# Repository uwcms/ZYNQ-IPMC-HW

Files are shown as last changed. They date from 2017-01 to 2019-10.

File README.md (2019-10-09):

! The ZYNQ-IPMC Software Framework resides [here](https://github.com/uwcms/IPMC).

# ZYNQ-IPMC Official Hardware Repository
Department of Physics, University of Wisconsin-Madison, USA

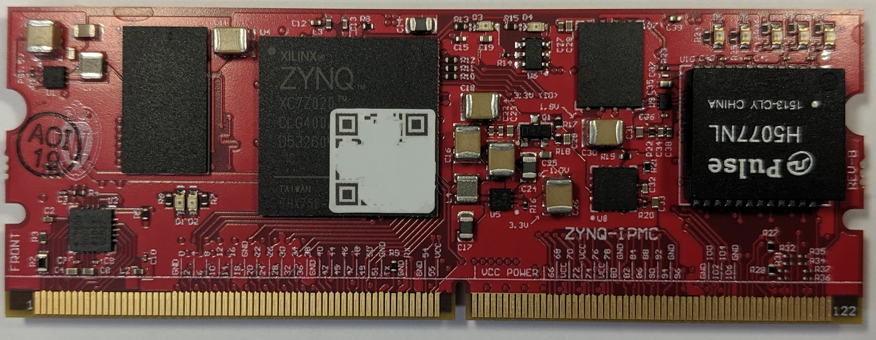
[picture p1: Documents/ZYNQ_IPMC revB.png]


<!-- TOC depthFrom:1 depthTo:6 withLinks:1 updateOnSave:1 orderedList:0 -->

- [ZYNQ-IPMC Official Hardware Repository](#zynq-ipmc-official-hardware-repository)
	- [1. Overview](#1-overview)
	- [2. Altium Symbol and Footprint Library](#2-altium-symbol-and-footprint-library)
	- [3. Picking between Zynq-7014S and Zynq-7020](#3-picking-between-zynq-7014s-and-zynq-7020)
	- [4. Bring-up and Testing](#4-bring-up-and-testing)
	- [5. Fabrication and Assembly](#5-fabrication-and-assembly)
		- [5.1. Fabrication Package](#51-fabrication-package)
		- [5.2. Assembly Package](#52-assembly-package)
	- [6. Disclaimer and Licensing](#6-disclaimer-and-licensing)

<!-- /TOC -->

## 1. Overview

ZYNQ-IPMC is a high versatile open-source self-contained Intelligent Platform
Management Controller (IPMC) in a miniDIMM-244 mezzanine form factor with
extended monitoring features targeted for Advance Telecommunications Computing
Architecture (ATCA) applications in accordance with the PICMG 3.x standard.

A Xilinx Zynq-7000 System-on-Chip (SoC) powers the ZYNQ-IPMC. Coupled with 256Mbytes of DDR3, fast
ADCs and a large number of GPIOs that can take any standard protocol natively,
forms an ideal solution to monitor and log voltages, currents, temperatures and others
metrics in ATCA applications.

**For detailed information of the hardware check the PDF datasheet
[here](Documents/ZYNQ-IPMC%20hw%20datasheet.pdf).**

## 2. Altium Symbol and Footprint Library

The Altium project with the ZYNQ-IPMC symbol and footprint can be found
[here](AltiumLib/).

## 3. Picking between Zynq-7014S and Zynq-7020

Both Zynq-7014S and Zynq-7020 are pin-compatible and can be assembled in the ZYNQ-IPMC.
The primary different is that the Zynq-7014S is a single core and has roughly
20% less resources than the Zynq-7020. The Zynq-7014S is also cheaper.

ZYNQ-IPMC framework only uses a single-core and won't benefit from an additional
core nor FPGA resources. Therefore, the Zynq-7014S is recommended for most applications.

From tests and experimentation a medium to high populated ZYNQ-IPMC solution requires
around 25% of resources from a Zynq-7020.

## 4. Bring-up and Testing

Standard electrical checks for hardware bring-up should be followed (e.g. visual
inspection, ohm-meter tests, voltage levels, etc.) before inserting the IPMC on a
carrier.

The [ZYNQ-IPMC Test Board](TestBoard) can be used for these tests and additional
connectivity tests.

## 5. Fabrication and Assembly

All files required to fabrication and assembly are included in this repository.
They can be found at [here](Project%20Outputs%20for%20ZYNQ_IPMC/revB1).

Recommendations on how to prepare packages for each fabrication step is below.

### 5.1. Fabrication Package

The following folders and files are recommended to be sent the PCB fabrication house:
 - Gerbers (either Gerber or GerberX2)
 - NC Drill
 - Test Points
 - PCB drawings (ZYNQ_IPMC-PCB.PDF)
 - Drill drawings (ZYNQ-IPMC-DrillDrawing.PDF)

### 5.2. Assembly Package

The following folders and files are recommended to be sent the assembly house:
 - Gerbers (either Gerber or GerberX2)
 - Bill of Materials (BOM)
 - Pick and Place
 - Assembly drawings (ZYNQ_IPMC-Assembly.PDF)

## 6. Disclaimer and Licensing

The project is distributed as-in under the MIT license agreement as seen [here](LICENSE.md).

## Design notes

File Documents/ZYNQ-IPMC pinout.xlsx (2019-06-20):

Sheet: Pin Assignment
Name | Pin | Pin | Name | Name | Pin | Pin | Name
GND | 1 | 123 | GND | VCC3.3 | 66 | 188 | GPIO_58 | Pin assignment as seen from the IPMC
+12V_SENSE | 2 | 124 | ADC-B_IN0 | VCC3.3 | 67 | 189 | GPIO_59
ADC-A_IN1 | 3 | 125 | ADC-B_IN1 | VCC3.3 | 68 | 190 | GND | Revision: | 1.1
GND | 4 | 126 | GND | VCC3.3 | 69 | 191 | GPIO_60
ADC-A_IN2 | 5 | 127 | ADC-B_IN2 | VCC3.3 | 70 | 192 | GPIO_61 | Bank 13
ADC-A_IN3 | 6 | 128 | ADC-B_IN3 | VCC3.3 | 71 | 193 | GND | Bank 34
ADC-A_IN4 | 7 | 129 | ADC-B_IN4 | VCC3.3 | 72 | 194 | GPIO_62 | Bank 35
ADC-A_IN5 | 8 | 130 | ADC-B_IN5 | VCC3.3 | 73 | 195 | GPIO_63
GND | 9 | 131 | GND | VCC3.3 | 74 | 196 | GND
ADC-A_IN6 | 10 | 132 | ADC-B_IN6 | VCC3.3 | 75 | 197 | GPIO_64
ADC-A_IN7 | 11 | 133 | ADC-B_IN7 | VCC3.3 | 76 | 198 | GPIO_65
GND | 12 | 134 | GND | VCC3.3 | 77 | 199 | GND
NC | 13 | 135 | NC | GPIO_66 | 78 | 200 | GPIO_67
NC | 14 | 136 | NC | GPIO_68 | 79 | 201 | GPIO_69
NC | 15 | 137 | NC | VCC3.3 | 80 | 202 | GND
NC | 16 | 138 | NC | GPIO_70 | 81 | 203 | GPIO_71
NC | 17 | 139 | NC | GPIO_72 | 82 | 204 | GPIO_73
NC | 18 | 140 | NC | VCC3.3 | 83 | 205 | GND
NC | 19 | 141 | NC | GPIO_74 | 84 | 206 | GPIO_75
NC | 20 | 142 | NC | GPIO_76 | 85 | 207 | GPIO_77
NC | 21 | 143 | NC | VCC3.3 | 86 | 208 | GND
NC | 22 | 144 | NC | GPIO_78 | 87 | 209 | GPIO_79
GND | 23 | 145 | GND | GPIO_80 | 88 | 210 | GPIO_81
GPIO_0 | 24 | 146 | GPIO_1 | GND | 89 | 211 | GND
GPIO_2 | 25 | 147 | GPIO_3 | GPIO_82 | 90 | 212 | GPIO_83
GPIO_4 | 26 | 148 | GPIO_5 | GPIO_84 | 91 | 213 | GPIO_85
GPIO_6 | 27 | 149 | GPIO_7 | GPIO_86 | 92 | 214 | GPIO_87
GPIO_8 | 28 | 150 | GPIO_9 | GPIO_88 | 93 | 215 | GPIO_89
GPIO_10 | 29 | 151 | GPIO_11 | GPIO_90 | 94 | 216 | GPIO_91
GPIO_12 | 30 | 152 | GPIO_13 | GPIO_92 | 95 | 217 | GPIO_93
GPIO_14 | 31 | 153 | GPIO_15 | GPIO_94 | 96 | 218 | GPIO_95
GPIO_16 | 32 | 154 | GPIO_17 | GND | 97 | 219 | GND
GPIO_18 | 33 | 155 | GPIO_19 | GPIO_96 | 98 | 220 | GPIO_97
GND | 34 | 156 | GND | NC | 99 | 221 | GPIO_98
GPIO_20 | 35 | 157 | GPIO_21 | NC | 100 | 222 | GND
GPIO_22 | 36 | 158 | GPIO_23 | NC | 101 | 223 | EXT_RST_N
GPIO_24 | 37 | 159 | GPIO_25 | GND | 102 | 224 | GPIO_99
GPIO_26 | 38 | 160 | GPIO_27 | GPIO_100 | 103 | 225 | GPIO_101
GPIO_28 | 39 | 161 | GPIO_29 | GPIO_102 | 104 | 226 | GPIO_103
GPIO_30 | 40 | 162 | GPIO_31 | GPIO_104 | 105 | 227 | GPIO_105
GPIO_32 | 41 | 163 | GPIO_33 | GPIO_106 | 106 | 228 | GPIO_107
GPIO_34 | 42 | 164 | GPIO_35 | GND | 107 | 229 | GPIO_108
GPIO_36 | 43 | 165 | GPIO_37 | M-JTAG_TRST | 108 | 230 | GND
GPIO_38 | 44 | 166 | GPIO_39 | M-JTAG_TDO | 109 | 231 | M-JTAG_TCK
GND | 45 | 167 | GND | M-JTAG_TMS | 110 | 232 | M-JTAG_TDI
GPIO_40 | 46 | 168 | GPIO_41 | GND | 111 | 233 | GND
GPIO_42 | 47 | 169 | GPIO_43 | Z-JTAG_TDO | 112 | 234 | Z-JTAG_TCK
GPIO_44 | 48 | 170 | GND | Z-JTAG_TMS | 113 | 235 | Z-JTAG_TDI
GPIO_45 | 49 | 171 | GB_A_P | GND | 114 | 236 | GND
GPIO_46 | 50 | 172 | GB_A_N | HA0 | 115 | 237 | HA1
GPIO_47 | 51 | 173 | GND | HA2 | 116 | 238 | HA3
GPIO_48 | 52 | 174 | GB_B_P | HA4 | 117 | 239 | HA5
GPIO_49 | 53 | 175 | GB_B_N | HA6 | 118 | 240 | HA7
GPIO_50 | 54 | 176 | GND | GND | 119 | 241 | GND
GPIO_51 | 55 | 177 | GB_C_P | IPMB-A_SCL | 120 | 242 | IPMB-B_SCL
GND | 56 | 178 | GB_C_N | IPMB-A_SDA | 121 | 243 | IPMB-B_SDA
UART_TX | 57 | 179 | GND | GND | 122 | 244 | GND
NC | 58 | 180 | GB_D_P
GND | 59 | 181 | GB_D_N
UART_RX | 60 | 182 | GND
NC | 61 | 183 | GPIO_52
GND | 62 | 184 | GPIO_53
GPIO_54 | 63 | 185 | GND
GPIO_55 | 64 | 186 | GPIO_56
VCC3.3 | 65 | 187 | GPIO_57

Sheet: GPIOs
GPIO Number | GPIO Pin | Bank | Zynq Pin | Clock input | GPIO | Pin
0 | 24 | 13 | U5 | - | 0 | 0
1 | 146 | 34 | P14 | - | 0 | 1
2 | 25 | 13 | T5 | - | 0 | 2
3 | 147 | 34 | T10 | - | 0 | 3
4 | 26 | 13 | U8 | - | 0 | 4
5 | 148 | 34 | T11 | - | 0 | 5
6 | 27 | 13 | U9 | - | 0 | 6
7 | 149 | 34 | T12 | - | 0 | 7
8 | 28 | 13 | W8 | - | 0 | 8
9 | 150 | 34 | T14 | - | 0 | 9
10 | 29 | 13 | W9 | - | 0 | 10
11 | 151 | 34 | U12 | - | 0 | 11
12 | 30 | 13 | W10 | - | 0 | 12
13 | 152 | 34 | T15 | - | 0 | 13
14 | 31 | 13 | W11 | - | 0 | 14
15 | 153 | 34 | V12 | - | 0 | 15
16 | 32 | 13 | Y11 | - | 0 | 16
17 | 154 | 34 | W13 | - | 0 | 17
18 | 33 | 13 | Y12 | - | 0 | 18
19 | 155 | 34 | V13 | - | 0 | 19
20 | 35 | 34 | R14 | - | 0 | 20
21 | 157 | 34 | W18 | - | 0 | 21
22 | 36 | 34 | W15 | - | 0 | 22
23 | 158 | 34 | V16 | - | 0 | 23
24 | 37 | 34 | T16 | - | 0 | 24
25 | 159 | 34 | T17 | - | 0 | 25
26 | 38 | 34 | U17 | - | 0 | 26
27 | 160 | 34 | Y18 | - | 0 | 27
28 | 39 | 34 | Y14 | - | 0 | 28
29 | 161 | 34 | W16 | - | 0 | 29
30 | 40 | 34 | W14 | - | 0 | 30
31 | 162 | 34 | V17 | - | 0 | 31
32 | 41 | 34 | U14 | Limited | 1 | 0
33 | 163 | 34 | W19 | - | 1 | 1
34 | 42 | 34 | Y16 | - | 1 | 2
35 | 164 | 34 | Y19 | - | 1 | 3
36 | 43 | 34 | V15 | - | 1 | 4
37 | 165 | 34 | V18 | - | 1 | 5
38 | 44 | 34 | Y17 | - | 1 | 6
39 | 166 | 34 | W20 | - | 1 | 7
40 | 46 | 34 | U15 | Limited | 1 | 8
41 | 168 | 13 | W6 | - | 1 | 9
42 | 47 | 34 | U18 | Yes | 1 | 10
43 | 169 | 13 | V6 | - | 1 | 11
44 | 48 | 34 | P19 | Yes | 1 | 12
45 | 49 | 34 | N18 | Yes | 1 | 13
46 | 50 | 34 | N20 | Limited | 1 | 14
47 | 51 | 34 | U19 | Yes | 1 | 15
48 | 52 | 34 | P20 | Limited | 1 | 16
49 | 53 | 34 | V20 | - | 1 | 17
50 | 54 | 34 | U20 | - | 1 | 18
51 | 55 | 34 | T20 | - | 1 | 19
52 | 183 | 13 | V10 | - | 1 | 20
53 | 184 | 13 | V11 | - | 1 | 21
54 | 63 | 13 | Y13 | - | 1 | 22
55 | 64 | 34 | R16 | - | 1 | 23
56 | 186 | 34 | R17 | - | 1 | 24
57 | 187 | 34 | R18 | - | 1 | 25
58 | 188 | 34 | N17 | - | 1 | 26
59 | 189 | 34 | P18 | - | 1 | 27
60 | 191 | 34 | P15 | - | 1 | 28
61 | 192 | 34 | P16 | - | 1 | 29
62 | 194 | 34 | T19 | - | 1 | 30
63 | 195 | 34 | R19 | - | 1 | 31
64 | 197 | 35 | N15 | - | 2 | 0
65 | 198 | 35 | N16 | - | 2 | 1
66 | 78 | 35 | M14 | - | 2 | 2
67 | 200 | 35 | M15 | - | 2 | 3
68 | 79 | 35 | M17 | - | 2 | 4
69 | 201 | 35 | M18 | - | 2 | 5
70 | 81 | 35 | M19 | - | 2 | 6
71 | 203 | 35 | M20 | - | 2 | 7
72 | 82 | 35 | L14 | - | 2 | 8
73 | 204 | 35 | L15 | - | 2 | 9
74 | 84 | 35 | L16 | Limited | 2 | 10
75 | 206 | 35 | L17 | Limited | 2 | 11
76 | 85 | 35 | L20 | - | 2 | 12
77 | 207 | 35 | L19 | - | 2 | 13
78 | 87 | 35 | K14 | - | 2 | 14
79 | 209 | 35 | J14 | - | 2 | 15
80 | 88 | 35 | K17 | Yes | 2 | 16
81 | 210 | 35 | K16 | - | 2 | 17
82 | 90 | 35 | K18 | Yes | 2 | 18
83 | 212 | 35 | G14 | - | 2 | 19
84 | 91 | 35 | J19 | - | 2 | 20
85 | 213 | 35 | K19 | - | 2 | 21
86 | 92 | 35 | J16 | - | 2 | 22
87 | 214 | 35 | J15 | - | 2 | 23
88 | 93 | 35 | J20 | - | 2 | 24
89 | 215 | 35 | H20 | - | 2 | 25
90 | 94 | 35 | J18 | - | 2 | 26
91 | 216 | 35 | H18 | - | 2 | 27
92 | 95 | 35 | H17 | Yes | 2 | 28
93 | 217 | 35 | H16 | Yes | 2 | 29
94 | 96 | 35 | H15 | - | 2 | 30
95 | 218 | 35 | G15 | - | 2 | 31
96 | 98 | 35 | G17 | - | 3 | 0
97 | 220 | 35 | G18 | - | 3 | 1
98 | 221 | 35 | G19 | - | 3 | 2
99 | 224 | 35 | G20 | - | 3 | 3
100 | 103 | 35 | F16 | - | 3 | 4
101 | 225 | 35 | F20 | - | 3 | 5
102 | 104 | 35 | F17 | - | 3 | 6
103 | 226 | 35 | E18 | - | 3 | 7
104 | 105 | 35 | D18 | - | 3 | 8
105 | 227 | 35 | E19 | - | 3 | 9
106 | 106 | 35 | D19 | - | 3 | 10
107 | 228 | 35 | F19 | - | 3 | 11
108 | 229 | 35 | D20 | - | 3 | 12

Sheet: Mapping
GPIO Number | GPIO Pin | Bank | Zynq Pin | Clock input | GPIO Number | GPIO Pin | Bank | Zynq Pin | Clock input
0 | 24 | 13 | U5 | - | 55 | 64 | 34 | R16 | -
1 | 146 | 34 | P14 | - | 56 | 186 | 34 | R17 | -
2 | 25 | 13 | T5 | - | 57 | 187 | 34 | R18 | -
3 | 147 | 34 | T10 | - | 58 | 188 | 34 | N17 | -
4 | 26 | 13 | U8 | - | 59 | 189 | 34 | P18 | -
5 | 148 | 34 | T11 | - | 60 | 191 | 34 | P15 | -
6 | 27 | 13 | U9 | - | 61 | 192 | 34 | P16 | -
7 | 149 | 34 | T12 | - | 62 | 194 | 34 | T19 | -
8 | 28 | 13 | W8 | - | 63 | 195 | 34 | R19 | -
9 | 150 | 34 | T14 | - | 64 | 197 | 35 | N15 | -
10 | 29 | 13 | W9 | - | 65 | 198 | 35 | N16 | -
11 | 151 | 34 | U12 | - | 66 | 78 | 35 | M14 | -
12 | 30 | 13 | W10 | - | 67 | 200 | 35 | M15 | -
13 | 152 | 34 | T15 | - | 68 | 79 | 35 | M17 | -
14 | 31 | 13 | W11 | - | 69 | 201 | 35 | M18 | -
15 | 153 | 34 | V12 | - | 70 | 81 | 35 | M19 | -
16 | 32 | 13 | Y11 | - | 71 | 203 | 35 | M20 | -
17 | 154 | 34 | W13 | - | 72 | 82 | 35 | L14 | -
18 | 33 | 13 | Y12 | - | 73 | 204 | 35 | L15 | -
19 | 155 | 34 | V13 | - | 74 | 84 | 35 | L16 | Limited
20 | 35 | 34 | R14 | - | 75 | 206 | 35 | L17 | Limited
21 | 157 | 34 | W18 | - | 76 | 85 | 35 | L20 | -
22 | 36 | 34 | W15 | - | 77 | 207 | 35 | L19 | -
23 | 158 | 34 | V16 | - | 78 | 87 | 35 | K14 | -
24 | 37 | 34 | T16 | - | 79 | 209 | 35 | J14 | -
25 | 159 | 34 | T17 | - | 80 | 88 | 35 | K17 | Yes
26 | 38 | 34 | U17 | - | 81 | 210 | 35 | K16 | -
27 | 160 | 34 | Y18 | - | 82 | 90 | 35 | K18 | Yes
28 | 39 | 34 | Y14 | - | 83 | 212 | 35 | G14 | -
29 | 161 | 34 | W16 | - | 84 | 91 | 35 | J19 | -
30 | 40 | 34 | W14 | - | 85 | 213 | 35 | K19 | -
31 | 162 | 34 | V17 | - | 86 | 92 | 35 | J16 | -
32 | 41 | 34 | U14 | Limited | 87 | 214 | 35 | J15 | -
33 | 163 | 34 | W19 | - | 88 | 93 | 35 | J20 | -
34 | 42 | 34 | Y16 | - | 89 | 215 | 35 | H20 | -
35 | 164 | 34 | Y19 | - | 90 | 94 | 35 | J18 | -
36 | 43 | 34 | V15 | - | 91 | 216 | 35 | H18 | -
37 | 165 | 34 | V18 | - | 92 | 95 | 35 | H17 | Yes
38 | 44 | 34 | Y17 | - | 93 | 217 | 35 | H16 | Yes
39 | 166 | 34 | W20 | - | 94 | 96 | 35 | H15 | -
40 | 46 | 34 | U15 | Limited | 95 | 218 | 35 | G15 | -
41 | 168 | 13 | W6 | - | 96 | 98 | 35 | G17 | -
42 | 47 | 34 | U18 | Yes | 97 | 220 | 35 | G18 | -
43 | 169 | 13 | V6 | - | 98 | 221 | 35 | G19 | -
44 | 48 | 34 | P19 | Yes | 99 | 224 | 35 | G20 | -
45 | 49 | 34 | N18 | Yes | 100 | 103 | 35 | F16 | -
46 | 50 | 34 | N20 | Limited | 101 | 225 | 35 | F20 | -
47 | 51 | 34 | U19 | Yes | 102 | 104 | 35 | F17 | -
48 | 52 | 34 | P20 | Limited | 103 | 226 | 35 | E18 | -
49 | 53 | 34 | V20 | - | 104 | 105 | 35 | D18 | -
50 | 54 | 34 | U20 | - | 105 | 227 | 35 | E19 | -
51 | 55 | 34 | T20 | - | 106 | 106 | 35 | D19 | -
52 | 183 | 13 | V10 | - | 107 | 228 | 35 | F19 | -
53 | 184 | 13 | V11 | - | 108 | 229 | 35 | D20 | -
54 | 63 | 13 | Y13 | -
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

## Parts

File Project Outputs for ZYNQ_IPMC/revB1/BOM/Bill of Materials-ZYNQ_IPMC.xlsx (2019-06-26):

Comment | Quantity | Designator | Manufacturer | Part | Footprint | Value | Rating | Tolerance | Rated Current | INVKEY | Note | Description
? | 12 | C1, C11, C16, C18, C20, C26, C30, C61, C64, C65, C67, C68 | Murata | GRM32ER60J107ME20L | C1210_IPC_H | 100uF | 6.3V |  |  | CP1210-100UF-6.3V-20% |  | Capacitor
? | 2 | C2, C32 | Murata | GRM155R71C473KA01D | C0402_IPC_H | 47nF | 16V |  |  | CP0402-47nf-16V-10% |  | Capacitor
? | 34 | C3, C7, C9, C10, C36, C37, C40, C41, C43, C45, C118, C119, C120, C121, C122, C123, C124, C125, C126, C129, C130, C131, C132, C133, C134, C135, C136, C137, C138, C140, C142, C143, C144, C149 | Murata | GRM033R60J104KE19D | C0201_IPC_H | 0.1uF | 6.3V |  |  | CP0201-0.1UF-6.3V-10% |  | Capacitor
? | 22 | C4, C5, C8, C19, C23, C25, C28, C29, C31, C33, C58, C59, C63, C109, C127, C128, C139, C141, C145, C146, C147, C148 | Murata | GRM155R60J106ME44D | C0402_IPC_H | 10uF | 6.3V |  |  | CP0402-10UF-6V3-20% |  | Capacitor
? | 5 | C6, C14, C17, C24, C74 | TDK | C2012X5R0J476M125AC | C0805_M | 47uF | 6.3V |  |  | CP0805-47UF-6.3V |  | Capacitor
? | 20 | C12, C15, C27, C34, C38, C39, C48, C49, C51, C52, C53, C57, C60, C62, C66, C91, C95, C110, C111, C117 | Murata | GRM155R71C104KA88D | C0402_IPC_H | 0.1uF | 16V |  |  | CP0402-0.1UF-16V-10% |  | Capacitor
? | 30 | C13, C21, C22, C69, C72, C73, C76, C78, C79, C81, C83, C85, C86, C88, C89, C92, C93, C96, C97, C98, C99, C100, C102, C103, C106, C108, C112, C113, C114, C116 | Murata | GRM155R60J474KE19D | C0402_IPC_H | 0.47uF | 6.3V |  |  | CP0402-0.47UF-6V3-10% |  | Capacitor
? | 3 | C35, C50, C54 | AVX | 0402YD475MAT2A | C0402_IPC_H | 4.7uF | 16V |  |  | CP0402-4.7uf-16V-20% |  | Capacitor
? | 3 | C42, C44, C46 | TDK | C0603X7R1E471K030BA | C0201_IPC_H | 470pF | 25V |  |  | CP0201-470PF-25V-10% |  | Capacitor
? | 1 | C47 | Murata | GRM155R72A102KA01D | C0402_IPC_H | 1000pF | 100V |  |  | CP0402-1000PF-100V-10% |  | Capacitor
? | 2 | C55, C56 | Murata | GJM0335C0J270JB01D | C0201_IPC_H | 27pF | 6.3V |  |  | CP0201-27PF-6V3-5% |  | Capacitor
? | 15 | C70, C71, C75, C77, C80, C82, C84, C87, C90, C94, C101, C104, C105, C107, C115 | TDK | C1005X5R0J475M050BC | C0402_IPC_H | 4.7uF | 6.3V |  |  | CP0402-4.7UF-6.3V |  | Capacitor
? | 3 | D1, D3, D9 | Lite-On | LTST-C190KRKT | LED0603_M | RED |  |  |  | LED-RD-TOP-0603 |  | Light Emitting Diode
? | 3 | D2, D4, D7 | Lite-On | LTST-C190KSKT | LED0603_M | YELLOW |  |  |  | LED-YLW-TOP-0603 |  | Light Emitting Diode
? | 3 | D5, D6, D8 | Lite-On | LTST-C190KGKT | LED0603_M | GREEN |  |  |  | LED-GN-TOP-0603 |  | Light Emitting Diode
MINIDIMM244 | 1 | J1 |  |  | miniDIMM244 |  |  |  |  |  | NOT A PART | 244-pin miniDIMM pads
DFE252012F-R47M=P2 | 2 | L1, L4 | Murata | DFE252012F-R47M=P2 | L2520_H | 0.47uH |  | 20% |  | IND-DFE2520102F |  | Inductor
BK1005HM241-T | 6 | L2, L3, L5, L6, L8, L9 | Taiyo Yuden | BK1005HM241-T | L0402_H | 240 |  |  | 300mA | FB-BK1005HM241-T |  | Bead Inductor
Wurth 74438323047 | 1 | L7 | Wurth | 74438323047 | L2520_H | 4.7uH |  | 20% |  | IND-74438323047 |  | Inductor
NTR2101P | 1 | Q1 | On Semiconductor | NTR2101P | SOT23-H |  |  |  |  | MOS-NTR2101P-SOT23 |  | Small Signal MOSFET, −8.0V, −3.7 A, Single P−Channel, SOT−23
NDS331N | 2 | Q2, Q3 | Fairchild | NDS331N | SOT23-H |  |  |  |  | FET-NDS331N-SSOT23 |  | N-Channel Logic Level Enhancement Mode Field Effect Transistor
? | 24 | R1, R14, R16, R20, R23, R29, R30, R31, R32, R34, R35, R36, R37, R40, R41, R42, R43, R44, R45, R46, R47, R50, R51, R73 | Panasonic | ERJ-1GNF1002C | R0201_IPC_H | 10K |  | 1% |  | RS0201-10K-1/20W-1% |  | Resistor
? | 1 | R2 | Susumu Co Ltd | RG1608P-4641-B-T1 | R0603 | 4.64K |  | 0.1% |  | RS0603-4K64-1/10W-PREC |  | Resistor
? | 1 | R3 | Vishay | TNPW04021K00BEED | R0402_IPC_H | 1K |  | 0.1% |  | RS0402-1K-1/16W-PREC |  | Resistor
? | 13 | R4, R5, R62, R65, R71, R76, R79, R80, R82, R84, R108, R115, R117 | Panasonic | ERJ-2RKF4701X | R0402_IPC_H | 4.7K |  | 1% |  | RS0402-4K7-1/10W-1% |  | Resistor
? | 7 | R6, R7, R24, R25, R26, R33, R38 | Panasonic-ECG | ERJ-2RKF5100X | R0402_IPC_H | 510 |  | 1% |  | RS0402-510R-1/10W-1% |  | Resistor
? | 3 | R8, R17, R78 | Panasonic-ECG | ERJ-2RKF1001X | R0402_IPC_H | 1K |  | 1% |  | RS0402-1K-1/10W-1% |  | Resistor
? | 7 | R9, R10, R11, R12, R27, R75, R85 | Panasonic | ERJ-2RKF49R9X | R0402_IPC_H | 49.9 |  | 1% |  | RS0402-49R9-1/10W-1% |  | Resistor
? | 2 | R13, R15 | Panasonic-ECG | ERJ-2RKF2000X | R0402_IPC_H | 200 |  | 1% |  | RS0402-200R-1/10W-1% |  | Resistor
? | 1 | R18 | Panasonic | ERJ-2RKF2402X | R0402_IPC_H | 24K |  | 1% |  | RS0402-24K-1/10W-1% |  | Resistor
? | 1 | R19 | Panasonic | ERA-2AEB5762X | R0402_IPC_H | 57.6K |  | 0.1% |  | R0402-57K6-1/16W-PREC |  | Resistor
? | 2 | R21, R72 | Panasonic | ERA-2AEB2212X | R0402_IPC_H | 22.1K |  | 0.1% |  | RS0402-22K1-1/16W-PREC |  | Resistor
? | 11 | R22, R28, R49, R52, R53, R56, R57, R59, R60, R61, R64 | Panasonic-ECG | ERJ-2GEJ103X | R0402_IPC_H | 10K |  | 5% |  | RS0402-10K-1/10W-5% |  | Resistor
? | 4 | R39, R48, R54, R58 | Panasonic | ERJ-2RKF75R0X | R0402_IPC_H | 75 |  | 1% |  | RS0402-75R-1/10W-1% |  | Resistor
? | 3 | R55, R116, R119 | Panasonic | ERJ-2RKF2371X | R0402_IPC_H | 2.37K |  | 1% |  | RS0402-2K37-1/10W-1% |  | Resistor
? | 2 | R63, R77 | Panasonic | ERJ-1GNF22R0C | R0201_IPC_H | 22 |  | 1% |  | RS0201-22R-1/20W-1% |  | Resistor
? | 7 | R66, R67, R68, R69, R70, R81, R83 | Panasonic-ECG | ERJ-2RKF2002X | R0402_IPC_H | 20K |  | 1% |  | RS0402-20K-1/10W-1% |  | Resistor
? | 1 | R74 | Panasonic-ECG | ERA-2AEB8662X | R0402_IPC_H | 86.6K |  | 0.1% |  | RS0402-86K6-1/16W-PREC |  | Resistor
? | 3 | R86, R87, R94 | Panasonic-ECG | ERJ-2RKF80R6X | R0402_IPC_H | 80.6 |  | 1% |  | RS0402-80R6-1/10W-1% |  | Resistor
? | 1 | R88 | Panasonic-ECG | ERJ-2RKF2400X | R0402_IPC_H | 240 |  | 1% |  | RS0402-240R-1/10W-1% |  | Resistor
? | 23 | R89, R90, R91, R92, R93, R95, R96, R97, R98, R100, R101, R102, R103, R104, R105, R106, R107, R109, R110, R111, R112, R113, R114 | Panasonic-ECG | ERJ-1GEF40R2C | R0201_IPC_H | 40.2 |  | 1% |  | RS0201-40R2-1/20W-1% |  | Resistor
? | 1 | R99 | Panasonic-ECG | ERJ-2GE0R00X | R0402_IPC_H | 0 |  | 5% |  | RS0402-0R-1/10W-5% |  | Resistor
? | 1 | R118 | Panasonic | ERA-2AEB4122X | R0402_IPC_H | 41.2K |  | 0.1% |  | RS0402-41K2-1/16W-PREC |  | Resistor
? | 1 | R120 | Panasonic | ERA-2AEB473X | R0402_IPC_H | 47K |  | 0.1% |  | RS0402-47K-1/16W-PREC |  | Resistor
TPS62085 | 2 | U1, U5 | Texas Instruments | TPS62085 | VSON-8_L |  |  |  |  | IC-TPS62085 |  | 3-A Step-Down Converter With Hiccup Short-Circuit Protection
AD7689BCPZ | 2 | U2, U14 | Analog | AD7689BCPZ | CP-20-4_N |  |  |  |  | IC-ADC-AD7689BCPZ |  | Octal 16-Bit PulSAR Analog-to-Digital Converter with Serial, SPI Interface, 250KSPS, -40 to +85 degC, CP-20-4, Pb-Free, Tube
MT41J128M16JT-96 | 1 | U3 | Micron | MT41J128M16JT-125 | MICT-JT-96 |  |  |  |  | IC-DRAM-MT41J-2GB-JT | Any speed grade will work
XNLX-XC7Z014S-CLG400 | 1 | U4 | Xilinx | XC7Z014S-1CLG400C | CLG400 |  |  |  |  | ?
25AA02E48T-I/OT | 1 | U6 | Microchip | 25AA02E48T-I/OT | SOT-23-OT6_L |  |  |  |  | IC-EEPROM-2K-SSPI-SOT23 |  | 2K SPI Bus Serial EEPROM with EUI-48 Node Identity, 6-Pin SOT-23, Industrial Temperature, Tape and Reel
MX66L51235F | 1 | U7 | Macronix | MX66L51235FZ2I-10G | SON127P800X80_HS-9_N |  |  |  |  | ? |  | 3V, 512M-bit [x1/x2/x4], CMOS MXSMIO (serial multi I/O) Flash Memory
ADP1755ACPZ-R7 | 1 | U8 | Analog | ADP1755ACPZ-R7 | CP-16-4_L |  |  |  |  | IC-REG-ADP1755ACPZ |  | 1.2 A, Low VIN, Low Dropout Linear Regulator, 1.6 to 3.6 V Vin, 0.75 to 3 V Vout, Industrial, 16-pin QFN (CP-16-4), Reel
TXS0102 | 1 | U9 | Texas Instruments | TXS0102DQER | X2SON-8_H |  |  |  |  | IC-TXS0102DQER |  | 2-Bit Bidirectional Voltage-Level Translator for Open-Drain and Push-Pull Applications
H5077NL | 1 | U10 | Pulse Electronics | H5077NL | H5077NL |  |  |  |  | IC-XFRM-MINIMAG-1000BASE-T |  | 1000Base-T, Single Port Mini-Magnetics Modules
AR8035 | 1 | U11 | Atheros | AR8035 | QFN40_H |  |  |  |  | IC-TXRX-AR8035 |  | Integrated 10/100/1000 Gigabit Ethernet Transceiver
25AA256-I/ST | 1 | U12 | Microchip | 25AA256-I/ST | TSSOP-ST8_L |  |  |  |  | IC-EEPROM-256K |  | 256K SPI Bus Serial EEPROM, 8-Pin TSSOP, Industrial Temperature
DS1818 | 1 | U13 | Maxim | DS1818R-10 | SOT23-H |  |  |  |  | IC-RST-1818R-10 |  | 3.3V EconoReset with Pushbutton
TPS51200DRCR | 1 | U15 | Texas Instruments | TPS51200DRCR | DRC0010J_V |  | Catalog |  |  | IC-DDRTERM-REG-PPSON10 |  | Single Output LDO, 3 A, 2.375 to 3.5 V Input, with DDR Termination, 10-pin SON (DRC), -40 to 85 degC, Green (RoHS & no Sb/Br)
XRCGB25M000F3M00R0 | 1 | X1 | Murata | XRCGB25M000F3M00R0 | XRCGB_F | 25MHz |  |  |  | CRY-XRCGB-25.0000MHZ |  | Standard Crystal Oscillator
ASDMB-33.333MHZ-LY-T | 1 | Y1 | Abracon | ASDMB-33.333MHZ-LY | ABRA-ASDMB-4_V |  |  |  |  | CRY-ASDMB-33.333MHZ |  | Plastic Package Clock Oscillator, 3.6864 MHz Frequency, 15 pF Output Load, 4-Pin 2.5 x 2 x 0.9 mm SMD, -40 to 85 degC, RoHS, Reel

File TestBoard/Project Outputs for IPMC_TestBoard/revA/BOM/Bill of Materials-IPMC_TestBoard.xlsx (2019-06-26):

Comment | Quantity | Designator | Mfgr | Mfg. Part No. | Footprint | Value | Rating | Tolerance | INVKEY | Note
? | 6 | C1, C3, C4, C11, C12, C13 | Yageo | CC0402JRNPO9BN470 | C0402 | 47pF | 50V |  | CP0402-47PF-50V-5%
? | 3 | C2, C7, C10 | Murata | GRM32ER60J107ME20L | C1210_IPC_H | 100uF | 6.3V |  | CP1210-100UF-6.3V-20%
? | 3 | C5, C8, C9 | Kemet | A700X157M006ATE015 | VISH-293D-7343-31_V | 150uF | 6.3V |  | CP7343-150uF-6.3V-ESR15-20%
? | 1 | C6 | Panasonic-ECJ | ECJ-0EB1A473K | C0402_IPC_H | 47nF | 10V |  | CP0402-47NF-10V-10%
BLUE | 6 | D1, D4, D7, D8, D9, D10 | Lite-On | LTST-S270TBKT | LED0603_M | BLUE |  |  | LED-BL-RA-0603
GREEN | 3 | D2, D5, D11 | Lite-On | LTST-S270KGKT | LED0603_M | GREEN |  |  | LED-GRN-RA-UB-0603
OPEN | 2 | D3, D6 | NA | NA | LED0603_M | OPEN |  |  | ? | Do not assemble
Ethernet Jack, CTRL ETH | 2 | J1, J9 | Molex | 43202-8916 | 43202-8916 |  |  |  | CO-43202-8916
MOLEX105017-0001 | 2 | J2, J10 | Molex | 105017-0001 | MOLEX105017-0001 |  |  |  | CO-USB-MICRO-SOLDERTAIL
MMC | 2 | J3, J4 | TE Connectivity | 5120527-1 | 5120527-1 |  |  |  | CO-PMC64-120527-1
IPMC, CTRL | 2 | J5, J7 | Molex | 87782-3007 | 87782-3007 |  |  |  | ? | Compatible with Molex 87782-3003, 87782-3005, 87782-3007 and 87782-3009
IPMI JTAG, CTRL JTAG | 2 | J6, J8 | Molex | 87832-1420 | 87832-1420 |  |  |  | CO-PIN-HDR-2X7SS-2MM
Header 20X2, CTRL GPIO | 2 | P1, P9 | ? | ? | HEADER2X20 |  |  |  | ? | Do not assemble
MMC1 CTRL, MMC0 CTRL | 2 | P2, P3 | ? | ? | HEADER1X7 |  |  |  | ? | Do not assemble
JTAG Connect, IPMC XVC to CTRL JTAG | 2 | P4, P5 | ? | ? | HEADER2X4 |  |  |  | ?
CTRL ADC-A, CTRL ADC-B | 2 | P6, P8 | ? | ? | HEADER1X9 |  |  |  | ? | Do not assemble
PWREN | 1 | P7 | ? | ? | HEADER1X3 |  |  |  | ?
UWLVPWRMODV2-PAR | 1 | PM1 | University of Wisconsin | UWLVPWRMODV2 | UWLVPWRMODV2 |  |  |  | ? | Refurbish from oRSCs
? | 9 | R1, R2, R4, R5, R12, R18, R20, R22, R24 | Yageo | RC0603FR-07681RL | R0603 | 681 |  | 1% | RS0603-681R-1/10W-1%
? | 6 | R3, R6, R13, R14, R15, R16 | NA | NA | R0402_IPC_H | OPEN |  | 1% | RS0402-OPEN-1/10W | Do not assemble
? | 4 | R7, R8, R31, R32 | ? | ? | R0603 | 27 |  |  | ?
? | 2 | R9, R30 | Panasonic-ECG | ERJ-2GEJ472X | R0402_IPC_H | 4.7K |  | 5% | RS0402-4K7-1/10W-5%
? | 6 | R10, R17, R19, R25, R26, R28 | Panasonic-ECG | ERJ-2GEJ103X | R0402_IPC_H | 10k |  | 5% | RS0402-10K-1/10W-5%
? | 4 | R11, R21, R27, R29 | Yageo | RC0603FR-07100RL | R0603 | 100 |  |  | RS0603-100R-1/10W-1%
? | 1 | R23 | ? | ? | R0402_IPC_H | 332 |  | 1% | ?
? | 1 | R33 | Panasonic-ECG | ERA-2AEB4531X | R0402 | 4.53k |  | 0.1% | RS0402-4K53-1/16W-PREC
? | 1 | R34 | Panasonic-ECG | ERJ-2RKF26R1X | R0402 | 26.1 |  | 1% | RS0402-26R1-1/10W-1%
SW-DIP-8 | 3 | SW1, SW2, SW4 | C&K | TDA08HOSB1 | TDA08H0 |  |  |  | SW-DIP-8X-SMD
DTSM-61NT/R | 2 | SW3, SW5 | ? | ? | DIPT-DTSM-6_V |  |  |  | ?
TP | 1 | TP1 | NA | NA | TP |  |  |  | NA | Not a part
FT234XD-T | 2 | U1, U3 | ? | ? | DFN-12_V |  |  |  | ?
ADR5040 | 1 | U2 | Analog Devices | ADR5040ARTZ | SOT23-H |  |  |  | VREF-ADR5040A-SOT23

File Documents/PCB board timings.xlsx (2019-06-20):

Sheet: Pin delays - All
#Top: | design_1_wrapper |  |  | Floorplan: | synth_1 |  |  |  | Part: | xc7z020clg400-1
#Generated | by: | mpvl |  |  | on: |  | Tue | Jan | 24 | 14:12:45 | 2017
#Build: | Vivado | v2016.1 |  |  | by: |  | xbuild |  |  | on: | Fri | Apr |  | 8 | 15:45:23 | MDT | 2016
IO | Bank | Pin | Number | Site | Site | Average | Type | Min | Trace | Delay | (ps) | Max | Trace | Delay | (ps) | Prohibit | Interface | Signal | Name | Direction | DiffPair | Type | DiffPair | Signal | IO | Standard | Drive | (mA) | Slew | Rate | OUTPUT_IMPEDANCE | PRE_EMPHASIS | LVDS_PRE_EMPHASIS | Pull | Type | DQS_BIAS | IN_TERM | DIFF_TERM | OFFCHIP_TERM | Board | Signal | Board | Voltage
0 | L10 | IPAD_X0Y1 | VN_0 | 106.858 | 107.932 | 107.395
0 | K9 | IPAD_X0Y0 | VP_0 | 116.667 | 117.839 | 117.253
0 | R11 |  | DONE_0 | 30.799 | 31.109 | 30.954
0 | M9 |  | DXP_0 | 106.4 | 107.47 | 106.935
0 | J10 |  | GNDADC_0 |  |  | #DIV/0!
0 | J9 |  | VCCADC_0 |  |  | #DIV/0!
0 | L9 |  | VREFP_0 | 87.688 | 88.569 | 88.1285
0 | F11 |  | VCCBATT_0 |  |  | #DIV/0!
0 | F9 |  | TCK_0 | 57.874 | 58.456 | 58.165
0 | M10 |  | DXN_0 | 133.776 | 135.12 | 134.448
0 | K10 |  | VREFN_0 | 81.391 | 82.209 | 81.8
0 | R10 |  | INIT_B_0 | 70.093 | 70.797 | 70.445
0 | G6 |  | TDI_0 | 174.211 | 175.961 | 175.086
0 | F6 |  | TDO_0 | 169.945 | 171.653 | 170.799
0 | M6 |  | CFGBVS_0 | 83.683 | 84.524 | 84.1035 |  |  |  |  |  |  |  |  |  |  |  |  |  |  |  |  |  | CFGBVS_0
0 | L6 |  | PROGRAM_B_0 | 107.335 | 108.413 | 107.874
0 | J6 |  | TMS_0 | 126.57 | 127.842 | 127.206
0 | K6 |  | VCCO_0 |  |  | #DIV/0! |  |  |  |  |  |  |  |  |  |  |  |  |  |  |  |  |  | VCCO_0
13 | V5 | IOB_X0Y37 | IO_L6N_T0_VREF_13 | 79.988 | 80.792 | 80.39
13 | U7 | IOB_X0Y28 | IO_L11P_T1_SRCC_13 | 167.883 | 169.571 | 168.727
13 | V7 | IOB_X0Y27 | IO_L11N_T1_SRCC_13 | 160.605 | 162.219 | 161.412
13 | T9 | IOB_X0Y26 | IO_L12P_T1_MRCC_13 | 99.733 | 100.735 | 100.234
13 | U10 | IOB_X0Y25 | IO_L12N_T1_MRCC_13 | 102.088 | 103.114 | 102.601
13 | Y7 | IOB_X0Y24 | IO_L13P_T2_MRCC_13 | 107.93 | 109.014 | 108.472
13 | Y6 | IOB_X0Y23 | IO_L13N_T2_MRCC_13 | 93.725 | 94.667 | 94.196
13 | Y9 | IOB_X0Y22 | IO_L14P_T2_SRCC_13 | 140.186 | 141.594 | 140.89
13 | Y8 | IOB_X0Y21 | IO_L14N_T2_SRCC_13 | 123.534 | 124.776 | 124.155
13 | V8 | IOB_X0Y20 | IO_L15P_T2_DQS_13 | 161.519 | 163.143 | 162.331
13 | W8 | IOB_X0Y19 | IO_L15N_T2_DQS_13 | 161.684 | 163.308 | 162.496
13 | W10 | IOB_X0Y18 | IO_L16P_T2_13 | 128.515 | 129.807 | 129.161
13 | W9 | IOB_X0Y17 | IO_L16N_T2_13 | 111.029 | 112.145 | 111.587
13 | U9 | IOB_X0Y16 | IO_L17P_T2_13 | 134.582 | 135.934 | 135.258
13 | U8 | IOB_X0Y15 | IO_L17N_T2_13 | 113.811 | 114.955 | 114.383
13 | W11 | IOB_X0Y14 | IO_L18P_T2_13 | 124.66 | 125.912 | 125.286
13 | Y11 | IOB_X0Y13 | IO_L18N_T2_13 | 128.126 | 129.414 | 128.77
13 | T5 | IOB_X0Y12 | IO_L19P_T3_13 | 110.454 | 111.564 | 111.009
13 | U5 | IOB_X0Y11 | IO_L19N_T3_VREF_13 | 53.322 | 53.858 | 53.59
13 | Y12 | IOB_X0Y10 | IO_L20P_T3_13 | 141.8 | 143.226 | 142.513
13 | Y13 | IOB_X0Y9 | IO_L20N_T3_13 | 143.139 | 144.577 | 143.858
13 | V11 | IOB_X0Y8 | IO_L21P_T3_DQS_13 | 101.755 | 102.777 | 102.266
13 | V10 | IOB_X0Y7 | IO_L21N_T3_DQS_13 | 99.827 | 100.831 | 100.329
13 | V6 | IOB_X0Y6 | IO_L22P_T3_13 | 60.997 | 61.61 | 61.3035
13 | W6 | IOB_X0Y5 | IO_L22N_T3_13 | 66.197 | 66.862 | 66.5295
13 | T8 |  | VCCO_13 |  |  | #DIV/0! |  |  |  |  |  |  |  |  |  |  |  |  |  |  |  |  |  | VCCO_13
13 | U11 |  | VCCO_13 |  |  | #DIV/0! |  |  |  |  |  |  |  |  |  |  |  |  |  |  |  |  |  | VCCO_13
13 | W7 |  | VCCO_13 |  |  | #DIV/0! |  |  |  |  |  |  |  |  |  |  |  |  |  |  |  |  |  | VCCO_13
13 | Y10 |  | VCCO_13 |  |  | #DIV/0! |  |  |  |  |  |  |  |  |  |  |  |  |  |  |  |  |  | VCCO_13
34 | R19 | IOB_X1Y99 | IO_0_34 | 81.951 | 82.775 | 82.363
34 | T11 | IOB_X1Y98 | IO_L1P_T0_34 | 144.419 | 145.871 | 145.145
34 | T10 | IOB_X1Y97 | IO_L1N_T0_34 | 137.95 | 139.336 | 138.643
34 | T12 | IOB_X1Y96 | IO_L2P_T0_34 | 158.883 | 160.479 | 159.681
34 | U12 | IOB_X1Y95 | IO_L2N_T0_34 | 165.156 | 166.816 | 165.986
34 | U13 | IOB_X1Y94 | IO_L3P_T0_DQS_PUDC_B_34 | 163.359 | 165.001 | 164.18
34 | V13 | IOB_X1Y93 | IO_L3N_T0_DQS_34 | 164.582 | 166.236 | 165.409
34 | V12 | IOB_X1Y92 | IO_L4P_T0_34 | 141.076 | 142.494 | 141.785
34 | W13 | IOB_X1Y91 | IO_L4N_T0_34 | 126.257 | 127.525 | 126.891
34 | T14 | IOB_X1Y90 | IO_L5P_T0_34 | 123.455 | 124.695 | 124.075
34 | T15 | IOB_X1Y89 | IO_L5N_T0_34 | 118.4 | 119.59 | 118.995
34 | P14 | IOB_X1Y88 | IO_L6P_T0_34 | 97.668 | 98.65 | 98.159
34 | R14 | IOB_X1Y87 | IO_L6N_T0_VREF_34 | 70.397 | 71.104 | 70.7505
34 | Y16 | IOB_X1Y86 | IO_L7P_T1_34 | 163.611 | 165.255 | 164.433
34 | Y17 | IOB_X1Y85 | IO_L7N_T1_34 | 161.278 | 162.898 | 162.088
34 | W14 | IOB_X1Y84 | IO_L8P_T1_34 | 194.3 | 196.252 | 195.276
34 | Y14 | IOB_X1Y83 | IO_L8N_T1_34 | 183.021 | 184.861 | 183.941
34 | T16 | IOB_X1Y82 | IO_L9P_T1_DQS_34 | 124.993 | 126.249 | 125.621
34 | U17 | IOB_X1Y81 | IO_L9N_T1_DQS_34 | 142.732 | 144.166 | 143.449
34 | V15 | IOB_X1Y80 | IO_L10P_T1_34 | 172.427 | 174.159 | 173.293
34 | W15 | IOB_X1Y79 | IO_L10N_T1_34 | 173.248 | 174.99 | 174.119
34 | U14 | IOB_X1Y78 | IO_L11P_T1_SRCC_34 | 183.784 | 185.632 | 184.708
34 | U15 | IOB_X1Y77 | IO_L11N_T1_SRCC_34 | 179.015 | 180.815 | 179.915
34 | U18 | IOB_X1Y76 | IO_L12P_T1_MRCC_34 | 93.537 | 94.477 | 94.007
34 | U19 | IOB_X1Y75 | IO_L12N_T1_MRCC_34 | 98.341 | 99.329 | 98.835
34 | N18 | IOB_X1Y74 | IO_L13P_T2_MRCC_34 | 56.776 | 57.347 | 57.0615
34 | P19 | IOB_X1Y73 | IO_L13N_T2_MRCC_34 | 71.583 | 72.302 | 71.9425
34 | N20 | IOB_X1Y72 | IO_L14P_T2_SRCC_34 | 50.199 | 50.703 | 50.451
34 | P20 | IOB_X1Y71 | IO_L14N_T2_SRCC_34 | 58.221 | 58.806 | 58.5135
34 | T20 | IOB_X1Y70 | IO_L15P_T2_DQS_34 | 79.909 | 80.712 | 80.3105
34 | U20 | IOB_X1Y69 | IO_L15N_T2_DQS_34 | 80.566 | 81.376 | 80.971
34 | V20 | IOB_X1Y68 | IO_L16P_T2_34 | 117.44 | 118.62 | 118.03
34 | W20 | IOB_X1Y67 | IO_L16N_T2_34 | 123.37 | 124.61 | 123.99
34 | Y18 | IOB_X1Y66 | IO_L17P_T2_34 | 119.569 | 120.771 | 120.17
34 | Y19 | IOB_X1Y65 | IO_L17N_T2_34 | 113.484 | 114.624 | 114.054
34 | V16 | IOB_X1Y64 | IO_L18P_T2_34 | 93.468 | 94.407 | 93.9375
34 | W16 | IOB_X1Y63 | IO_L18N_T2_34 | 93.86 | 94.804 | 94.332
34 | R16 | IOB_X1Y62 | IO_L19P_T3_34 | 74.311 | 75.058 | 74.6845
34 | R17 | IOB_X1Y61 | IO_L19N_T3_VREF_34 | 68.812 | 69.504 | 69.158
34 | T17 | IOB_X1Y60 | IO_L20P_T3_34 | 77.246 | 78.022 | 77.634
34 | R18 | IOB_X1Y59 | IO_L20N_T3_34 | 67.89 | 68.573 | 68.2315
34 | V17 | IOB_X1Y58 | IO_L21P_T3_DQS_34 | 106.084 | 107.15 | 106.617
34 | V18 | IOB_X1Y57 | IO_L21N_T3_DQS_34 | 98.361 | 99.349 | 98.855
34 | W18 | IOB_X1Y56 | IO_L22P_T3_34 | 85.584 | 86.444 | 86.014
34 | W19 | IOB_X1Y55 | IO_L22N_T3_34 | 82.041 | 82.865 | 82.453
34 | N17 | IOB_X1Y54 | IO_L23P_T3_34 | 71.538 | 72.257 | 71.8975
34 | P18 | IOB_X1Y53 | IO_L23N_T3_34 | 56.555 | 57.123 | 56.839
34 | P15 | IOB_X1Y52 | IO_L24P_T3_34 | 75.055 | 75.81 | 75.4325
34 | P16 | IOB_X1Y51 | IO_L24N_T3_34 | 79.991 | 80.795 | 80.393
34 | T19 | IOB_X1Y50 | IO_25_34 | 81.751 | 82.573 | 82.162
34 | N19 |  | VCCO_34 |  |  | #DIV/0! |  |  |  |  |  |  |  |  |  |  |  |  |  |  |  |  |  | VCCO_34
34 | R15 |  | VCCO_34 |  |  | #DIV/0! |  |  |  |  |  |  |  |  |  |  |  |  |  |  |  |  |  | VCCO_34
34 | T18 |  | VCCO_34 |  |  | #DIV/0! |  |  |  |  |  |  |  |  |  |  |  |  |  |  |  |  |  | VCCO_34
34 | V14 |  | VCCO_34 |  |  | #DIV/0! |  |  |  |  |  |  |  |  |  |  |  |  |  |  |  |  |  | VCCO_34
34 | W17 |  | VCCO_34 |  |  | #DIV/0! |  |  |  |  |  |  |  |  |  |  |  |  |  |  |  |  |  | VCCO_34
34 | Y20 |  | VCCO_34 |  |  | #DIV/0! |  |  |  |  |  |  |  |  |  |  |  |  |  |  |  |  |  | VCCO_34
35 | G14 | IOB_X1Y149 | IO_0_35 | 41.176 | 41.59 | 41.383
35 | C20 | IOB_X1Y148 | IO_L1P_T0_AD0P_35 | 67.529 | 68.208 | 67.8685
35 | B20 | IOB_X1Y147 | IO_L1N_T0_AD0N_35 | 65.601 | 66.261 | 65.931
35 | B19 | IOB_X1Y146 | IO_L2P_T0_AD8P_35 | 64.68 | 65.33 | 65.005
35 | A20 | IOB_X1Y145 | IO_L2N_T0_AD8N_35 | 72.581 | 73.31 | 72.9455
35 | E17 | IOB_X1Y144 | IO_L3P_T0_DQS_AD1P_35 | 35.643 | 36.001 | 35.822
35 | D18 | IOB_X1Y143 | IO_L3N_T0_DQS_AD1N_35 | 31.065 | 31.378 | 31.2215
35 | D19 | IOB_X1Y142 | IO_L4P_T0_35 | 58.896 | 59.488 | 59.192
35 | D20 | IOB_X1Y141 | IO_L4N_T0_35 | 59.391 | 59.988 | 59.6895
35 | E18 | IOB_X1Y140 | IO_L5P_T0_AD9P_35 | 53.818 | 54.359 | 54.0885
35 | E19 | IOB_X1Y139 | IO_L5N_T0_AD9N_35 | 62.956 | 63.588 | 63.272
35 | F16 | IOB_X1Y138 | IO_L6P_T0_35 | 46.237 | 46.702 | 46.4695
35 | F17 | IOB_X1Y137 | IO_L6N_T0_VREF_35 | 31.721 | 32.04 | 31.8805
35 | M19 | IOB_X1Y136 | IO_L7P_T1_AD2P_35 | 127.422 | 128.702 | 128.062
35 | M20 | IOB_X1Y135 | IO_L7N_T1_AD2N_35 | 136.978 | 138.354 | 137.666
35 | M17 | IOB_X1Y134 | IO_L8P_T1_AD10P_35 | 151.587 | 153.111 | 152.349
35 | M18 | IOB_X1Y133 | IO_L8N_T1_AD10N_35 | 138.587 | 139.979 | 139.283
35 | L19 | IOB_X1Y132 | IO_L9P_T1_DQS_AD3P_35 | 102.662 | 103.694 | 103.178
35 | L20 | IOB_X1Y131 | IO_L9N_T1_DQS_AD3N_35 | 108.082 | 109.168 | 108.625
35 | K19 | IOB_X1Y130 | IO_L10P_T1_AD11P_35 | 105.17 | 106.226 | 105.698
35 | J19 | IOB_X1Y129 | IO_L10N_T1_AD11N_35 | 104.436 | 105.486 | 104.961
35 | L16 | IOB_X1Y128 | IO_L11P_T1_SRCC_35 | 158.145 | 159.735 | 158.94
35 | L17 | IOB_X1Y127 | IO_L11N_T1_SRCC_35 | 159.29 | 160.89 | 160.09
35 | K17 | IOB_X1Y126 | IO_L12P_T1_MRCC_35 | 70.197 | 70.902 | 70.5495
35 | K18 | IOB_X1Y125 | IO_L12N_T1_MRCC_35 | 84.132 | 84.978 | 84.555
35 | H16 | IOB_X1Y124 | IO_L13P_T2_MRCC_35 | 46.286 | 46.751 | 46.5185
35 | H17 | IOB_X1Y123 | IO_L13N_T2_MRCC_35 | 53.19 | 53.724 | 53.457
35 | J18 | IOB_X1Y122 | IO_L14P_T2_AD4P_SRCC_35 | 70.796 | 71.507 | 71.1515
35 | H18 | IOB_X1Y121 | IO_L14N_T2_AD4N_SRCC_35 | 55.115 | 55.669 | 55.392
35 | F19 | IOB_X1Y120 | IO_L15P_T2_DQS_AD12P_35 | 48.539 | 49.027 | 48.783
35 | F20 | IOB_X1Y119 | IO_L15N_T2_DQS_AD12N_35 | 53.588 | 54.126 | 53.857
35 | G17 | IOB_X1Y118 | IO_L16P_T2_35 | 53.618 | 54.157 | 53.8875
35 | G18 | IOB_X1Y117 | IO_L16N_T2_35 | 37.445 | 37.822 | 37.6335
35 | J20 | IOB_X1Y116 | IO_L17P_T2_AD5P_35 | 67.298 | 67.975 | 67.6365
35 | H20 | IOB_X1Y115 | IO_L17N_T2_AD5N_35 | 64.94 | 65.592 | 65.266
35 | G19 | IOB_X1Y114 | IO_L18P_T2_AD13P_35 | 47.431 | 47.908 | 47.6695
35 | G20 | IOB_X1Y113 | IO_L18N_T2_AD13N_35 | 47.626 | 48.104 | 47.865
35 | H15 | IOB_X1Y112 | IO_L19P_T3_35 | 95.519 | 96.479 | 95.999
35 | G15 | IOB_X1Y111 | IO_L19N_T3_VREF_35 | 63.02 | 63.653 | 63.3365
35 | K14 | IOB_X1Y110 | IO_L20P_T3_AD6P_35 | 163.964 | 165.612 | 164.788
35 | J14 | IOB_X1Y109 | IO_L20N_T3_AD6N_35 | 160.614 | 162.228 | 161.421
35 | N15 | IOB_X1Y108 | IO_L21P_T3_DQS_AD14P_35 | 115.1 | 116.256 | 115.678
35 | N16 | IOB_X1Y107 | IO_L21N_T3_DQS_AD14N_35 | 112.575 | 113.707 | 113.141
35 | L14 | IOB_X1Y106 | IO_L22P_T3_AD7P_35 | 135.254 | 136.614 | 135.934
35 | L15 | IOB_X1Y105 | IO_L22N_T3_AD7N_35 | 112.244 | 113.372 | 112.808
35 | M14 | IOB_X1Y104 | IO_L23P_T3_35 | 121.058 | 122.274 | 121.666
35 | M15 | IOB_X1Y103 | IO_L23N_T3_35 | 122.85 | 124.084 | 123.467
35 | K16 | IOB_X1Y102 | IO_L24P_T3_AD15P_35 | 68.168 | 68.853 | 68.5105
35 | J16 | IOB_X1Y101 | IO_L24N_T3_AD15N_35 | 60.673 | 61.282 | 60.9775
35 | J15 | IOB_X1Y100 | IO_25_35 | 96.746 | 97.719 | 97.2325
35 | C19 |  | VCCO_35 |  |  | #DIV/0! |  |  |  |  |  |  |  |  |  |  |  |  |  |  |  |  |  | VCCO_35
35 | F18 |  | VCCO_35 |  |  | #DIV/0! |  |  |  |  |  |  |  |  |  |  |  |  |  |  |  |  |  | VCCO_35
35 | H14 |  | VCCO_35 |  |  | #DIV/0! |  |  |  |  |  |  |  |  |  |  |  |  |  |  |  |  |  | VCCO_35
35 | J17 |  | VCCO_35 |  |  | #DIV/0! |  |  |  |  |  |  |  |  |  |  |  |  |  |  |  |  |  | VCCO_35
35 | K20 |  | VCCO_35 |  |  | #DIV/0! |  |  |  |  |  |  |  |  |  |  |  |  |  |  |  |  |  | VCCO_35
35 | M16 |  | VCCO_35 |  |  | #DIV/0! |  |  |  |  |  |  |  |  |  |  |  |  |  |  |  |  |  | VCCO_35
500 | E7 | IOPAD_X1Y26 | PS_CLK_500 | 89.637 | 90.538 | 90.0875
500 | C7 | IOPAD_X1Y132 | PS_POR_B_500 | 85.83 | 86.693 | 86.2615
500 | C8 | IOPAD_X1Y92 | PS_MIO15_500 | 99.386 | 100.385 | 99.8855
500 | C5 | IOPAD_X1Y91 | PS_MIO14_500 | 65.951 | 66.614 | 66.2825
500 | E8 | IOPAD_X1Y90 | PS_MIO13_500 | 100.43 | 101.44 | 100.935
500 | D9 | IOPAD_X1Y89 | PS_MIO12_500 | 112.803 | 113.937 | 113.37
500 | C6 | IOPAD_X1Y88 | PS_MIO11_500 | 114.048 | 115.194 | 114.621
500 | E9 | IOPAD_X1Y87 | PS_MIO10_500 | 98.591 | 99.581 | 99.086
500 | B5 | IOPAD_X1Y86 | PS_MIO9_500 | 86.962 | 87.836 | 87.399
500 | D5 | IOPAD_X1Y85 | PS_MIO8_500 | 55.328 | 55.884 | 55.606
500 | D8 | IOPAD_X1Y84 | PS_MIO7_500 | 116 | 117.166 | 116.583
500 | A5 | IOPAD_X1Y83 | PS_MIO6_500 | 99.813 | 100.817 | 100.315
500 | A6 | IOPAD_X1Y82 | PS_MIO5_500 | 112.569 | 113.701 | 113.135
500 | B7 | IOPAD_X1Y81 | PS_MIO4_500 | 95.694 | 96.656 | 96.175
500 | D6 | IOPAD_X1Y80 | PS_MIO3_500 | 75.879 | 76.641 | 76.26
500 | B8 | IOPAD_X1Y79 | PS_MIO2_500 | 141.105 | 142.523 | 141.814
500 | A7 | IOPAD_X1Y78 | PS_MIO1_500 | 128.546 | 129.838 | 129.192
500 | E6 | IOPAD_X1Y77 | PS_MIO0_500 | 60.906 | 61.518 | 61.212
500 | B6 |  | VCCO_MIO0_500 |  |  | #DIV/0!
500 | D7 |  | VCCO_MIO0_500 |  |  | #DIV/0!
501 | E14 | IOPAD_X1Y94 | PS_MIO17_501 | 188.491 | 190.385 | 189.438
501 | D10 | IOPAD_X1Y96 | PS_MIO19_501 | 106.553 | 107.623 | 107.088
501 | F14 | IOPAD_X1Y98 | PS_MIO21_501 | 193.715 | 195.661 | 194.688
501 | D11 | IOPAD_X1Y100 | PS_MIO23_501 | 106.475 | 107.545 | 107.01
501 | F15 | IOPAD_X1Y102 | PS_MIO25_501 | 156.222 | 157.792 | 157.007
501 | D13 | IOPAD_X1Y104 | PS_MIO27_501 | 136.311 | 137.681 | 136.996
501 | C13 | IOPAD_X1Y106 | PS_MIO29_501 | 133.884 | 135.23 | 134.557
501 | E16 | IOPAD_X1Y108 | PS_MIO31_501 | 168.7 | 170.396 | 169.548
501 | D15 | IOPAD_X1Y110 | PS_MIO33_501 | 156.659 | 158.233 | 157.446
501 | F12 | IOPAD_X1Y112 | PS_MIO35_501 | 143.931 | 145.377 | 144.654
501 | E13 | IOPAD_X1Y115 | PS_MIO38_501 | 91.003 | 91.918 | 91.4605
501 | D14 | IOPAD_X1Y117 | PS_MIO40_501 | 119.992 | 121.198 | 120.595
501 | E12 | IOPAD_X1Y119 | PS_MIO42_501 | 99.836 | 100.84 | 100.338
501 | F13 | IOPAD_X1Y121 | PS_MIO44_501 | 165.841 | 167.507 | 166.674
501 | D16 | IOPAD_X1Y123 | PS_MIO46_501 | 150.552 | 152.066 | 151.309
501 | B12 | IOPAD_X1Y125 | PS_MIO48_501 | 95.32 | 96.278 | 95.799
501 | B13 | IOPAD_X1Y127 | PS_MIO50_501 | 96.872 | 97.846 | 97.359
501 | C10 | IOPAD_X1Y129 | PS_MIO52_501 | 62.315 | 62.941 | 62.628
501 | B10 | IOPAD_X1Y134 | PS_SRST_B_501 | 71.499 | 72.218 | 71.8585
501 | A19 | IOPAD_X1Y93 | PS_MIO16_501 | 160.032 | 161.64 | 160.836
501 | B18 | IOPAD_X1Y95 | PS_MIO18_501 | 152.468 | 154 | 153.234
501 | A17 | IOPAD_X1Y97 | PS_MIO20_501 | 142.035 | 143.463 | 142.749
501 | B17 | IOPAD_X1Y99 | PS_MIO22_501 | 150.67 | 152.184 | 151.427
501 | A16 | IOPAD_X1Y101 | PS_MIO24_501 | 138.996 | 140.392 | 139.694
501 | A15 | IOPAD_X1Y103 | PS_MIO26_501 | 133.761 | 135.105 | 134.433
501 | C16 | IOPAD_X1Y105 | PS_MIO28_501 | 133.332 | 134.672 | 134.002
501 | C15 | IOPAD_X1Y107 | PS_MIO30_501 | 124.851 | 126.105 | 125.478
501 | A14 | IOPAD_X1Y109 | PS_MIO32_501 | 115.956 | 117.122 | 116.539
501 | A12 | IOPAD_X1Y111 | PS_MIO34_501 | 92.166 | 93.092 | 92.629
501 | A11 | IOPAD_X1Y113 | PS_MIO36_501 | 77.323 | 78.101 | 77.712
501 | A10 | IOPAD_X1Y114 | PS_MIO37_501 | 70.641 | 71.351 | 70.996
501 | C18 | IOPAD_X1Y116 | PS_MIO39_501 | 129.531 | 130.833 | 130.182
501 | C17 | IOPAD_X1Y118 | PS_MIO41_501 | 118.996 | 120.192 | 119.594
501 | A9 | IOPAD_X1Y120 | PS_MIO43_501 | 58.015 | 58.598 | 58.3065
501 | B15 | IOPAD_X1Y122 | PS_MIO45_501 | 121.863 | 123.087 | 122.475
501 | B14 | IOPAD_X1Y124 | PS_MIO47_501 | 98.31 | 99.298 | 98.804
501 | C12 | IOPAD_X1Y126 | PS_MIO49_501 | 76.558 | 77.328 | 76.943
501 | B9 | IOPAD_X1Y128 | PS_MIO51_501 | 52.36 | 52.886 | 52.623
501 | C11 | IOPAD_X1Y130 | PS_MIO53_501 | 53.811 | 54.352 | 54.0815
501 | E11 |  | PS_MIO_VREF_501 | 80.735 | 81.546 | 81.1405
501 | A13 |  | VCCO_MIO1_501 |  |  | #DIV/0!
501 | B16 |  | VCCO_MIO1_501 |  |  | #DIV/0!
501 | D12 |  | VCCO_MIO1_501 |  |  | #DIV/0!
501 | E15 |  | VCCO_MIO1_501 |  |  | #DIV/0!
502 | B4 | IOPAD_X1Y72 | PS_DDR_DRST_B_502 | 87.162 | 88.038 | 87.6
502 | C3 | IOPAD_X1Y32 | PS_DDR_DQ0_502 | 93.857 | 94.8 | 94.3285
502 | B3 | IOPAD_X1Y33 | PS_DDR_DQ1_502 | 101.63 | 102.652 | 102.141
502 | A2 | IOPAD_X1Y34 | PS_DDR_DQ2_502 | 92.447 | 93.376 | 92.9115
502 | A4 | IOPAD_X1Y35 | PS_DDR_DQ3_502 | 103.519 | 104.559 | 104.039
502 | A1 | IOPAD_X1Y28 | PS_DDR_DM0_502 | 101.191 | 102.207 | 101.699
502 | C2 | IOPAD_X1Y68 | PS_DDR_DQS_P0_502 | 102.905 | 103.939 | 103.422
502 | B2 | IOPAD_X1Y64 | PS_DDR_DQS_N0_502 | 106.141 | 107.207 | 106.674
502 | D3 | IOPAD_X1Y36 | PS_DDR_DQ4_502 | 95.275 | 96.233 | 95.754
502 | D1 | IOPAD_X1Y37 | PS_DDR_DQ5_502 | 96.829 | 97.802 | 97.3155
502 | C1 | IOPAD_X1Y38 | PS_DDR_DQ6_502 | 97.302 | 98.279 | 97.7905
502 | E1 | IOPAD_X1Y39 | PS_DDR_DQ7_502 | 95.431 | 96.39 | 95.9105
502 | E2 | IOPAD_X1Y40 | PS_DDR_DQ8_502 | 77.032 | 77.806 | 77.419
502 | E3 | IOPAD_X1Y41 | PS_DDR_DQ9_502 | 80.808 | 81.62 | 81.214
502 | G3 | IOPAD_X1Y42 | PS_DDR_DQ10_502 | 56.601 | 57.169 | 56.885
502 | H3 | IOPAD_X1Y43 | PS_DDR_DQ11_502 | 56.774 | 57.345 | 57.0595
502 | F1 | IOPAD_X1Y29 | PS_DDR_DM1_502 | 58.659 | 59.249 | 58.954
502 | G2 | IOPAD_X1Y69 | PS_DDR_DQS_P1_502 | 64.059 | 64.703 | 64.381
502 | F2 | IOPAD_X1Y65 | PS_DDR_DQS_N1_502 | 69.055 | 69.749 | 69.402
502 | J3 | IOPAD_X1Y44 | PS_DDR_DQ12_502 | 63.68 | 64.32 | 64
502 | H2 | IOPAD_X1Y45 | PS_DDR_DQ13_502 | 55.551 | 56.109 | 55.83
502 | H1 | IOPAD_X1Y46 | PS_DDR_DQ14_502 | 58.466 | 59.054 | 58.76
502 | J1 | IOPAD_X1Y47 | PS_DDR_DQ15_502 | 62.941 | 63.573 | 63.257
502 | F4 | IOPAD_X1Y17 | PS_DDR_A14_502 | 77.784 | 78.565 | 78.1745
502 | D4 | IOPAD_X1Y18 | PS_DDR_A13_502 | 96.091 | 97.056 | 96.5735
502 | E4 | IOPAD_X1Y16 | PS_DDR_A12_502 | 92.368 | 93.296 | 92.832
502 | G4 | IOPAD_X1Y15 | PS_DDR_A11_502 | 65.067 | 65.721 | 65.394
502 | F5 | IOPAD_X1Y14 | PS_DDR_A10_502 | 86.071 | 86.936 | 86.5035
502 | J4 | IOPAD_X1Y13 | PS_DDR_A9_502 | 73.426 | 74.164 | 73.795
502 | K1 | IOPAD_X1Y12 | PS_DDR_A8_502 | 63.676 | 64.316 | 63.996
502 | K4 | IOPAD_X1Y11 | PS_DDR_A7_502 | 66.244 | 66.91 | 66.577
502 | L4 | IOPAD_X1Y10 | PS_DDR_A6_502 | 71.26 | 71.976 | 71.618
502 | L1 | IOPAD_X1Y9 | PS_DDR_A5_502 | 63.37 | 64.007 | 63.6885
502 | M4 | IOPAD_X1Y8 | PS_DDR_A4_502 | 97.538 | 98.519 | 98.0285
502 | K3 | IOPAD_X1Y7 | PS_DDR_A3_502 | 62.947 | 63.579 | 63.263
502 | G5 | IOPAD_X1Y2 | PS_DDR_VRN_502 | 97.659 | 98.64 | 98.1495
502 | H5 | IOPAD_X1Y3 | PS_DDR_VRP_502 | 69.315 | 70.012 | 69.6635
502 | L2 | IOPAD_X1Y25 | PS_DDR_CKP_502 | 77.478 | 78.257 | 77.8675
502 | M2 | IOPAD_X1Y24 | PS_DDR_CKN_502 | 82.598 | 83.429 | 83.0135
502 | M3 | IOPAD_X1Y6 | PS_DDR_A2_502 | 63.841 | 64.483 | 64.162
502 | K2 | IOPAD_X1Y5 | PS_DDR_A1_502 | 63.927 | 64.569 | 64.248
502 | N2 | IOPAD_X1Y4 | PS_DDR_A0_502 | 76.692 | 77.463 | 77.0775
502 | J5 | IOPAD_X1Y21 | PS_DDR_BA2_502 | 74.205 | 74.951 | 74.578
502 | R4 | IOPAD_X1Y20 | PS_DDR_BA1_502 | 104.22 | 105.268 | 104.744
502 | L5 | IOPAD_X1Y19 | PS_DDR_BA0_502 | 55.75 | 56.31 | 56.03
502 | N5 | IOPAD_X1Y131 | PS_DDR_ODT_502 | 66.666 | 67.336 | 67.001
502 | N1 | IOPAD_X1Y27 | PS_DDR_CS_B_502 | 64.131 | 64.775 | 64.453
502 | N3 | IOPAD_X1Y23 | PS_DDR_CKE_502 | 50.512 | 51.019 | 50.7655
502 | M5 | IOPAD_X1Y1 | PS_DDR_WE_B_502 | 103.69 | 104.732 | 104.211
502 | P5 | IOPAD_X1Y22 | PS_DDR_CAS_B_502 | 71.356 | 72.073 | 71.7145
502 | P4 | IOPAD_X1Y133 | PS_DDR_RAS_B_502 | 99.628 | 100.63 | 100.129
502 | P1 | IOPAD_X1Y48 | PS_DDR_DQ16_502 | 81.372 | 82.19 | 81.781
502 | P3 | IOPAD_X1Y49 | PS_DDR_DQ17_502 | 91.181 | 92.097 | 91.639
502 | R3 | IOPAD_X1Y50 | PS_DDR_DQ18_502 | 76.04 | 76.804 | 76.422
502 | R1 | IOPAD_X1Y51 | PS_DDR_DQ19_502 | 87.833 | 88.716 | 88.2745
502 | T1 | IOPAD_X1Y30 | PS_DDR_DM2_502 | 89.82 | 90.723 | 90.2715
502 | R2 | IOPAD_X1Y70 | PS_DDR_DQS_P2_502 | 89.381 | 90.28 | 89.8305
502 | T2 | IOPAD_X1Y66 | PS_DDR_DQS_N2_502 | 88.063 | 88.948 | 88.5055
502 | T4 | IOPAD_X1Y52 | PS_DDR_DQ20_502 | 92.377 | 93.305 | 92.841
502 | U4 | IOPAD_X1Y53 | PS_DDR_DQ21_502 | 95.677 | 96.638 | 96.1575
502 | U2 | IOPAD_X1Y54 | PS_DDR_DQ22_502 | 93.967 | 94.911 | 94.439
502 | U3 | IOPAD_X1Y55 | PS_DDR_DQ23_502 | 103.51 | 104.55 | 104.03
502 | V1 | IOPAD_X1Y56 | PS_DDR_DQ24_502 | 102.959 | 103.993 | 103.476
502 | Y3 | IOPAD_X1Y57 | PS_DDR_DQ25_502 | 107.498 | 108.578 | 108.038
502 | W1 | IOPAD_X1Y58 | PS_DDR_DQ26_502 | 109.265 | 110.363 | 109.814
502 | Y4 | IOPAD_X1Y59 | PS_DDR_DQ27_502 | 105.977 | 107.043 | 106.51
502 | Y1 | IOPAD_X1Y31 | PS_DDR_DM3_502 | 103.574 | 104.614 | 104.094
502 | W5 | IOPAD_X1Y71 | PS_DDR_DQS_P3_502 | 111.823 | 112.947 | 112.385
502 | W4 | IOPAD_X1Y67 | PS_DDR_DQS_N3_502 | 114.289 | 115.437 | 114.863
502 | Y2 | IOPAD_X1Y60 | PS_DDR_DQ28_502 | 103.407 | 104.447 | 103.927
502 | W3 | IOPAD_X1Y61 | PS_DDR_DQ29_502 | 106.021 | 107.087 | 106.554
502 | V2 | IOPAD_X1Y62 | PS_DDR_DQ30_502 | 101.79 | 102.814 | 102.302
502 | V3 | IOPAD_X1Y63 | PS_DDR_DQ31_502 | 97.591 | 98.572 | 98.0815
502 | A3 |  | VCCO_DDR_502 |  |  | #DIV/0!
502 | D2 |  | VCCO_DDR_502 |  |  | #DIV/0!
502 | E5 |  | VCCO_DDR_502 |  |  | #DIV/0!
502 | G1 |  | VCCO_DDR_502 |  |  | #DIV/0!
502 | H4 |  | VCCO_DDR_502 |  |  | #DIV/0!
502 | L3 |  | VCCO_DDR_502 |  |  | #DIV/0!
502 | P2 |  | VCCO_DDR_502 |  |  | #DIV/0!
502 | R5 |  | VCCO_DDR_502 |  |  | #DIV/0!
502 | U1 |  | VCCO_DDR_502 |  |  | #DIV/0!
502 | V4 |  | VCCO_DDR_502 |  |  | #DIV/0!
502 | H6 |  | PS_DDR_VREF0_502 | 32.755 | 33.084 | 32.9195
502 | P6 |  | PS_DDR_VREF1_502 | 54.33 | 54.877 | 54.6035
 | F10 |  | RSVDGND | 83.905 | 84.749 | 84.327
 | N6 |  | RSVDVCC3 | 106.217 | 107.285 | 106.751
 | R6 |  | RSVDVCC2 | 101.154 | 102.17 | 101.662
 | T6 |  | RSVDVCC1 | 85.291 | 86.149 | 85.72
 | A8 |  | GND |  |  | #DIV/0! |  |  |  |  |  |  |  |  |  |  |  |  |  |  |  |  |  | GND | GND
 | A18 |  | GND |  |  | #DIV/0! |  |  |  |  |  |  |  |  |  |  |  |  |  |  |  |  |  | GND | GND
 | B1 |  | GND |  |  | #DIV/0! |  |  |  |  |  |  |  |  |  |  |  |  |  |  |  |  |  | GND | GND
 | B11 |  | GND |  |  | #DIV/0! |  |  |  |  |  |  |  |  |  |  |  |  |  |  |  |  |  | GND | GND
 | C4 |  | GND |  |  | #DIV/0! |  |  |  |  |  |  |  |  |  |  |  |  |  |  |  |  |  | GND | GND
 | C14 |  | GND |  |  | #DIV/0! |  |  |  |  |  |  |  |  |  |  |  |  |  |  |  |  |  | GND | GND
 | K11 |  | GND |  |  | #DIV/0! |  |  |  |  |  |  |  |  |  |  |  |  |  |  |  |  |  | GND | GND
 | D17 |  | GND |  |  | #DIV/0! |  |  |  |  |  |  |  |  |  |  |  |  |  |  |  |  |  | GND | GND
 | E10 |  | GND |  |  | #DIV/0! |  |  |  |  |  |  |  |  |  |  |  |  |  |  |  |  |  | GND | GND
 | E20 |  | GND |  |  |  |  |  |  |  |  |  |  |  |  |  |  |  |  |  |  |  |  | GND | GND
 | F3 |  | GND |  |  |  |  |  |  |  |  |  |  |  |  |  |  |  |  |  |  |  |  | GND | GND
 | F7 |  | GND |  |  |  |  |  |  |  |  |  |  |  |  |  |  |  |  |  |  |  |  | GND | GND
 | G10 |  | GND |  |  |  |  |  |  |  |  |  |  |  |  |  |  |  |  |  |  |  |  | GND | GND
 | G12 |  | GND |  |  |  |  |  |  |  |  |  |  |  |  |  |  |  |  |  |  |  |  | GND | GND
 | G16 |  | GND |  |  |  |  |  |  |  |  |  |  |  |  |  |  |  |  |  |  |  |  | GND | GND
 | H7 |  | GND |  |  |  |  |  |  |  |  |  |  |  |  |  |  |  |  |  |  |  |  | GND | GND
 | H9 |  | GND |  |  |  |  |  |  |  |  |  |  |  |  |  |  |  |  |  |  |  |  | GND | GND
 | H11 |  | GND |  |  |  |  |  |  |  |  |  |  |  |  |  |  |  |  |  |  |  |  | GND | GND
 | H13 |  | GND |  |  |  |  |  |  |  |  |  |  |  |  |  |  |  |  |  |  |  |  | GND | GND
 | H19 |  | GND |  |  |  |  |  |  |  |  |  |  |  |  |  |  |  |  |  |  |  |  | GND | GND
 | J2 |  | GND |  |  |  |  |  |  |  |  |  |  |  |  |  |  |  |  |  |  |  |  | GND | GND
 | J8 |  | GND |  |  |  |  |  |  |  |  |  |  |  |  |  |  |  |  |  |  |  |  | GND | GND
 | J12 |  | GND |  |  |  |  |  |  |  |  |  |  |  |  |  |  |  |  |  |  |  |  | GND | GND
 | K5 |  | GND |  |  |  |  |  |  |  |  |  |  |  |  |  |  |  |  |  |  |  |  | GND | GND
 | K7 |  | GND |  |  |  |  |  |  |  |  |  |  |  |  |  |  |  |  |  |  |  |  | GND | GND
 | C9 |  | GND |  |  |  |  |  |  |  |  |  |  |  |  |  |  |  |  |  |  |  |  | GND | GND
 | K13 |  | GND |  |  |  |  |  |  |  |  |  |  |  |  |  |  |  |  |  |  |  |  | GND | GND
 | K15 |  | GND |  |  |  |  |  |  |  |  |  |  |  |  |  |  |  |  |  |  |  |  | GND | GND
 | L8 |  | GND |  |  |  |  |  |  |  |  |  |  |  |  |  |  |  |  |  |  |  |  | GND | GND
 | L12 |  | GND |  |  |  |  |  |  |  |  |  |  |  |  |  |  |  |  |  |  |  |  | GND | GND
 | L18 |  | GND |  |  |  |  |  |  |  |  |  |  |  |  |  |  |  |  |  |  |  |  | GND | GND
 | M1 |  | GND |  |  |  |  |  |  |  |  |  |  |  |  |  |  |  |  |  |  |  |  | GND | GND
 | M7 |  | GND |  |  |  |  |  |  |  |  |  |  |  |  |  |  |  |  |  |  |  |  | GND | GND
 | M11 |  | GND |  |  |  |  |  |  |  |  |  |  |  |  |  |  |  |  |  |  |  |  | GND | GND
 | M13 |  | GND |  |  |  |  |  |  |  |  |  |  |  |  |  |  |  |  |  |  |  |  | GND | GND
 | N4 |  | GND |  |  |  |  |  |  |  |  |  |  |  |  |  |  |  |  |  |  |  |  | GND | GND
 | N8 |  | GND |  |  |  |  |  |  |  |  |  |  |  |  |  |  |  |  |  |  |  |  | GND | GND
 | N10 |  | GND |  |  |  |  |  |  |  |  |  |  |  |  |  |  |  |  |  |  |  |  | GND | GND
 | N12 |  | GND |  |  |  |  |  |  |  |  |  |  |  |  |  |  |  |  |  |  |  |  | GND | GND
 | N14 |  | GND |  |  |  |  |  |  |  |  |  |  |  |  |  |  |  |  |  |  |  |  | GND | GND
 | P7 |  | GND |  |  |  |  |  |  |  |  |  |  |  |  |  |  |  |  |  |  |  |  | GND | GND
 | P9 |  | GND |  |  |  |  |  |  |  |  |  |  |  |  |  |  |  |  |  |  |  |  | GND | GND
 | P11 |  | GND |  |  |  |  |  |  |  |  |  |  |  |  |  |  |  |  |  |  |  |  | GND | GND
 | P13 |  | GND |  |  |  |  |  |  |  |  |  |  |  |  |  |  |  |  |  |  |  |  | GND | GND
 | P17 |  | GND |  |  |  |  |  |  |  |  |  |  |  |  |  |  |  |  |  |  |  |  | GND | GND

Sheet: io_1
#Top: ios Floorplan: io_1 Part: xc7z020clg484-1 |  |  |  |  | Propagation in outer layers (ps/inch): |  |  | 148.267
#Generated by: tomg on: Fri Nov 18 09:46:53 2016 |  |  |  |  | Propagation in inner layers (ps/inch): |  |  | 164.943
#Build: Vivado v2014.4 by: xbuild on: Tue Nov 18 18:29:27 MST 2014
IO Bank | Pin Number | IOB Alias | Site Type | Min Trace Delay (ps) | Max Trace Delay (ps) | Average Trace | Tolerance
 | F3 | IOPAD_X1Y72 | PS_DDR_DRST_B_502 | 35.933 | 36.294 | 36.1135 | 0.361
 | D1 | IOPAD_X1Y32 | PS_DDR_DQ0_502 | 65.363 | 66.02 | 65.6915 | 0.657
 | C3 | IOPAD_X1Y33 | PS_DDR_DQ1_502 | 67.741 | 68.422 | 68.0815 | 0.681
 | B2 | IOPAD_X1Y34 | PS_DDR_DQ2_502 | 67.272 | 67.949 | 67.6105 | 0.677
 | D3 | IOPAD_X1Y35 | PS_DDR_DQ3_502 | 59.3 | 59.896 | 59.598 | 0.596
 | B1 | IOPAD_X1Y28 | PS_DDR_DM0_502 | 74.037 | 74.781 | 74.409 | 0.744
 | C2 | IOPAD_X1Y68 | PS_DDR_DQS_P0_502 | 68.926 | 69.618 | 69.272 | 0.692
 | D2 | IOPAD_X1Y64 | PS_DDR_DQS_N0_502 | 67.327 | 68.004 | 67.6655 | 0.677
 | E3 | IOPAD_X1Y36 | PS_DDR_DQ4_502 | 71.163 | 71.878 | 71.5205 | 0.715
 | E1 | IOPAD_X1Y37 | PS_DDR_DQ5_502 | 64.024 | 64.667 | 64.3455 | 0.643
 | F2 | IOPAD_X1Y38 | PS_DDR_DQ6_502 | 56.463 | 57.03 | 56.7465 | 0.567
 | F1 | IOPAD_X1Y39 | PS_DDR_DQ7_502 | 57.903 | 58.485 | 58.194 | 0.582
 | G2 | IOPAD_X1Y40 | PS_DDR_DQ8_502 | 59.383 | 59.979 | 59.681 | 0.596
 | G1 | IOPAD_X1Y41 | PS_DDR_DQ9_502 | 56.932 | 57.504 | 57.218 | 0.572
 | L1 | IOPAD_X1Y42 | PS_DDR_DQ10_502 | 75.029 | 75.783 | 75.406 | 0.754
 | L2 | IOPAD_X1Y43 | PS_DDR_DQ11_502 | 71.26 | 71.976 | 71.618 | 0.716
 | H3 | IOPAD_X1Y29 | PS_DDR_DM1_502 | 58.793 | 59.384 | 59.0885 | 0.591
 | H2 | IOPAD_X1Y69 | PS_DDR_DQS_P1_502 | 69.456 | 70.154 | 69.805 | 0.698
 | J2 | IOPAD_X1Y65 | PS_DDR_DQS_N1_502 | 71.992 | 72.716 | 72.354 | 0.724
 | L3 | IOPAD_X1Y44 | PS_DDR_DQ12_502 | 63.803 | 64.444 | 64.1235 | 0.641
 | K1 | IOPAD_X1Y45 | PS_DDR_DQ13_502 | 59.175 | 59.77 | 59.4725 | 0.595
 | J1 | IOPAD_X1Y46 | PS_DDR_DQ14_502 | 51.589 | 52.108 | 51.8485 | 0.519
 | K3 | IOPAD_X1Y47 | PS_DDR_DQ15_502 | 67.041 | 67.715 | 67.378 | 0.674
 | F4 | IOPAD_X1Y18 | PS_DDR_A13_502 | 70.85 | 71.562 | 71.206 | 0.712
 | H4 | IOPAD_X1Y16 | PS_DDR_A12_502 | 51.003 | 51.516 | 51.2595 | 0.513
 | G5 | IOPAD_X1Y15 | PS_DDR_A11_502 | 51.905 | 52.427 | 52.166 | 0.522
 | J3 | IOPAD_X1Y14 | PS_DDR_A10_502 | 43.62 | 44.058 | 43.839 | 0.438
 | H5 | IOPAD_X1Y13 | PS_DDR_A9_502 | 53.411 | 53.947 | 53.679 | 0.536
 | J5 | IOPAD_X1Y12 | PS_DDR_A8_502 | 50.285 | 50.79 | 50.5375 | 0.505
 | J6 | IOPAD_X1Y11 | PS_DDR_A7_502 | 45.28 | 45.735 | 45.5075 | 0.455
 | J7 | IOPAD_X1Y10 | PS_DDR_A6_502 | 50.294 | 50.799 | 50.5465 | 0.505
 | K5 | IOPAD_X1Y9 | PS_DDR_A5_502 | 48.188 | 48.673 | 48.4305 | 0.485
 | K6 | IOPAD_X1Y8 | PS_DDR_A4_502 | 58.87 | 59.462 | 59.166 | 0.592
 | L4 | IOPAD_X1Y7 | PS_DDR_A3_502 | 42.898 | 43.329 | 43.1135 | 0.431
 | N4 | IOPAD_X1Y25 | PS_DDR_CKP_502 | 62.216 | 62.841 | 62.5285 | 0.625
 | N5 | IOPAD_X1Y24 | PS_DDR_CKN_502 | 59.34 | 59.936 | 59.638 | 0.596
 | K4 | IOPAD_X1Y6 | PS_DDR_A2_502 | 42.061 | 42.484 | 42.2725 | 0.423
 | M5 | IOPAD_X1Y5 | PS_DDR_A1_502 | 46.895 | 47.366 | 47.1305 | 0.471
 | M4 | IOPAD_X1Y4 | PS_DDR_A0_502 | 44.461 | 44.908 | 44.6845 | 0.447
 | M6 | IOPAD_X1Y21 | PS_DDR_BA2_502 | 50.935 | 51.447 | 51.191 | 0.512
 | L6 | IOPAD_X1Y20 | PS_DDR_BA1_502 | 60.452 | 61.059 | 60.7555 | 0.607
 | L7 | IOPAD_X1Y19 | PS_DDR_BA0_502 | 49.068 | 49.561 | 49.3145 | 0.493
 | P5 | IOPAD_X1Y131 | PS_DDR_ODT_502 | 64.592 | 65.241 | 64.9165 | 0.649
 | P6 | IOPAD_X1Y27 | PS_DDR_CS_B_502 | 80.877 | 81.69 | 81.2835 | 0.813
 | V3 | IOPAD_X1Y23 | PS_DDR_CKE_502 | 122.913 | 124.149 | 123.531 | 1.236
 | R4 | IOPAD_X1Y1 | PS_DDR_WE_B_502 | 107.729 | 108.811 | 108.27 | 1.082
 | P3 | IOPAD_X1Y22 | PS_DDR_CAS_B_502 | 49.606 | 50.104 | 49.855 | 0.498
 | R5 | IOPAD_X1Y133 | PS_DDR_RAS_B_502 | 81.806 | 82.628 | 82.217 | 0.822
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

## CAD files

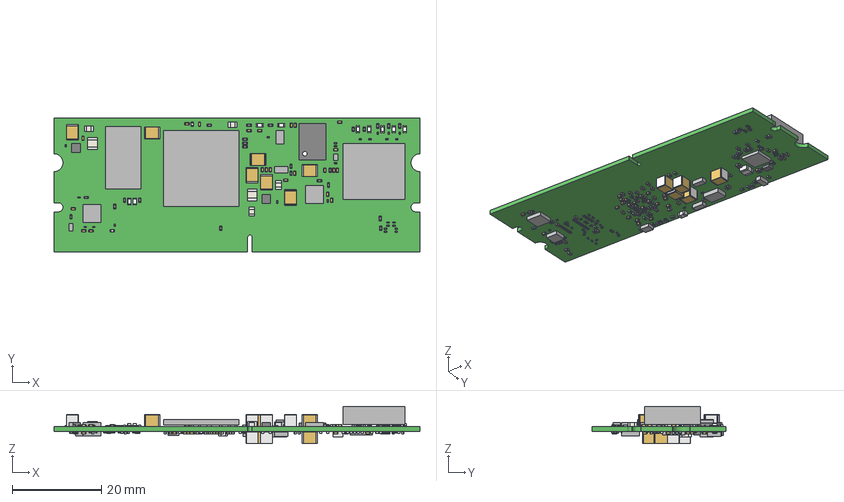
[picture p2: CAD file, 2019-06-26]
Project Outputs for ZYNQ_IPMC/revB1/ExportSTEP/ZYNQ_IPMC.step
82.0 x 30.0 x 8.37 mm
Board
Mid_Body x 119
Open_CASCADE_STEP_translator_6.8_2.2.1 x 233
Mark x 119
Extruded x 80
Open_CASCADE_STEP_translator_6.8_6.2.1 x 98
Open_CASCADE_STEP_translator_6.8_3.1.1 x 12
Open_CASCADE_STEP_translator_6.8_3.1.2 x 12
Open_CASCADE_STEP_translator_6.8_3.2.1 x 12
Open_CASCADE_STEP_translator_6.8_9.1.1 x 39
Open_CASCADE_STEP_translator_6.8_9.1.2 x 39
Open_CASCADE_STEP_translator_6.8_9.2.1 x 40
Open_CASCADE_STEP_translator_6.8_9.1
Thermal_Shape
Open_CASCADE_STEP_translator_6.8_9.4.1 x 8
housing x 9
cover x 9
base x 18
Polarity_Mark x 9
Open_CASCADE_STEP_translator_6.8_2.1.1 x 93
Open_CASCADE_STEP_translator_6.8_2.1.2 x 93

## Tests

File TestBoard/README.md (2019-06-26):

# ZYNQ-IPMC Test Board

This is dual-layer board intended for bring-up and light development of ZYNQ-IPMC.
The Test Board was designed for ZYNQ-IPMC revAs but it works just as well with revBs.

## Power from 3.3V

The Test Board uses a custom DC/DC power converter that converts from 12V to 3.3V.
This can be bypassed by wired a benchtop power supply set to 3.3V directly to the
3.3V pins as marked on the PCB silkscreen.

## Control and IPMC slots

The Control slot on the Test Board is to be used as a simulated Shelf endpoint -
this was never developed however. It is still used for testing with the Python Test
Suite as described below.

The IPMC slot is where the target ZYNQ-IPMC under-testing should be placed.

## Python Test Suite

The [Python test script](ipmc_testsuite.py) expects the serial COM to the IPMC to be
available in ```/dev/ttyUSB0``` and the Control IPMC in ```/dev/ttyUSB1```. Both need to
be booted into ***fallback firmware***. This can be changed my modifying the script.

Several connectivity tests between both cards will be executed and a final status
report will be presented. This is useful to verify if pins are shorted/floating.

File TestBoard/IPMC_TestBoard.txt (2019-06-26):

Field=#~Integer~#~50|Field=Comment~String~Comment~90|Field=Quantity~Integer~Quantity~90|Field=Designator~String~Designator~90|Field=Mfgr~String~Mfgr~90|Field=Mfg. Part No.~String~Mfg. Part No.~90|Field=Footprint~String~Footprint~170|Field=Value~String~Value~73|Field=Rating~String~Rating~73|Field=Tolerance~String~Tolerance~73|Field=INVKEY~String~INVKEY~127|Field=Note~String~Note~26|ReportField=Currency~<none>|ReportField=ProductionQuantity~1|ReportField=ProjectFileName~IPMC_TestBoard.PrjPcb|ReportField=ProjectFullPath~C:\CERN\APD\IPMC_TestBoard\IPMC_TestBoard.PrjPcb|ReportField=Title~Bill of Materials For Project [IPMC_TestBoard.PrjPcb] (No PCB Document Selected)|ReportField=TotalQuantity~87|ReportField=ReportTime~14:02:53|ReportField=ReportDate~24/03/2017|ReportField=ReportDateTime~24/03/2017 14:02:53|ReportField=OutputName~Bill of Materials|ReportField=OutputType~BOM_PartType|ReportField=GeneratorName~BOM|ReportField=GeneratorDescription~Bill of Materials|ReportField=VariantName~None|ReportField=Revision~revA|ReportField=Address1~|ReportField=Address2~|ReportField=Address3~|ReportField=Address4~|ReportField=Application_BuildNumber~|ReportField=ApprovedBy~|ReportField=Author~|ReportField=CheckedBy~|ReportField=CompanyName~|ReportField=CurrentDate~24/03/2017|ReportField=CurrentTime~13:59:28|ReportField=Date~|ReportField=DocumentFullPathAndName~C:\CERN\APD\IPMC_TestBoard\IPMC_Control.SchDoc|ReportField=DocumentName~IPMC_Control.SchDoc|ReportField=DocumentNumber~|ReportField=DrawnBy~|ReportField=Engineer~|ReportField=ImagePath~|ReportField=ModifiedDate~24/03/2017|ReportField=Organization~|ReportField=ProjectName~IPMC_TestBoard.PrjPcb|ReportField=Rule~|ReportField=SheetNumber~|ReportField=SheetTotal~|ReportField=Time~|ReportField=Title~|ReportField=DataSourceFileName~IPMC_TestBoard.PrjPcb|ReportField=DataSourceFullPath~C:\CERN\APD\IPMC_TestBoard\IPMC_TestBoard.PrjPcb|ReportField=PCBConfigurationName~Default Configuration|ReportField=Item~|ReportField=ItemRevision~|ReportField=ItemAndRevision~|ReportField=ItemRevisionBase~|ReportField=ItemRevisionLevel1~|ReportField=ItemRevisionLevel2~|ReportField=ItemRevisionLevel1AndBase~|ReportField=ItemRevisionLevel2AndLevel1~
1|47pF|6|C1, C3, C4, C11, C12, C13|Yageo|CC0402JRNPO9BN470|C0402|47pF|50V||CP0402-47PF-50V-5%|
2|?|3|C2, C7, C10|Murata|GRM32ER60J107ME20L|C1210_IPC_H|100uF|6.3V||CP1210-100UF-6.3V-20%|
3|150uF|3|C5, C8, C9|Kemet|A700X157M006ATE015|VISH-293D-7343-31_V|150uF|6.3V||CP7343-150uF-6.3V-ESR15-20%|
4|?|1|C6|Panasonic-ECJ|ECJ-0EB1A473K|C0402_IPC_H|47nF|10V||CP0402-47NF-10V-10%|
5|BLUE|6|D1, D4, D7, D8, D9, D10|Lite-On|LTST-S270TBKT|LED0603_M|BLUE|||LED-BL-RA-0603|
6|GREEN|3|D2, D5, D11|Lite-On|LTST-S270KGKT|LED0603_M|GREEN|||LED-GRN-RA-UB-0603|
7|OPEN|2|D3, D6|NA|NA|LED0603_M|OPEN|||?|Do not assemble
8|Ethernet Jack|1|J1|Molex|43202-8916|43202-8916||||CO-43202-8916|
9|MOLEX105017-0001|2|J2, J10|Molex|105017-0001|MOLEX105017-0001||||CO-USB-MICRO-SOLDERTAIL|
10|MMC|2|J3, J4|TE Connectivity|5120527-1|5120527-1||||CO-PMC64-120527-1|
11|IPMC|1|J5|Molex|87782-3009|87782-3007||||?|
12|IPMI JTAG|1|J6|Molex|87832-1420|87832-1420||||CO-PIN-HDR-2X7SS-2MM|
13|CTRL|1|J7|Molex|87782-3009|87782-3007||||?|
14|CTRL JTAG|1|J8|Molex|87832-1420|87832-1420||||CO-PIN-HDR-2X7SS-2MM|
15|CTRL ETH|1|J9|Molex|43202-8916|43202-8916||||CO-43202-8916|
16|Header 20X2|1|P1|?|?|HEADER2X20||||?|Do not assemble
17|MMC1 CTRL|1|P2|?|?|HEADER1X7||||?|Do not assemble
18|MMC0 CTRL|1|P3|?|?|HEADER1X7||||?|Do not assemble
19|JTAG Connect|1|P4|?|?|HEADER2X4||||?|
20|IPMC XVC to CTRL JTAG|1|P5|?|?|HEADER2X4||||?|
21|CTRL ADC-A|1|P6|?|?|HEADER1X9||||?|Do not assemble
22|PWREN|1|P7|?|?|HEADER1X3||||?|
23|CTRL ADC-B|1|P8|?|?|HEADER1X9||||?|Do not assemble
24|CTRL GPIO|1|P9|?|?|HEADER2X20||||?|Do not assemble
25|UWLVPWRMODV2-PAR|1|PM1|University of Wisconsin|UWLVPWRMODV2|UWLVPWRMODV2||||?|Refurbish from oRSCs
26|?|24|R1, R2, R3, R4, R5, R6, R9, R10, R12, R13, R14, R15, R16, R17, R18, R19, R20, R22, R23, R24, R25, R26, R28, R30|?, ?, NA, ?, ?, NA, Panasonic-ECG, Panasonic-ECG, ?, NA, NA, NA, NA, Panasonic-ECG, ?, Panasonic-ECG, ?, ?, ?, ?, Panasonic-ECG, Panasonic-ECG, Panasonic-ECG, Panasonic-ECG|?, ?, NA, ?, ?, NA, ERJ-2GEJ472X, ERJ-2GEJ103X, ?, NA, NA, NA, NA, ERJ-2GEJ103X, ?, ERJ-2GEJ103X, ?, ?, ?, ?, ERJ-2GEJ103X, ERJ-2GEJ103X, ERJ-2GEJ103X, ERJ-2GEJ472X|R0402_IPC_H|681, 681, OPEN, 681, 681, OPEN, 4.7K, 10k, 681, OPEN, OPEN, OPEN, OPEN, 10k, 681, 10k, 681, 681, 332, 681, 10k, 10k, 10k, 4.7K||1%, 1%, 1%, 1%, 1%, 1%, 5%, 5%, 1%, 1%, 1%, 1%, 1%, 5%, 1%, 5%, 1%, 1%, 1%, 1%, 5%, 5%, 5%, 5%|?, ?, RS0402-OPEN-1/10W, ?, ?, RS0402-OPEN-1/10W, RS0402-4K7-1/10W-5%, RS0402-10K-1/10W-5%, ?, RS0402-OPEN-1/10W, RS0402-OPEN-1/10W, RS0402-OPEN-1/10W, RS0402-OPEN-1/10W, RS0402-10K-1/10W-5%, ?, RS0402-10K-1/10W-5%, ?, ?, ?, ?, RS0402-10K-1/10W-5%, RS0402-10K-1/10W-5%, RS0402-10K-1/10W-5%, RS0402-4K7-1/10W-5%|[NoValue], [NoValue], Do not assemble, [NoValue], [NoValue], Do not assemble, [NoValue], [NoValue], [NoValue], Do not assemble, Do not assemble, Do not assemble, Do not assemble, [NoValue], [NoValue], [NoValue], [NoValue], [NoValue], [NoValue], [NoValue], [NoValue], [NoValue], [NoValue], [NoValue]
27|27|4|R7, R8, R31, R32|?|?|R0603|27|||?|
28|100|4|R11, R21, R27, R29|Yageo|RC0603FR-07100RL|R0603|100|||RS0603-100R-1/10W-1%|
29|?|2|R33, R34|Panasonic-ECG|ERA-2AEB4531X, ERJ-2RKF26R1X|R0402|4.53k, 26.1||0.1%, 1%|RS0402-4K53-1/16W-PREC, RS0402-26R1-1/10W-1%|
30|SW-DIP-8|3|SW1, SW2, SW4|C&K|TDA08HOSB1|TDA08H0||||SW-DIP-8X-SMD|
31|DTSM-61NT/R|2|SW3, SW5|?|?|DIPT-DTSM-6_V||||?|
32|TP|1|TP1|NA|NA|TP||||NA|Not a part
33|FT234XD-T|2|U1, U3|?|?|DFN-12_V||||?|
34|ADR5040|1|U2|Analog Devices|ADR5040ARTZ|SOT23-H||||VREF-ADR5040A-SOT23|

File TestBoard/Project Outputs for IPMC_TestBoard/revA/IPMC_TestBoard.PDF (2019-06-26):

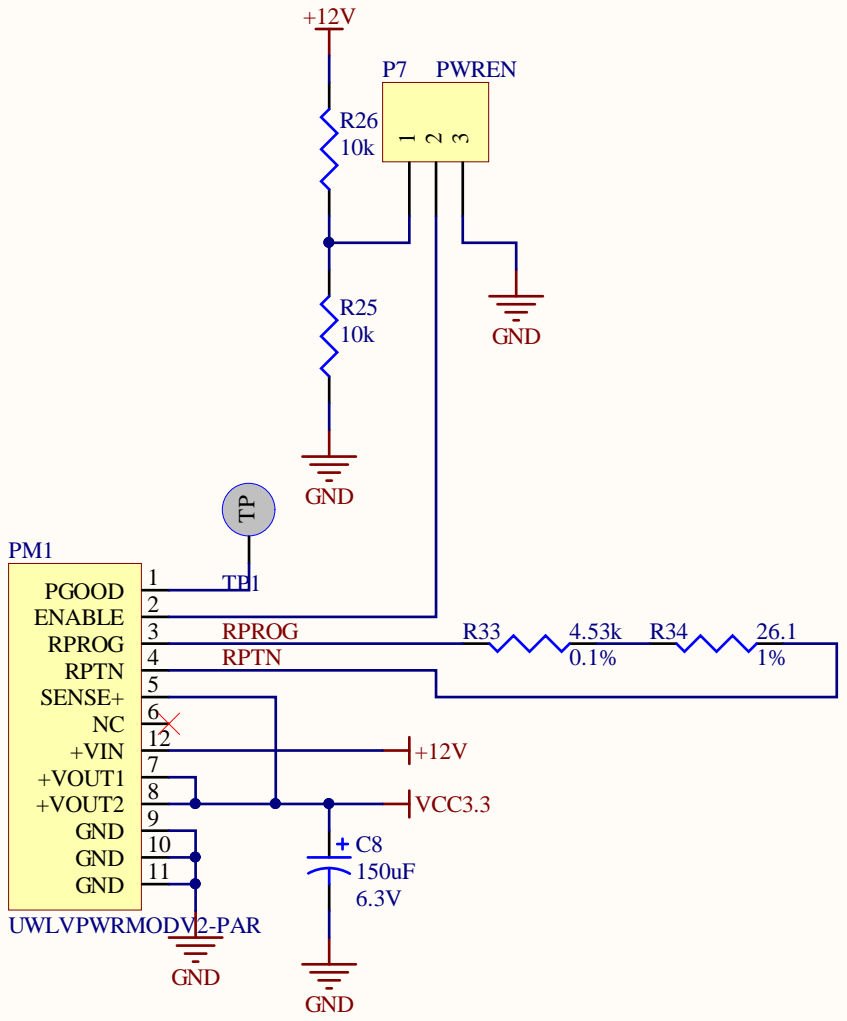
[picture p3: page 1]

ZYNQ-IPMC Test Board Title | Univ. of Wisconsin-Madison Madison, WI 53706

Size: A3 | Number: 1 | Revision: revA1

Date: 6/26/2019 Time: 2:09:58 PM | | Sheet of
File: IPMC_TestBoard.SchDoc | Author: Marcelo Vicente

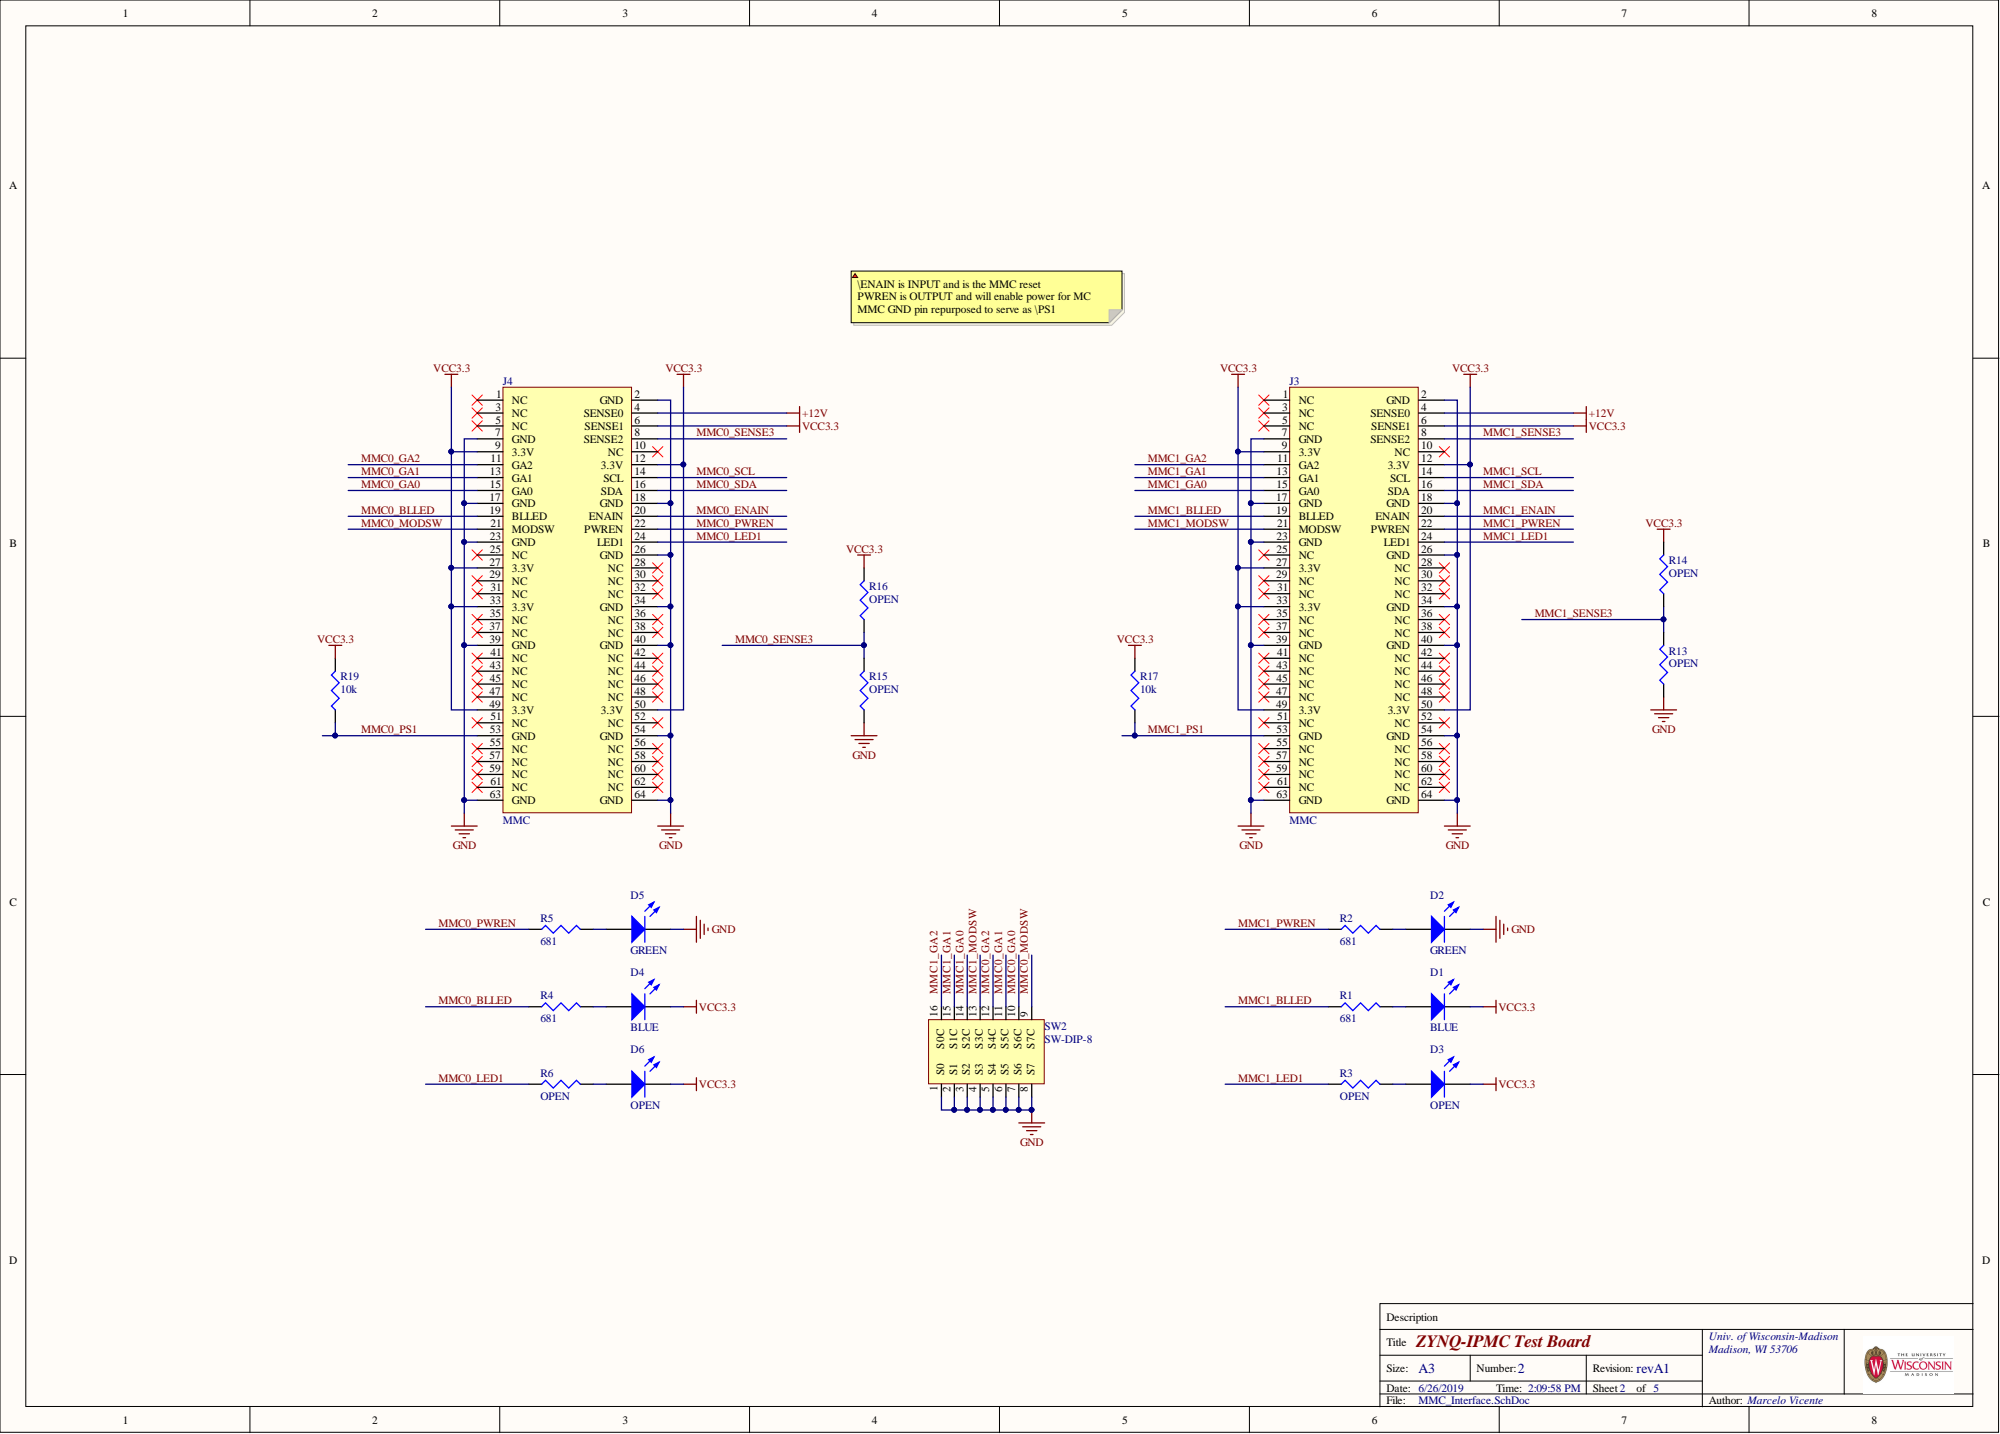
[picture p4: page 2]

\ENAIN is INPUT and is the MMC reset
PWREN is OUTPUT and will enable power for MC
MMC GND pin repurposed to serve as \PS1

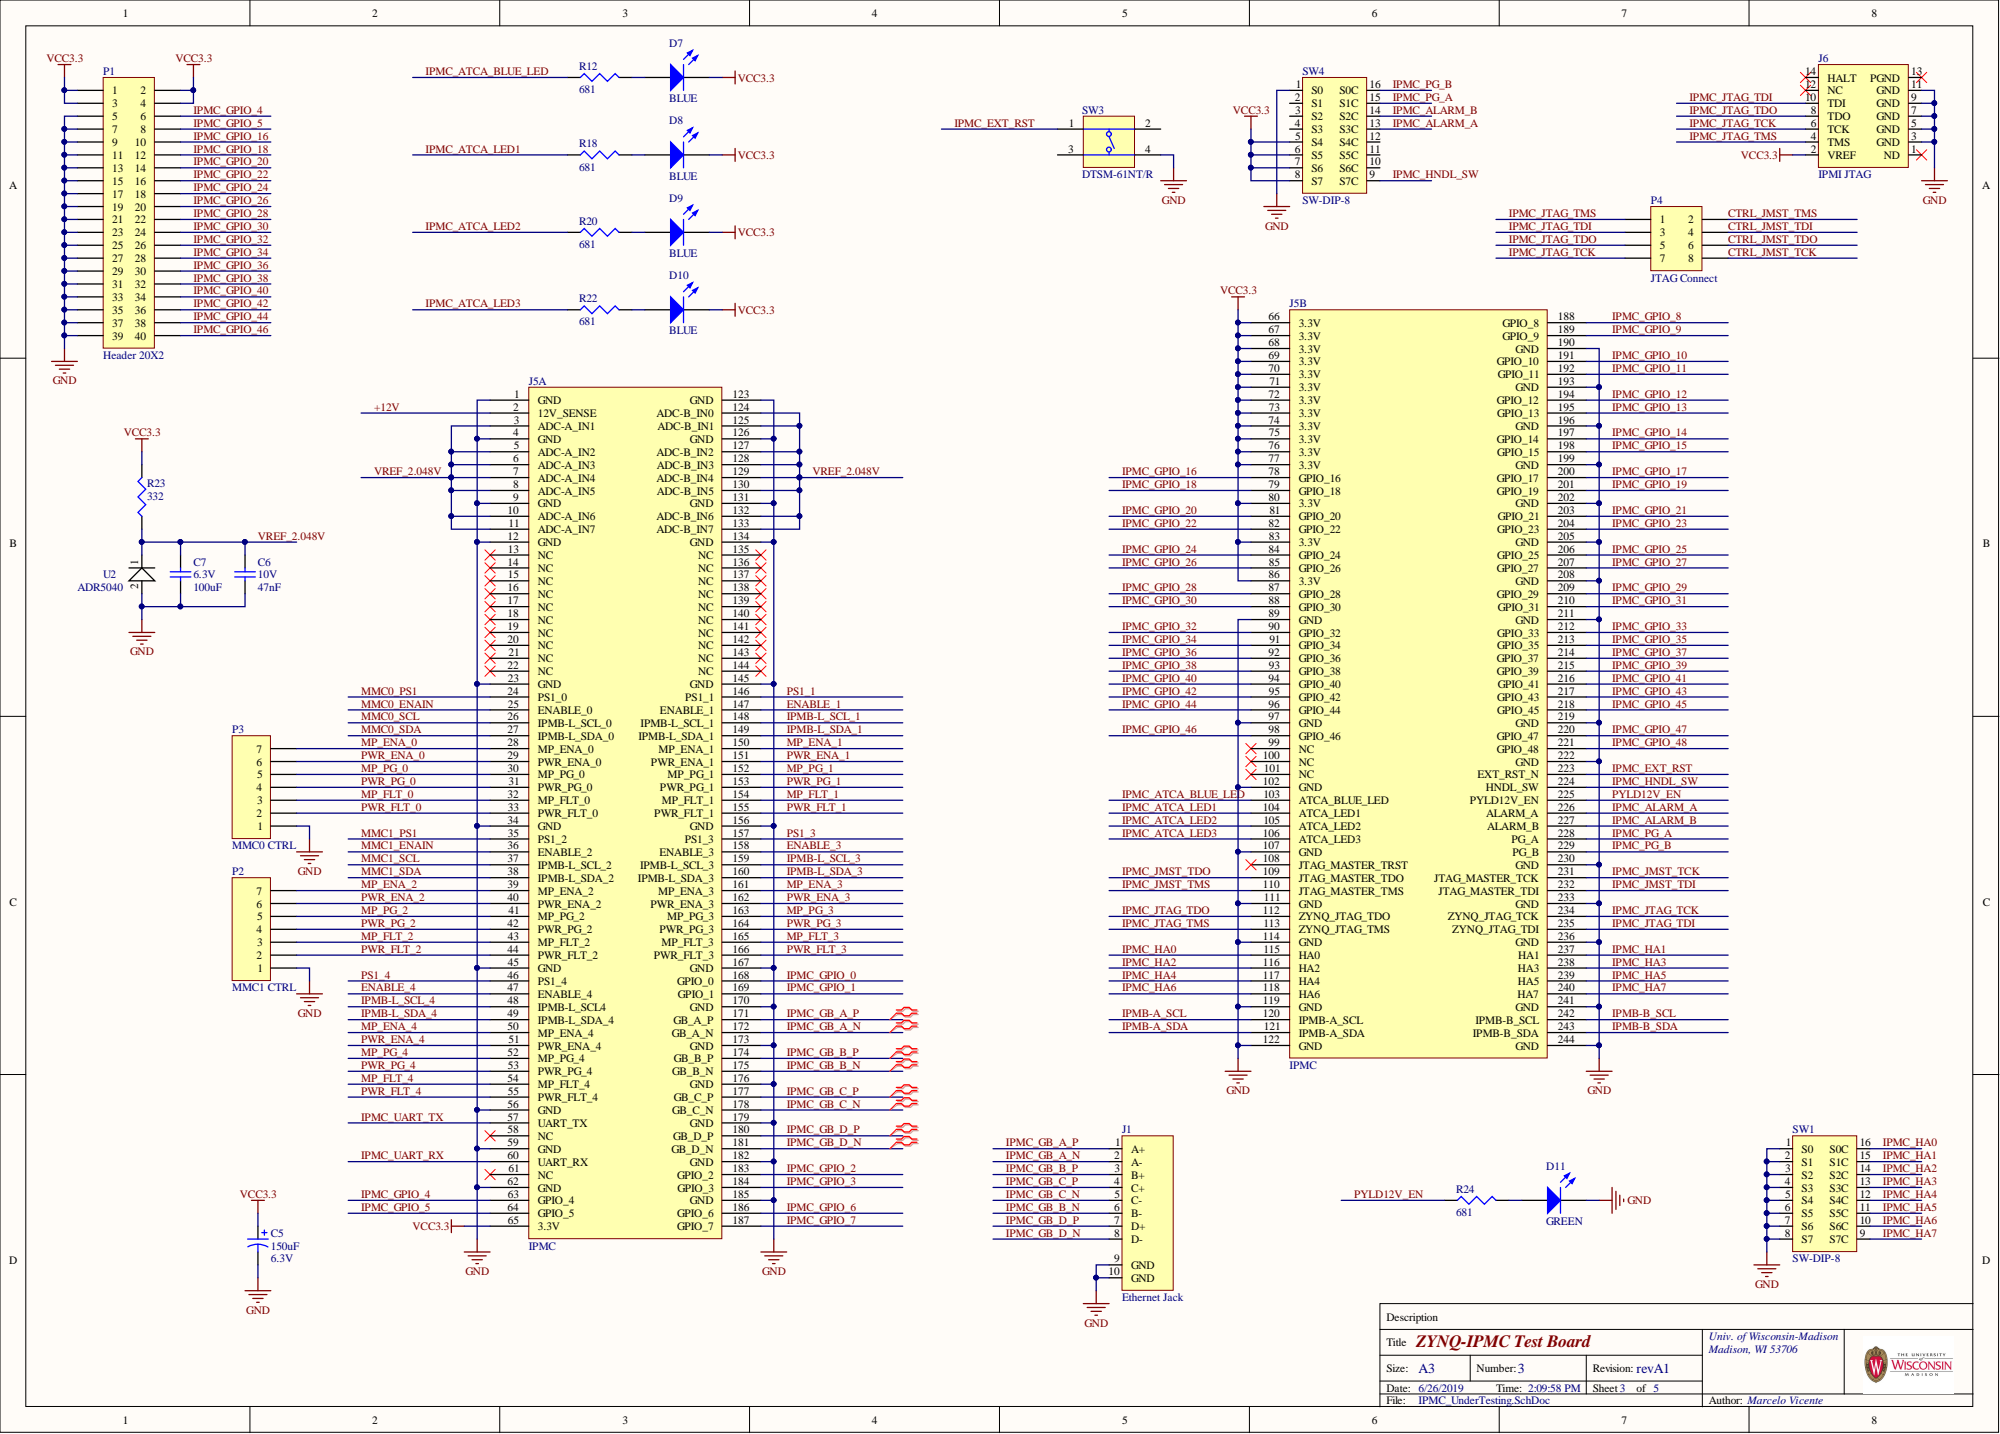
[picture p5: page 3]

ZYNQ -IPMC Te st Board Titl | Uni v . of Wisc o nsin-Madiso n Mad i s on, WI 53

S i z : A | Number: | R visi o n : r e v A

Date : 6/2 6/2 Ti m : : P M | | S h t o f
F ile : I P M C _ UnderTe sti n g . S c hDo c | Auth or: Mar c l o Vi c nte

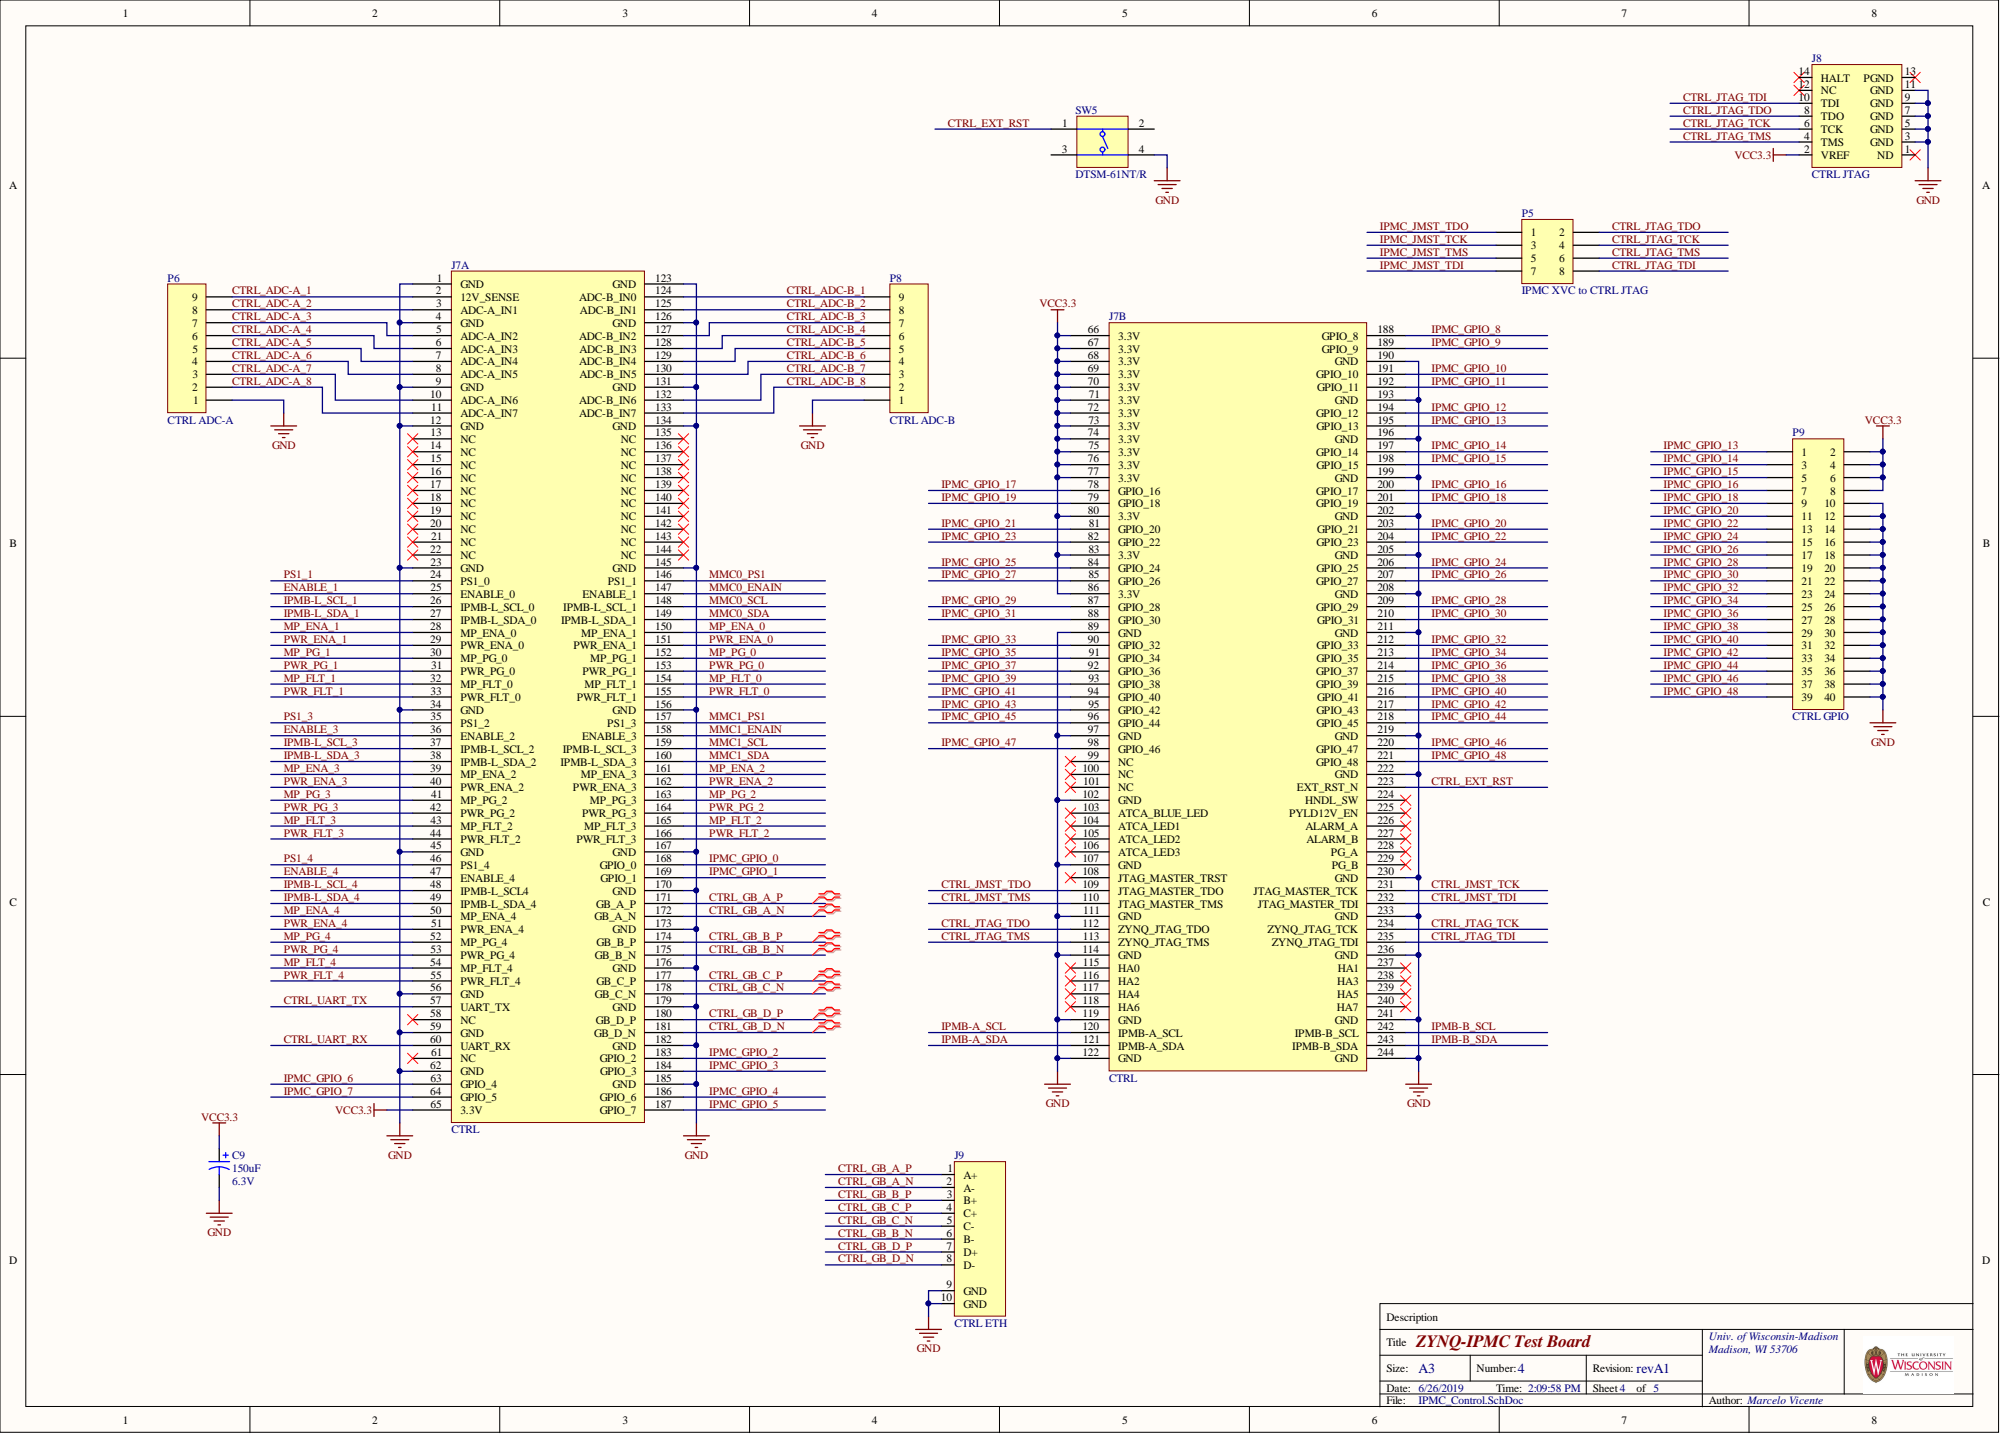
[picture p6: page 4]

CTR L_ ADC-A_ 2 | 3 | 125 | CTR L_ ADC-B _ 2
CTR L_ ADC-A_ 3 | 4 | 126 | CTR L_ ADC-B _ 3
CTR L_ ADC-A_ 4 | 5 | | 127 | CTR L_ ADC-B _ 4

ZYNQ -IPMC Te st Board Titl | Uni v . of Wisc o nsin-Madiso n Mad i s on, WI 53

S i z : A | Number: | R visi o n : r v A

Date : 6/2 6/2 Ti m : : P M | | S h t o f
F ile : I P M C _ C ontro l . S chDo c | Auth or: Mar c l o Vi c nte

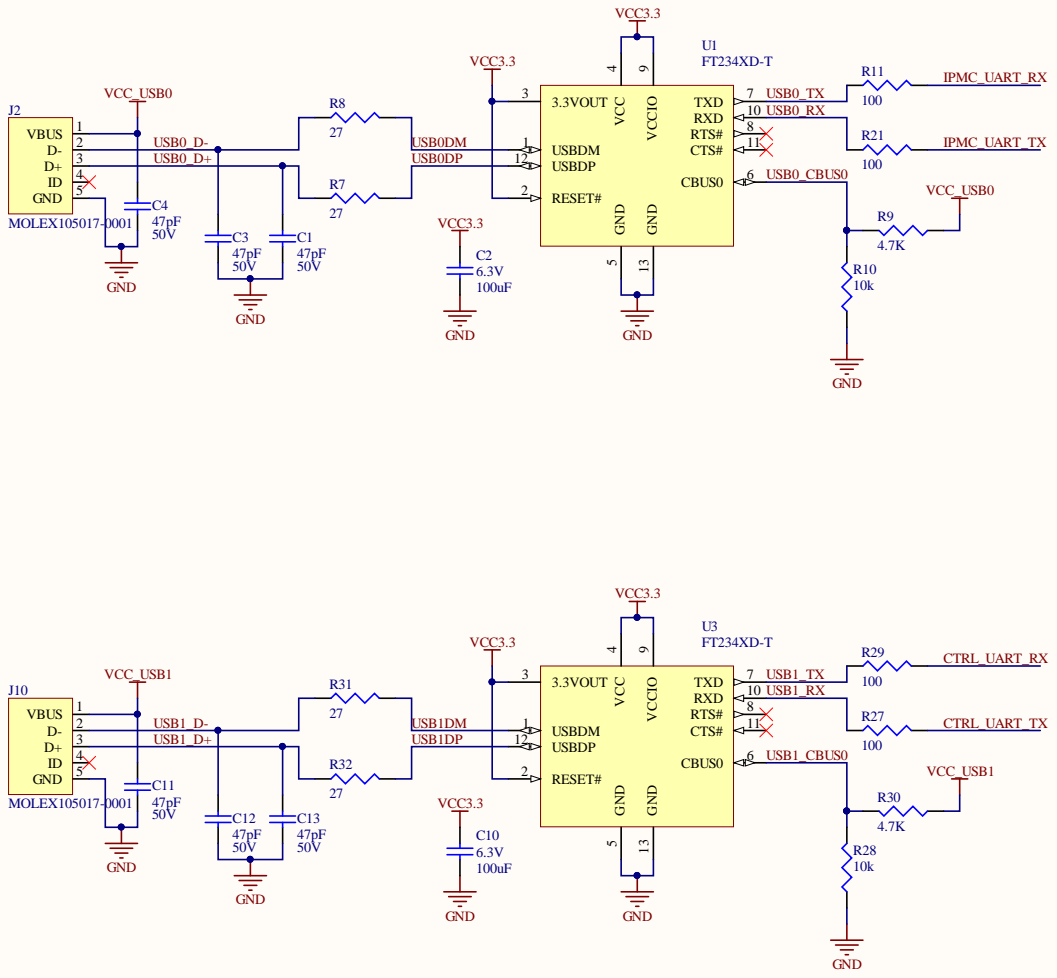
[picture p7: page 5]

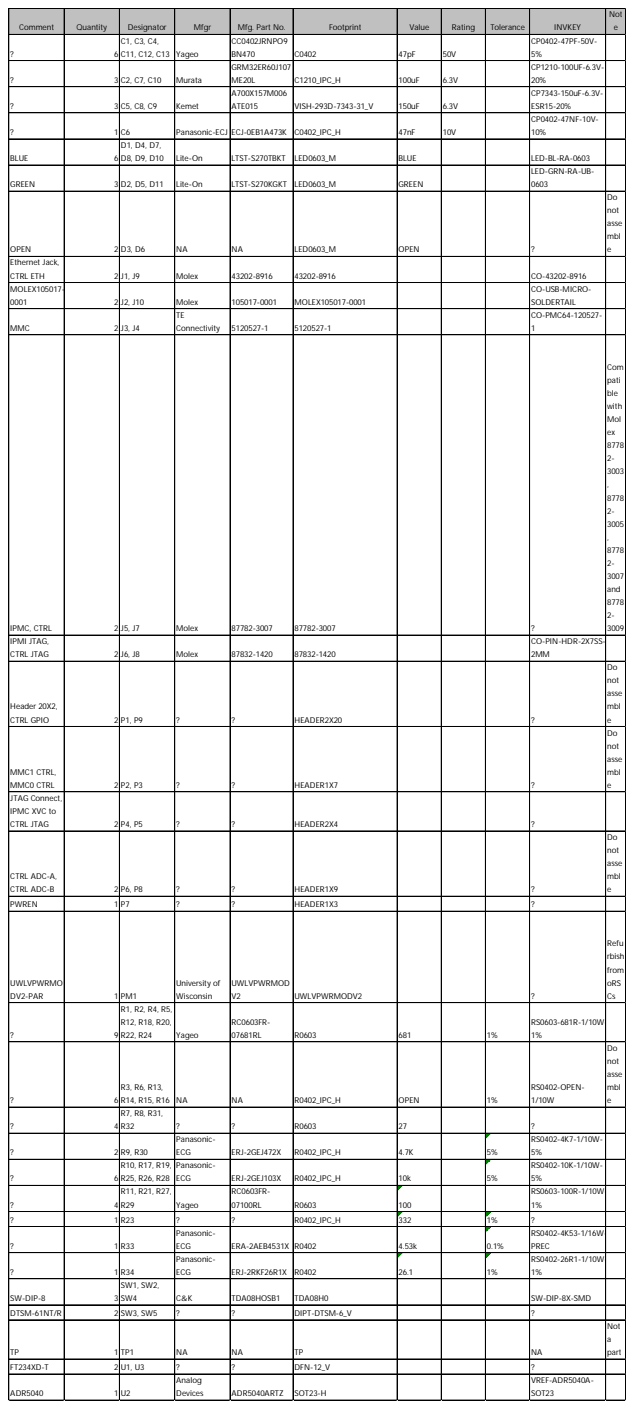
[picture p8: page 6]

Comment | Quantity | Designator | Mfgr | Mfg. Part No. | Footprint | Value | Rating | Tolerance | INVKEY | Not

C1, C3, C4, C11, C12, C13 | Yageo | CC0402JRNPO9 BN470 | C0402 | 47pF | 50V | | CP0402-47PF-50V-5%

? | | 3 C2, C7, C10 | Murata | GRM32ER60J107 ME20L | C1210_IPC_H | 100uF | 6.3V | | CP1210-100UF-6.3V-20%

? | | 3 C5, C8, C9 | Kemet | A700X157M006 ATE015 | VISH-293D-7343-31_V | 150uF | 6.3V | | CP7343-150uF-6.3V-ESR15-20%

? | | 1 C6 | Panasonic-ECJ | ECJ-0EB1A473K | C0402_IPC_H | 47nF | 10V | | CP0402-47NF-10V-10%

BLUE | | D1, D4, D7, 6 D8, D9, D10 | Lite-On | LTST-S270TBKT | LED0603_M | BLUE | | | LED-BL-RA-0603

GREEN | | 3 D2, D5, D11 | Lite-On | LTST-S270KGKT | LED0603_M | GREEN | | | LED-GRN-RA-UB-0603

OPEN | | 2 D3, D6 | NA | NA | LED0603_M | OPEN | | | ? | Do not asse mbl e

Ethernet Jack, CTRL ETH | | 2 J1, J9 | Molex | 43202-8916 | 43202-8916 | | | | CO-43202-8916

MOLEX105017-0001 | | 2 J2, J10 | Molex | 105017-0001 | MOLEX105017-0001 | | | | CO-USB-MICRO-SOLDERTAIL

MMC | | 2 J3, J4 | TE Connectivity | 5120527-1 | 5120527-1 | | | | CO-PMC64-120527-1

IPMC, CTRL | | 2 J5, J7 | Molex | 87782-3007 | 87782-3007 | | | | ? | Com pati ble with Mol ex 8778 2-3003 , 8778 2-3005 , 8778 2-3007 and 8778 2-3009

IPMI JTAG, CTRL JTAG | | 2 J6, J8 | Molex | 87832-1420 | 87832-1420 | | | | CO-PIN-HDR-2X7SS-2MM

Header 20X2, CTRL GPIO | | 2 P1, P9 | ? | ? | HEADER2X20 | | | | ? | Do not asse mbl e

MMC1 CTRL, MMC0 CTRL | | 2 P2, P3 | ? | ? | HEADER1X7 | | | | ? | Do not asse mbl e

JTAG Connect, IPMC XVC to CTRL JTAG | | 2 P4, P5 | ? | ? | HEADER2X4 | | | | ?

CTRL ADC-A, CTRL ADC-B | | 2 P6, P8 | ? | ? | HEADER1X9 | | | | ? | Do not asse mbl e

PWREN | | 1 P7 | ? | ? | HEADER1X3 | | | | ?

UWLVPWRMO DV2-PAR | | 1 PM1 | University of Wisconsin | UWLVPWRMOD V2 | UWLVPWRMODV2 | | | | ? | Refu rbish from oRS Cs

? | | R1, R2, R4, R5, R12, R18, R20, 9 R22, R24 | Yageo | RC0603FR-07681RL | R0603 | 681 | | 1% | RS0603-681R-1/10W-1%

? | | R3, R6, R13, 6 R14, R15, R16 | NA | NA | R0402_IPC_H | OPEN | | 1% | RS0402-OPEN-1/10W | Do not asse mbl e

? | | 2 R9, R30 | Panasonic-ECG | ERJ-2GEJ472X | R0402_IPC_H | 4.7K | | 5% | RS0402-4K7-1/10W-5%

? | | R10, R17, R19, 6 R25, R26, R28 | Panasonic-ECG | ERJ-2GEJ103X | R0402_IPC_H | 10k | | 5% | RS0402-10K-1/10W-5%

? | | R11, R21, R27, 4 R29 | Yageo | RC0603FR-07100RL | R0603 | 100 | | | RS0603-100R-1/10W-1%

? | | 1 R23 | ? | ? | R0402_IPC_H | 332 | | 1% | ?
? | | 1 R33 | Panasonic-ECG | ERA-2AEB4531X | R0402 | 4.53k | | 0.1% | RS0402-4K53-1/16W-PREC

? | | 1 R34 | Panasonic-ECG | ERJ-2RKF26R1X | R0402 | 26.1 | | 1% | RS0402-26R1-1/10W-1%

SW-DIP-8 | | SW1, SW2, 3 SW4 | C&K | TDA08HOSB1 | TDA08H0 | | | | SW-DIP-8X-SMD

DTSM-61NT/R | | 2 SW3, SW5 | ? | ? | DIPT-DTSM-6_V | | | | ?
TP | | 1 TP1 | NA | NA | TP | | | | NA | Not a part

FT234XD-T | | 2 U1, U3 | ? | ? | DFN-12_V | | | | ?
ADR5040 | | 1 U2 | Analog Devices | ADR5040ARTZ | SOT23-H | | | | VREF-ADR5040A-SOT23

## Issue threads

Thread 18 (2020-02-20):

Use gerber layout in online gerber viewer

NilsMinor, 2020-02-20:
Hey UW Madison CMS Group,

My name is Nils, my company is building an online gerber viewer and we are looking for some good looking example projects. We would like to add the ZYNQ IMPC gerber files as an example project into our viewer. As it is released under MIT License it should not be a problem but I wanted to ask anyway.

The viewer will be available under stackrate.de/viewer (anytime soon)

Thanks,
Nils

jtikalsky, 2020-02-20:
Sure, no problem.

Closed 2020-02-20.

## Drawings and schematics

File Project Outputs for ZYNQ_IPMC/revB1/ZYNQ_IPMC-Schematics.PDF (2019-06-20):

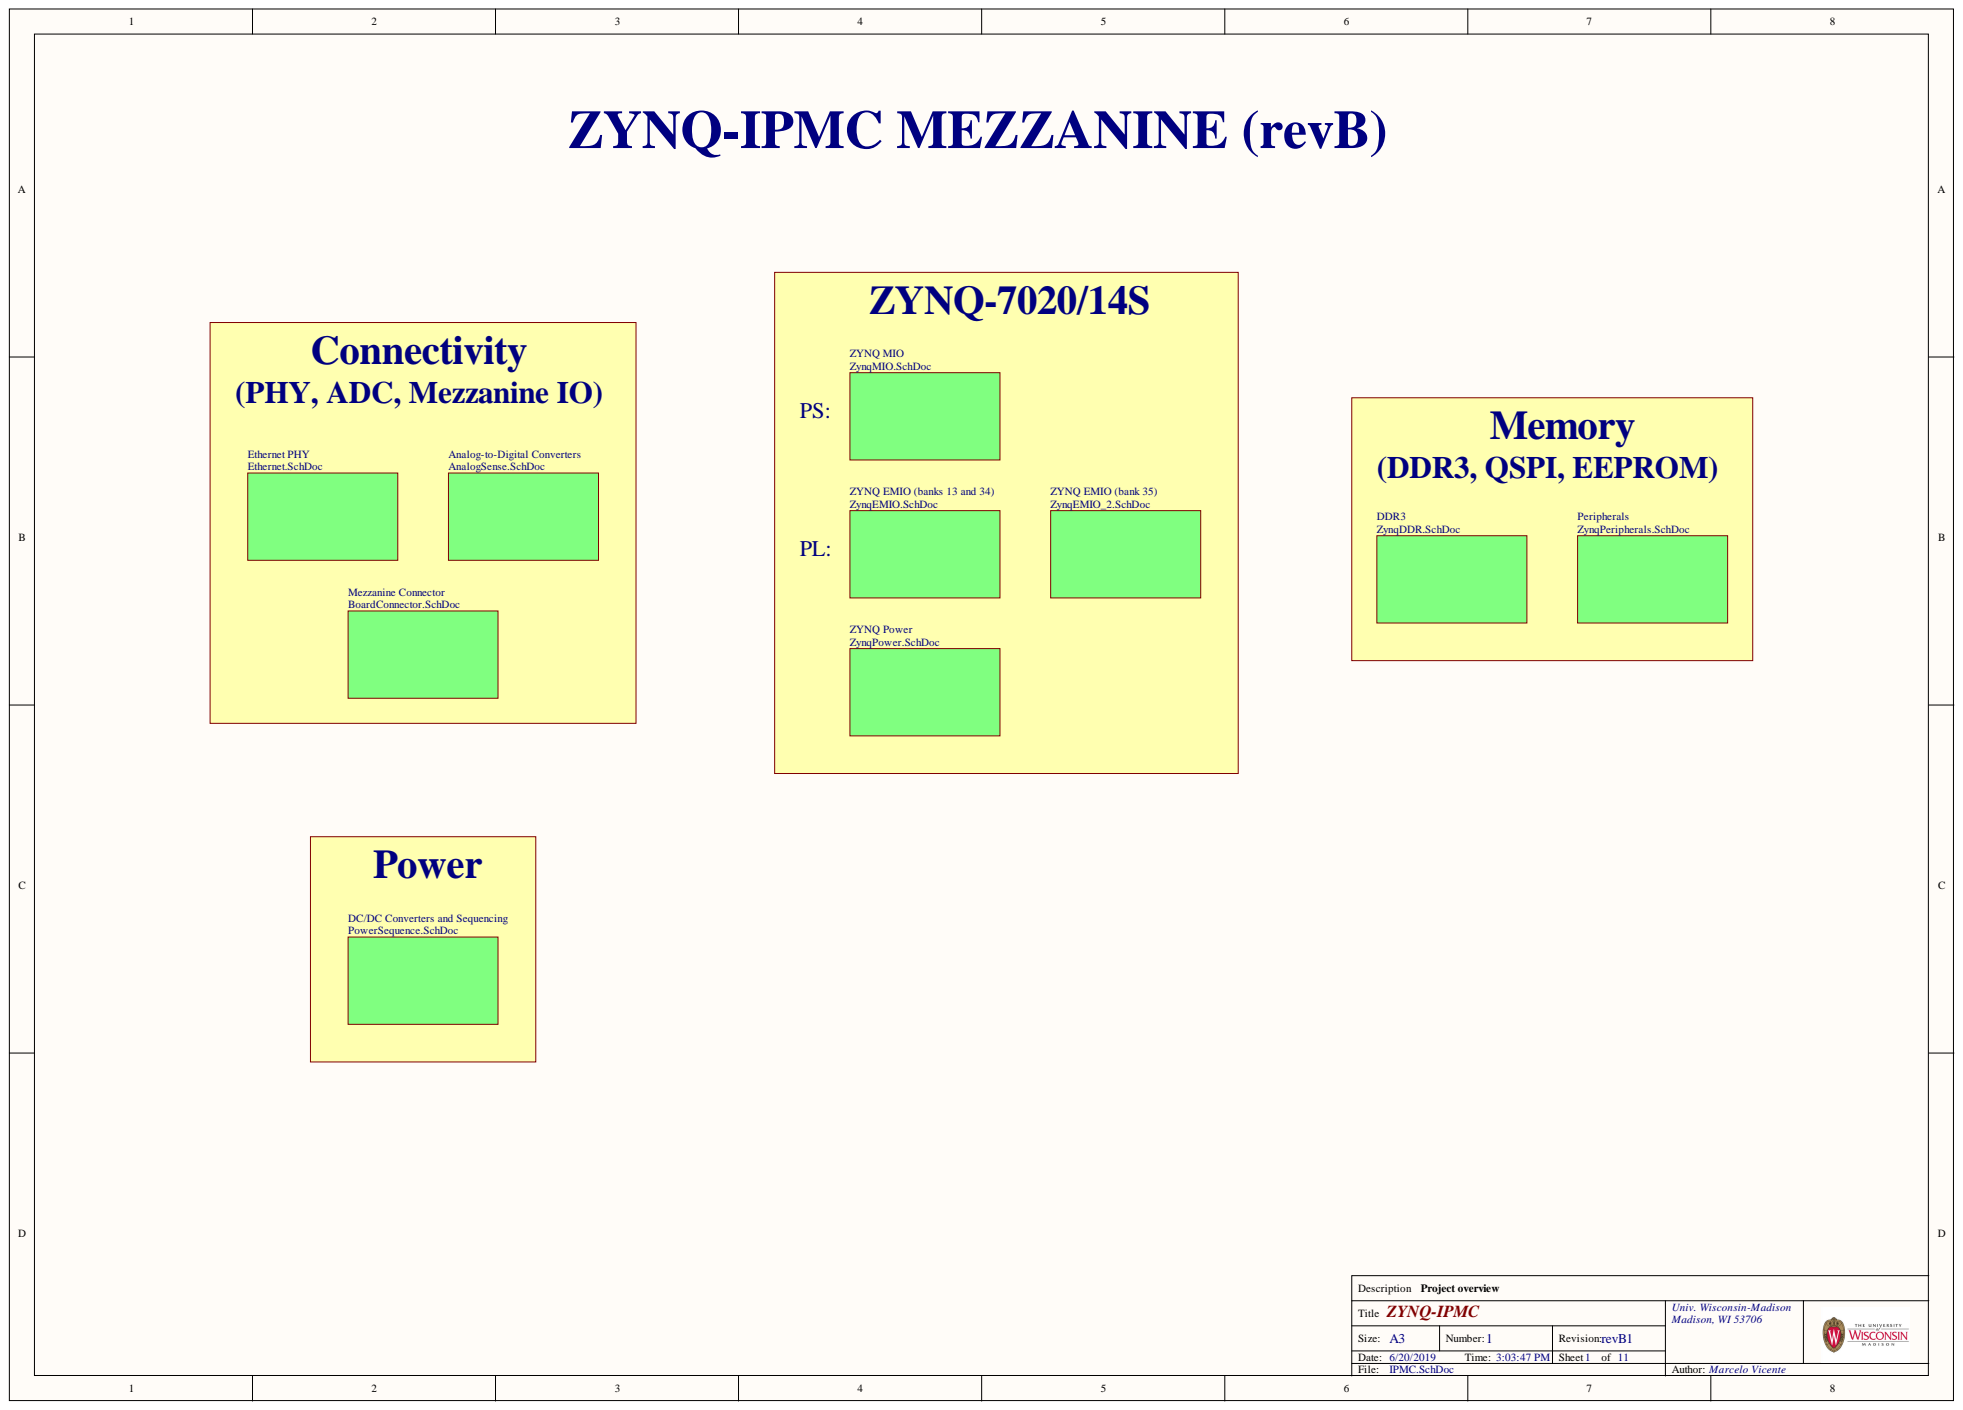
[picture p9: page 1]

ZYNQ-IPMC MEZZANINE (revB)

Connectivity
(PHY, ADC, Mezzanine IO)

Analog-to-Digital Converters
AnalogSense.SchDoc

ZYNQ EMIO (banks 13 and 34)
ZynqEMIO.SchDoc

DC/DC Converters and Sequencing
PowerSequence.SchDoc

ZYNQ-IPMC Title | Univ. Wisconsin-Madison Madison, WI 53706

Size: A3 | Number: 1 | Revision: revB1

Date: 6/20/2019 Time: 3:03:47 PM | | Sheet of
File: IPMC.SchDoc | Author: Marcelo Vicente

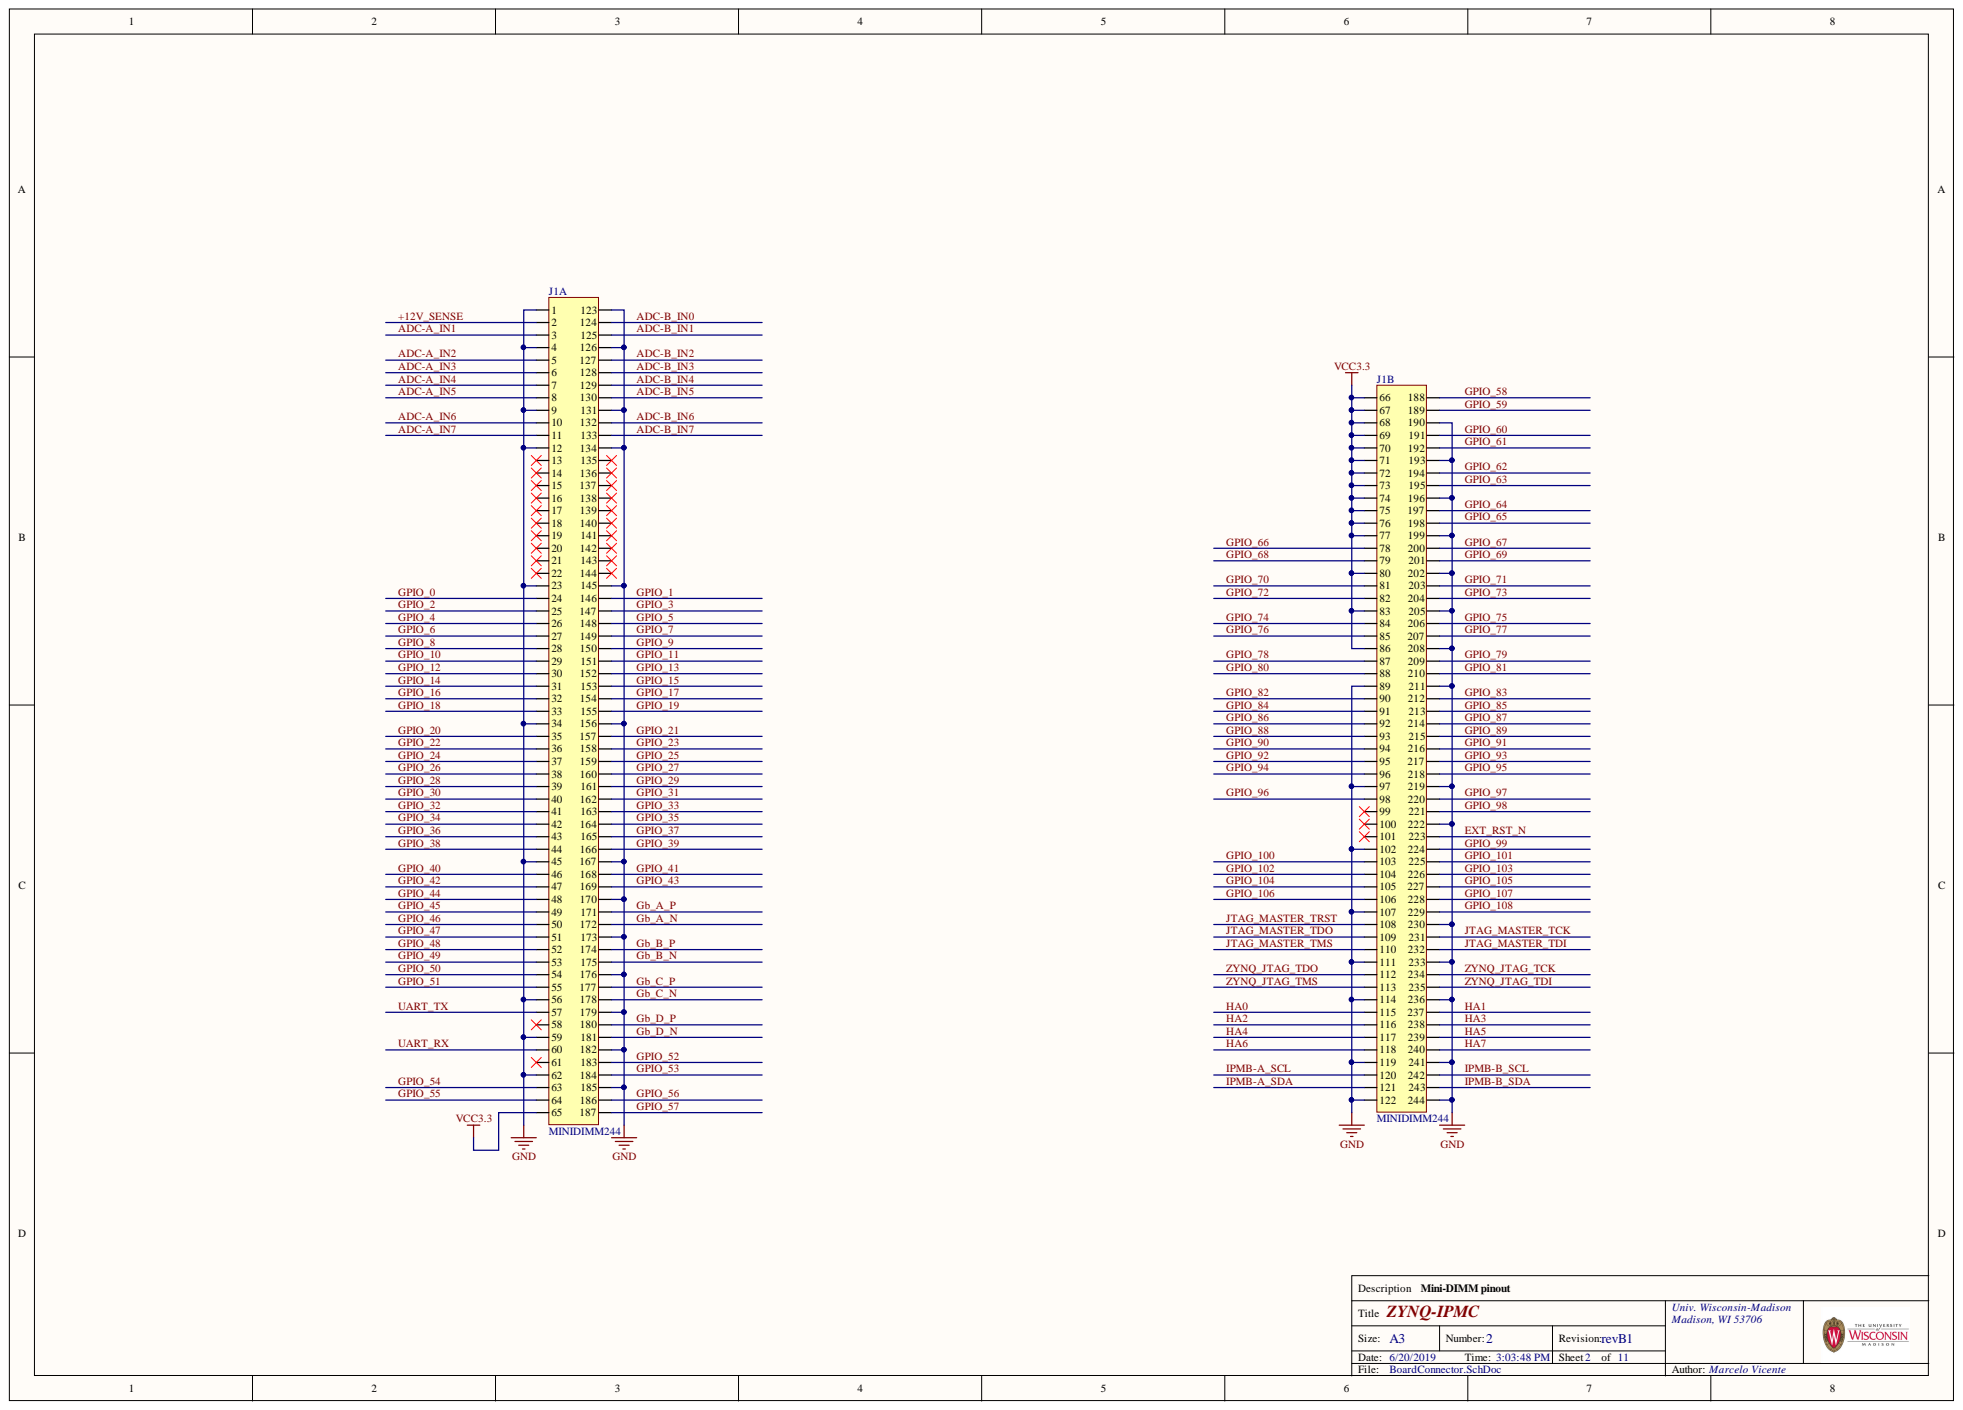
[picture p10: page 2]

ZYNQ IPMC T tl | Un i v . Wi s c o n -M a d n, WI

S z : A | Nu mb 2 | Re revB

Da / me : 8 P | | h f
F l Bo r dCo nn e t r.S hDo | Au th Vi

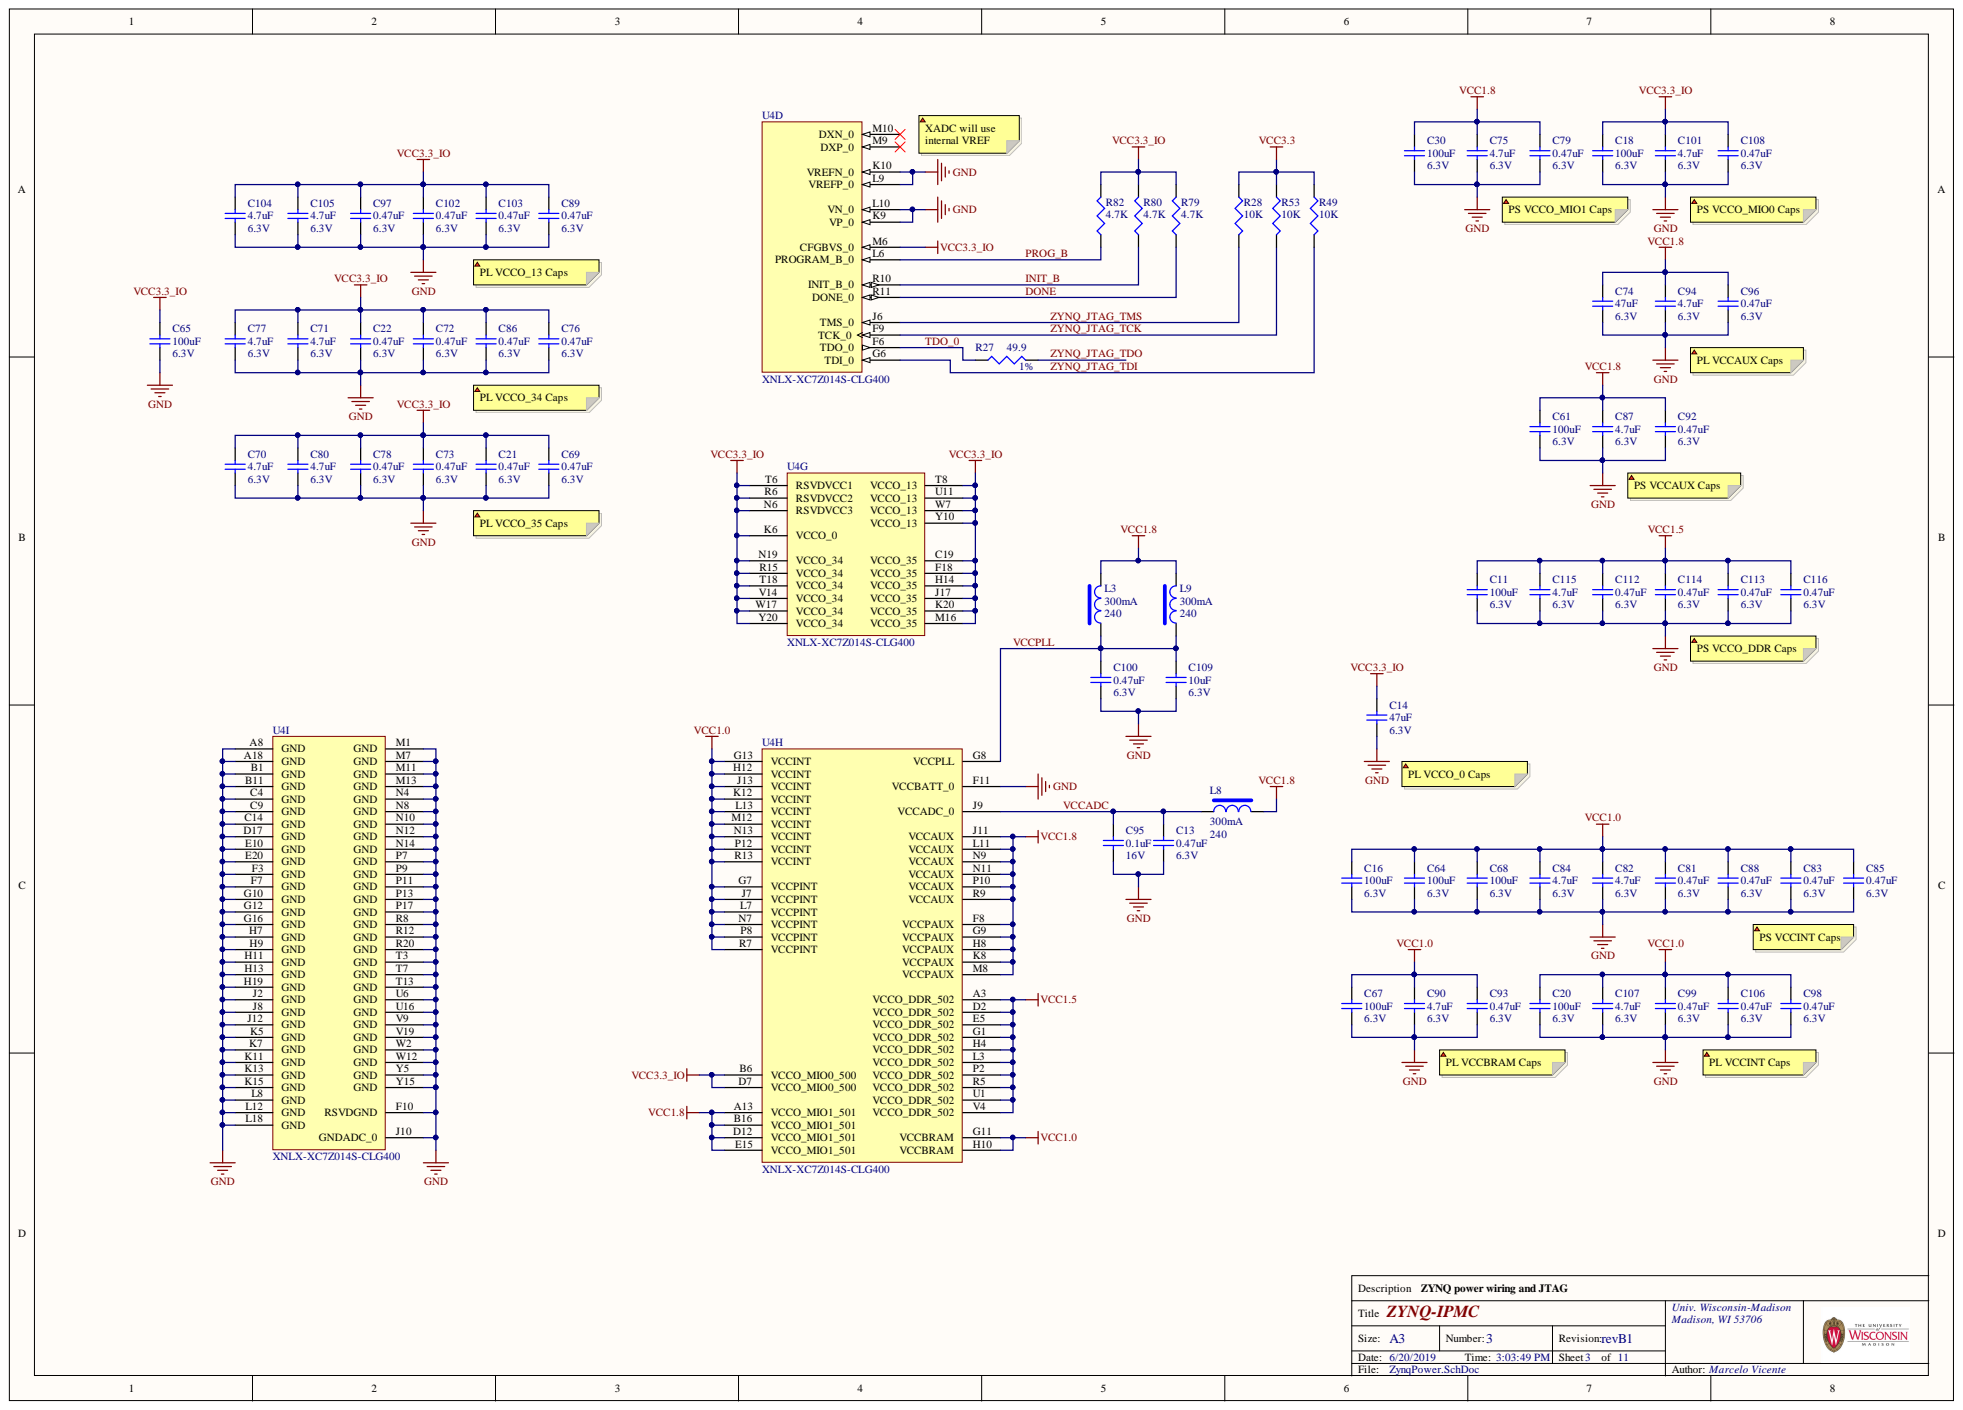
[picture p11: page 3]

ZYNQ power wiring and JTAG

6/20/2019 3:03:49 PM
ZynqPower.SchDoc

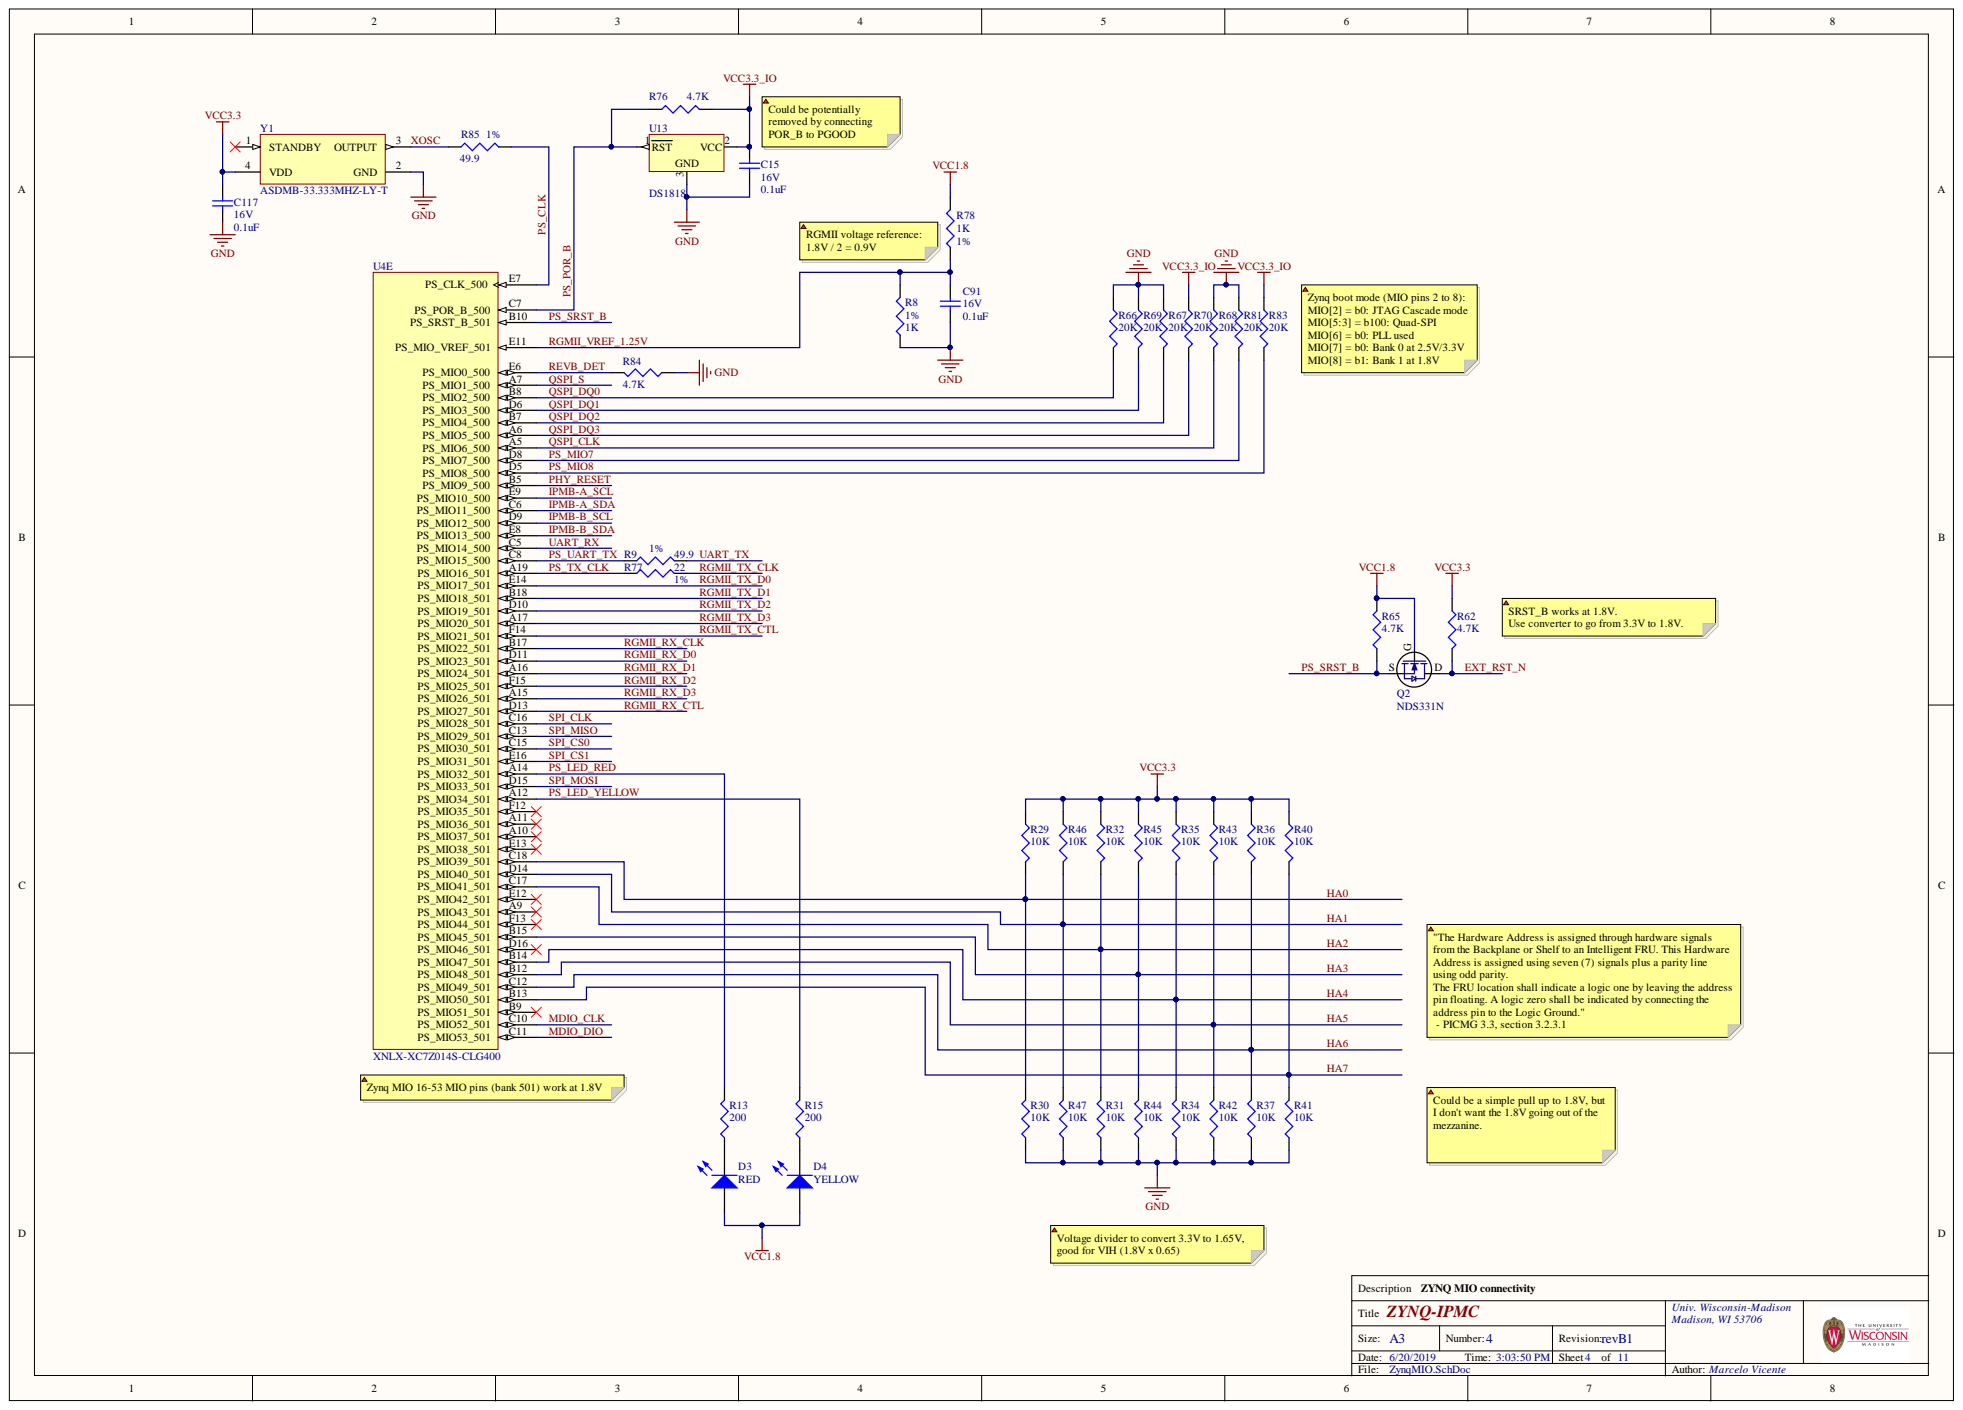
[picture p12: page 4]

Zynq boot mode (MIO pins 2 to 8):
MIO[2] = b0: JTAG Cascade mode
MIO[5:3] = b100: Quad-SPI
MIO[6] = b0: PLL used
MIO[7] = b0: Bank 0 at 2.5V/3.3V
MIO[8] = b1: Bank 1 at 1.8V

SRST_B works at 1.8V.
Use converter to go from 3.3V to 1.8V.

"The Hardware Address is assigned through hardware signals
from the Backplane or Shelf to an Intelligent FRU. This Hardware
Address is assigned using seven (7) signals plus a parity line
using odd parity.
The FRU location shall indicate a logic one by leaving the address
pin floating. A logic zero shall be indicated by connecting the
address pin to the Logic Ground."
- PICMG 3.3, section 3.2.3.1

Zynq MIO 16-53 MIO pins (bank 501) work at 1.8V

Could be a simple pull up to 1.8V, but
I don't want the 1.8V going out of the
mezzanine.

Voltage divider to convert 3.3V to 1.65V,
good for VIH (1.8V x 0.65)

6/20/2019 3:03:50 PM
ZynqMIO.SchDoc

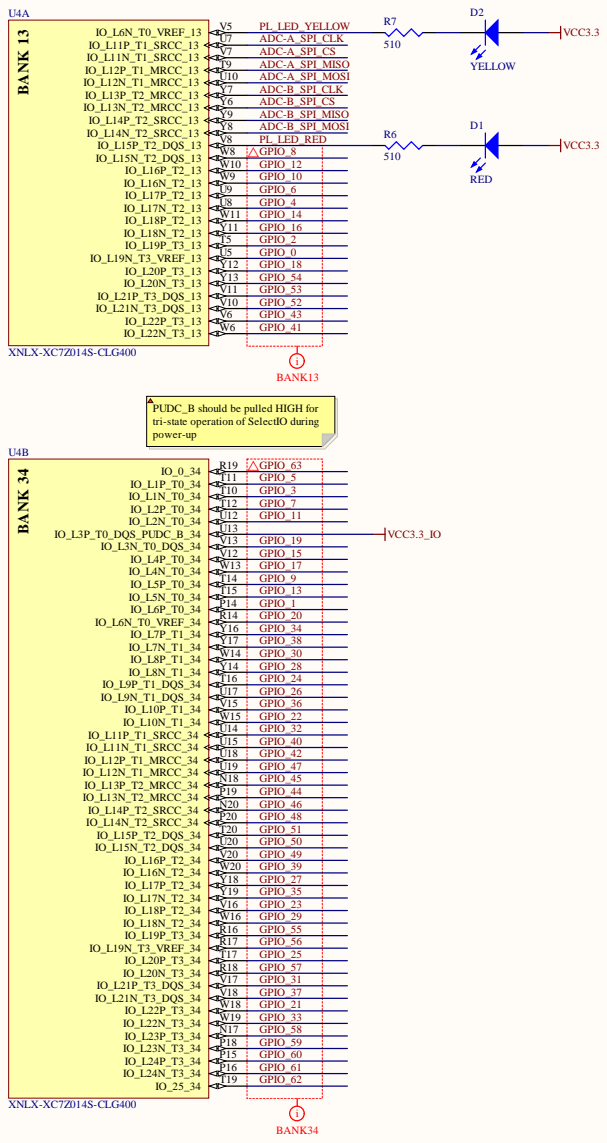
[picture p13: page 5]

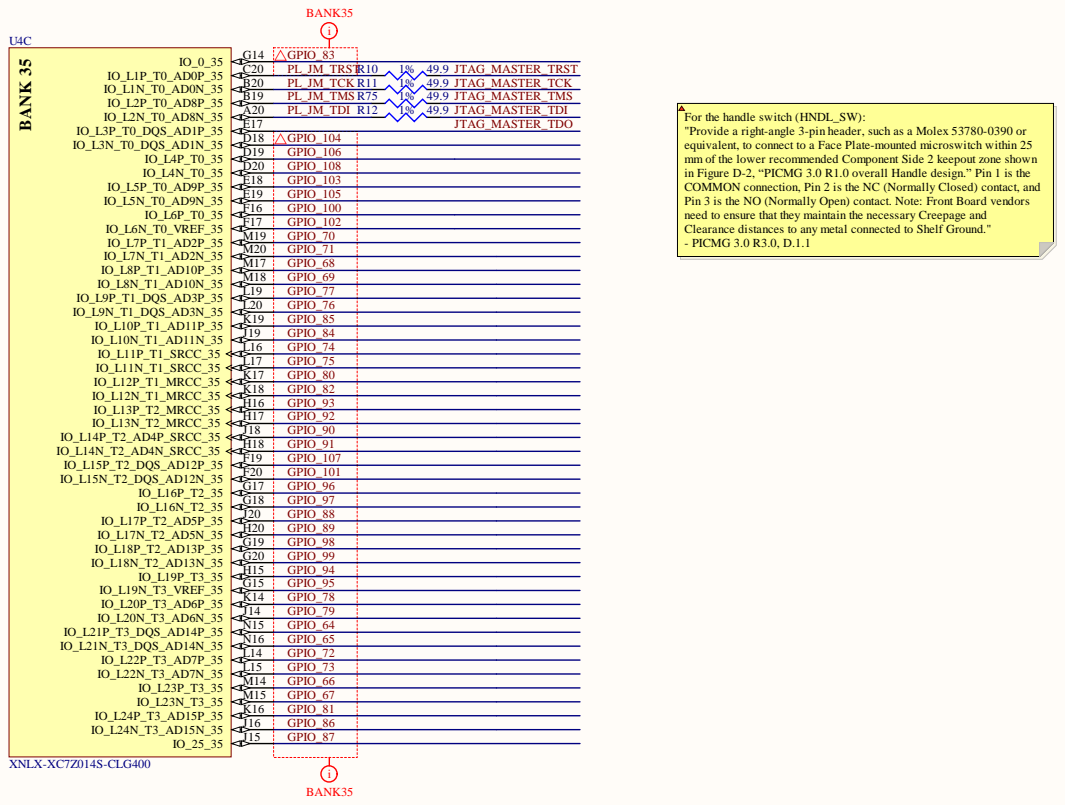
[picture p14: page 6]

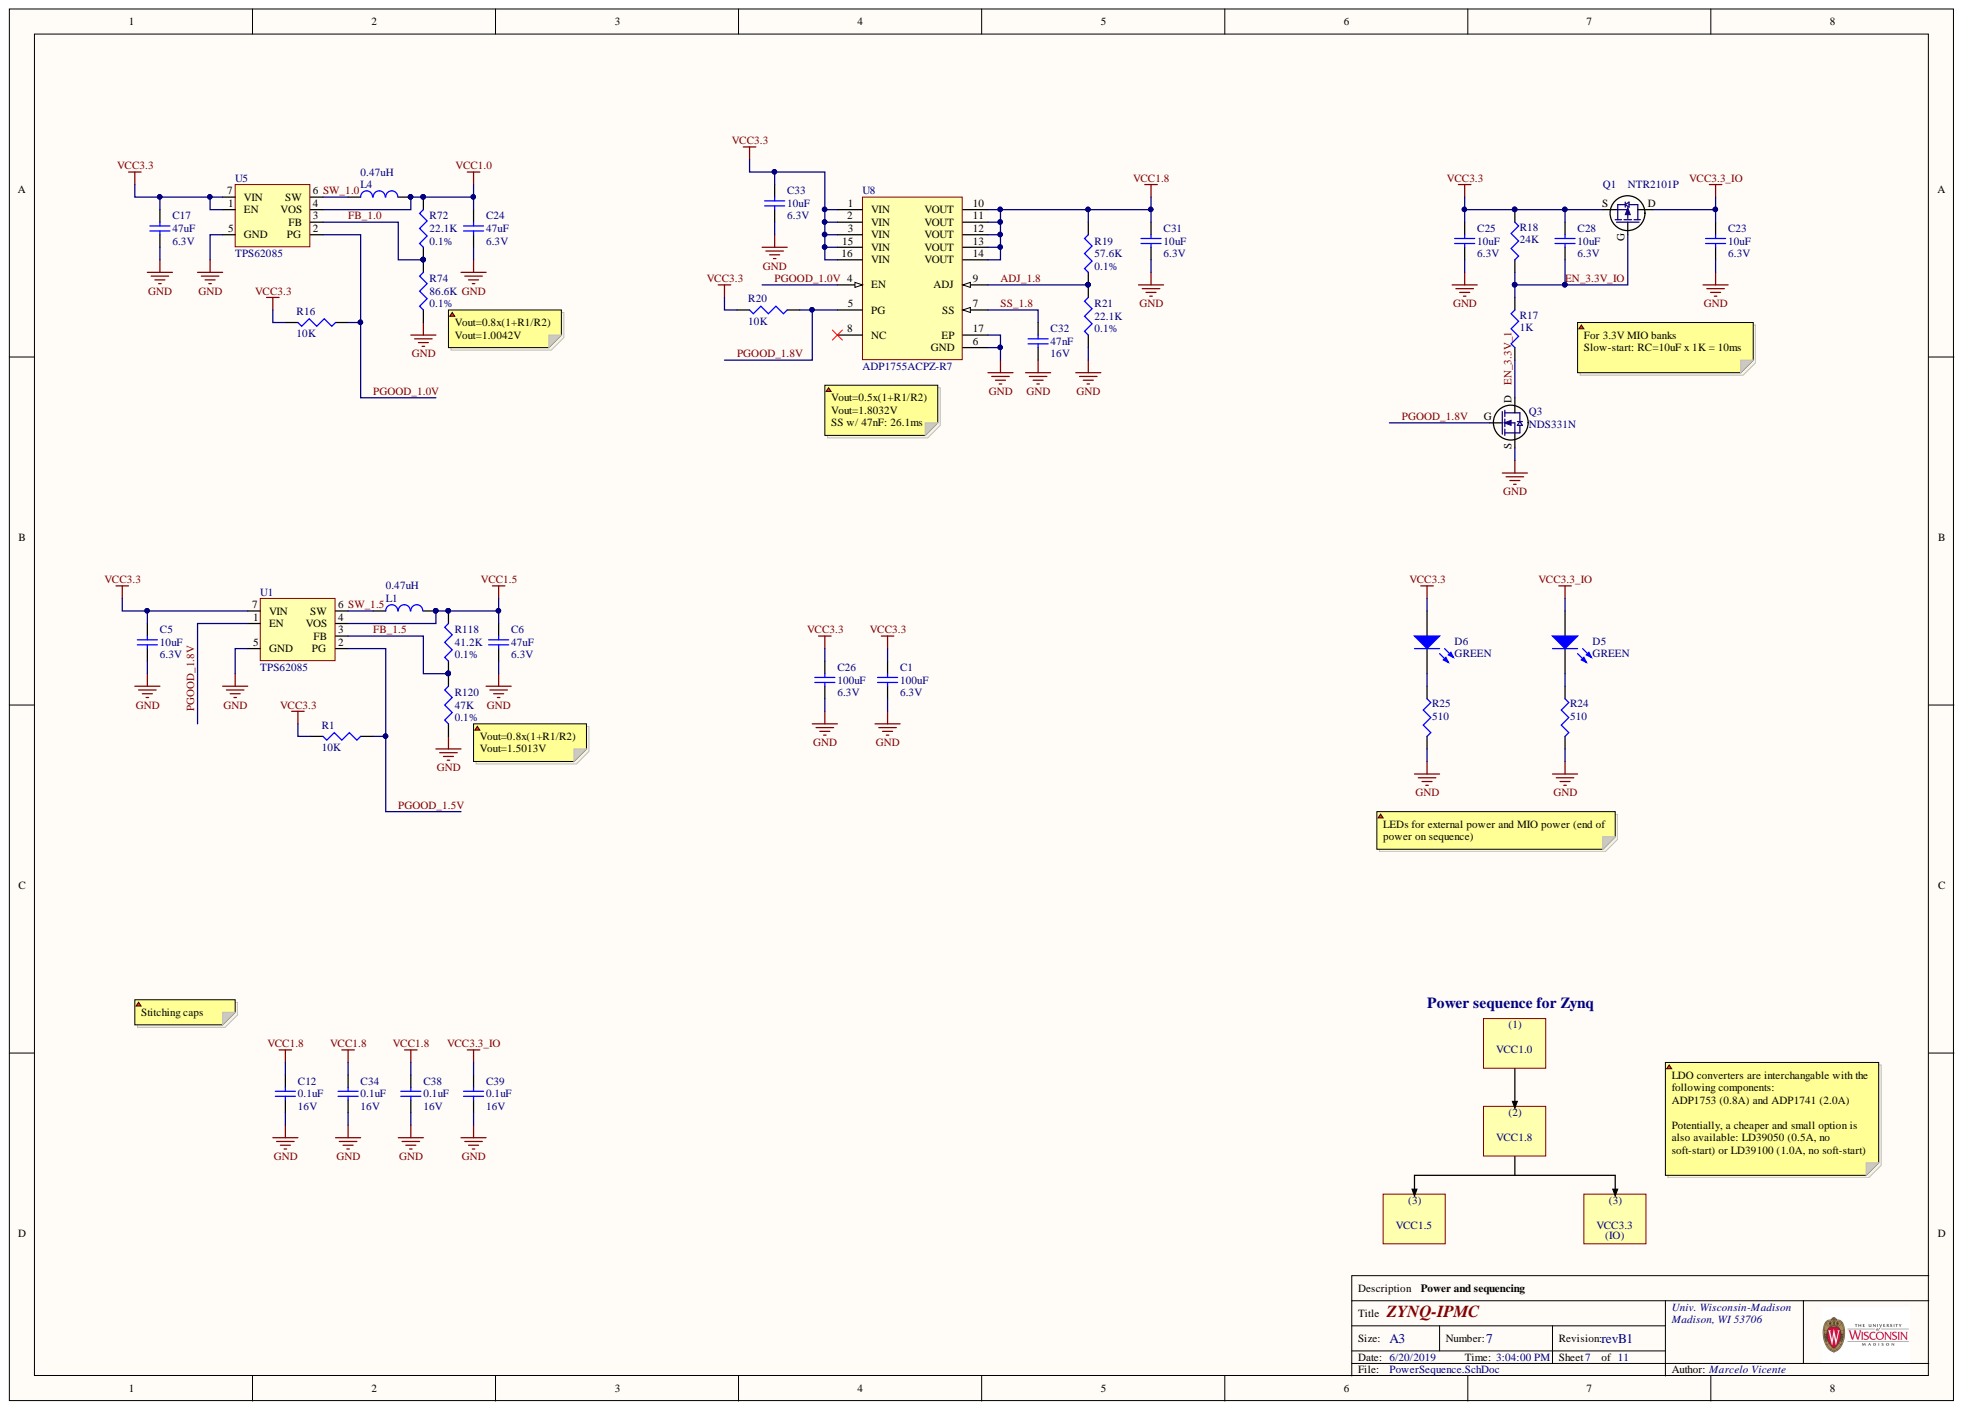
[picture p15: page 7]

LEDs for external power and MIO power (end of
power on sequence)

Power sequence for Zynq

LDO converters are interchangable with the
following components:
ADP1753 (0.8A) and ADP1741 (2.0A)

Potentially, a cheaper and small option is
also available: LD39050 (0.5A, no
soft-start) or LD39100 (1.0A, no soft-start)

6/20/2019 3:04:00 PM
PowerSequence.SchDoc

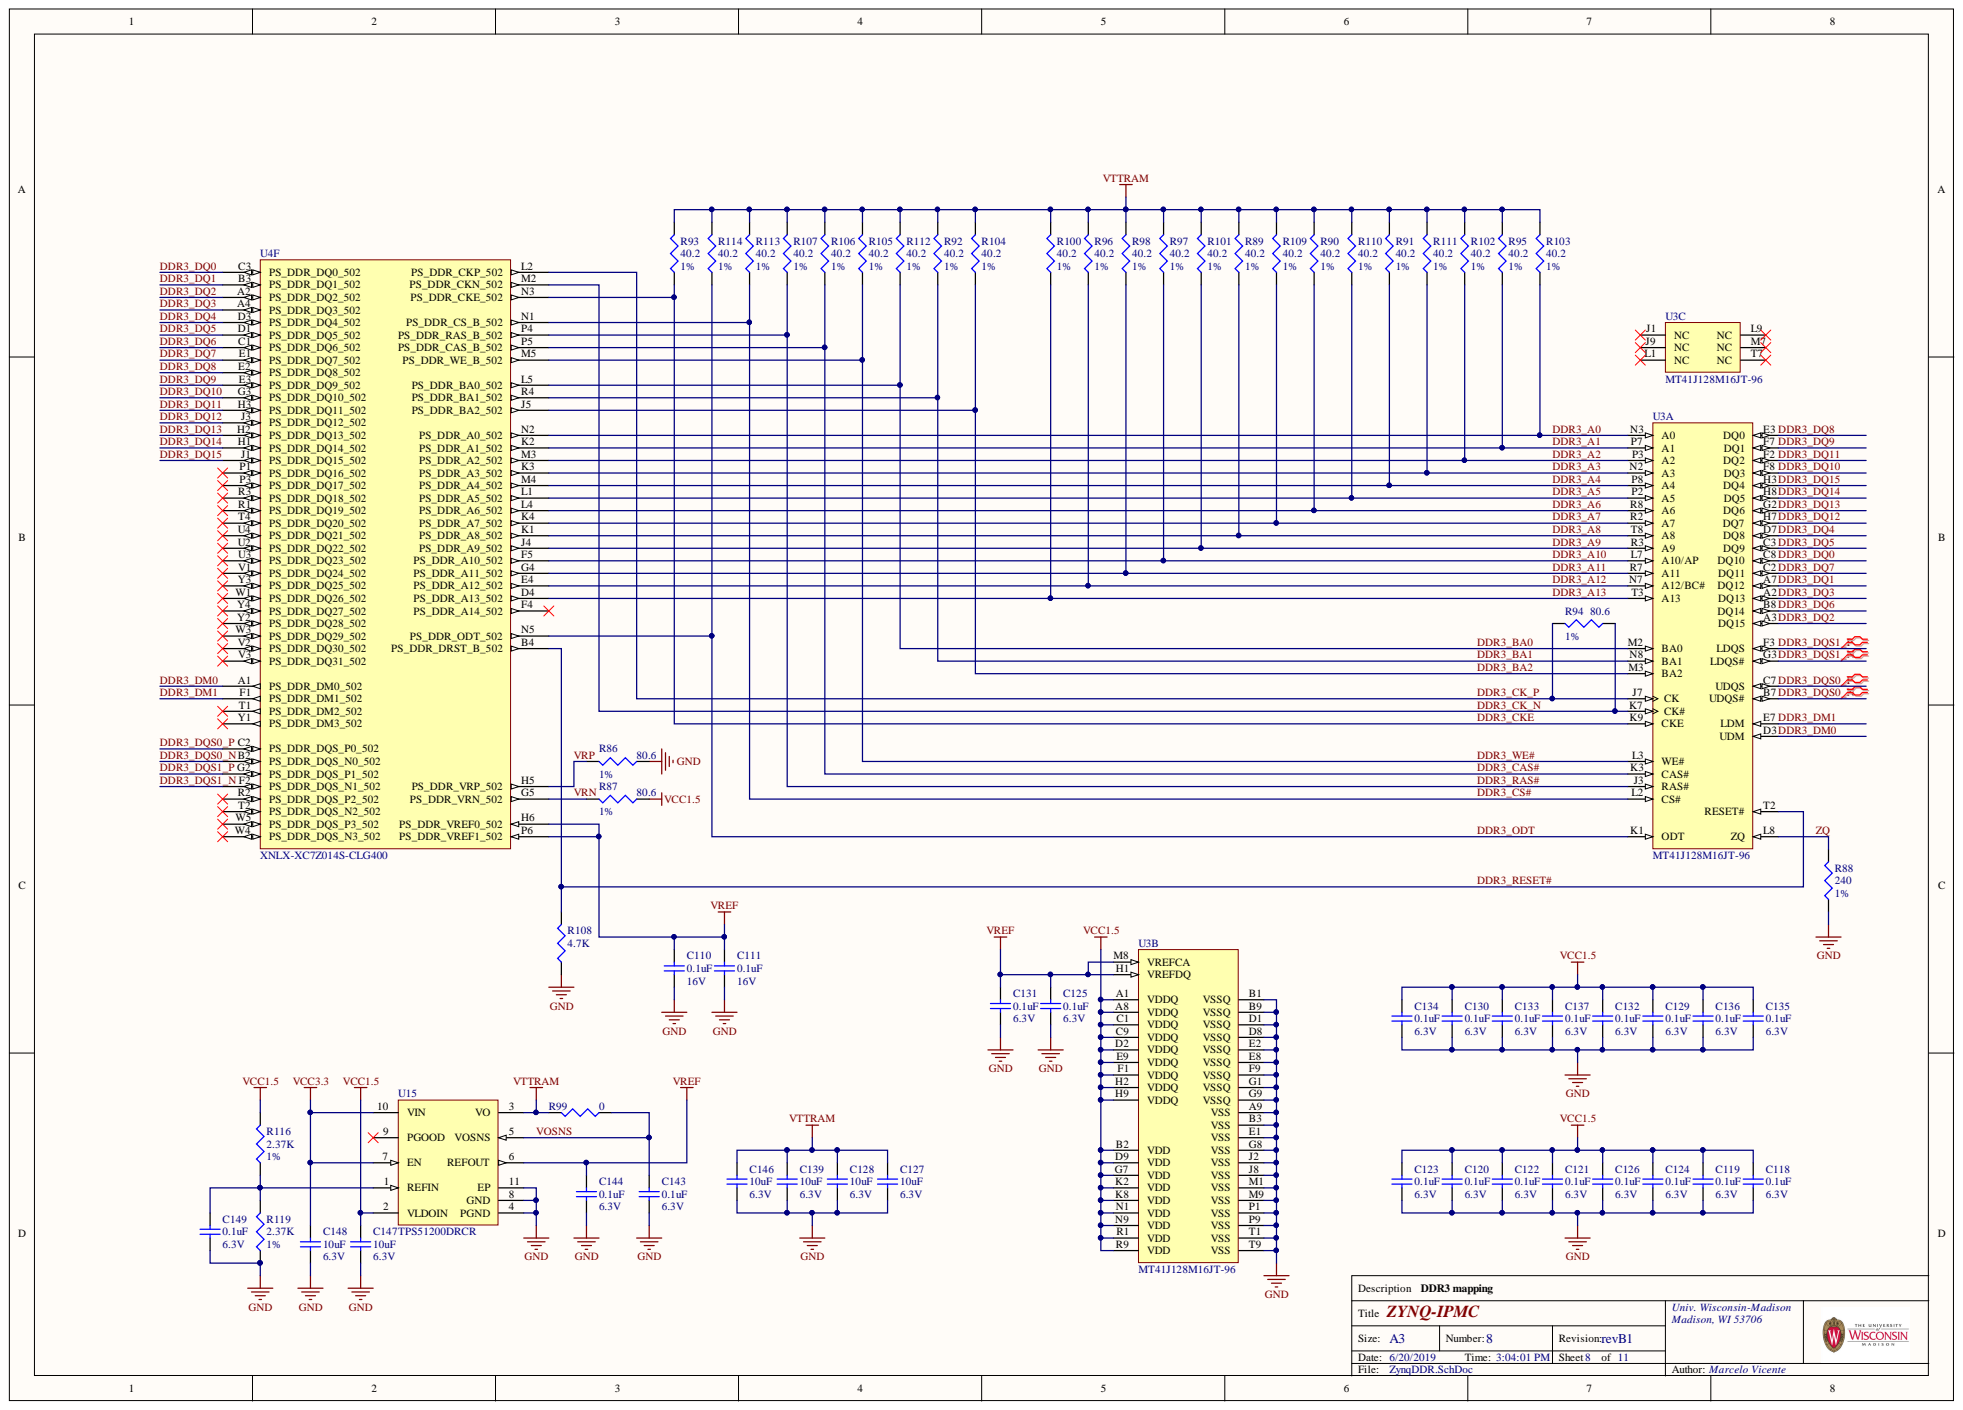
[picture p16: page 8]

DDR3_A0
DDR3_A1

DDR3_A2 | | | A2 P3 A1 P7

DDR3_A3 | | | | A3 N2
DDR3_A4 | | | | | A4 P8
DDR3_A5 | | | | | | A5 P2
DDR3_A6 | | | | | | | A6 R8
DDR3_A7 | | | | | | | | A7 R2
DDR3_A8 | | | | | | | | | A8 T8
DDR3_A9 | | | | | | | | | | A9 R3
DDR3_A10 | | | | | | | | | | | A10/AP L7
DDR3_A11 | | | | | | | | | | | | A11 R7
DDR3_A12 | | | | | | | | | | | | | A12/BC# N7
DDR3_A13 | | | | | | | | | | | | | | A13 T3

DDR3_BA0 | 1%

DDR3_BA1 | | | | BA1 N8
DDR3_BA2 | | | | BA2 M3

DDR3_CK_P | | | | CK J7
DDR3_CK_N | | | | CK# K7
DDR3_CKE | | | | CKE K9

CAS# K3

80.6 R87 VRN | DDR3_CS# VCC1.5 | CS# L2

DDR3_RAS# | | RAS# J3

1% | ODT K1

DDR3_RESET#

6/20/2019 3:04:01 PM
ZynqDDR.SchDoc

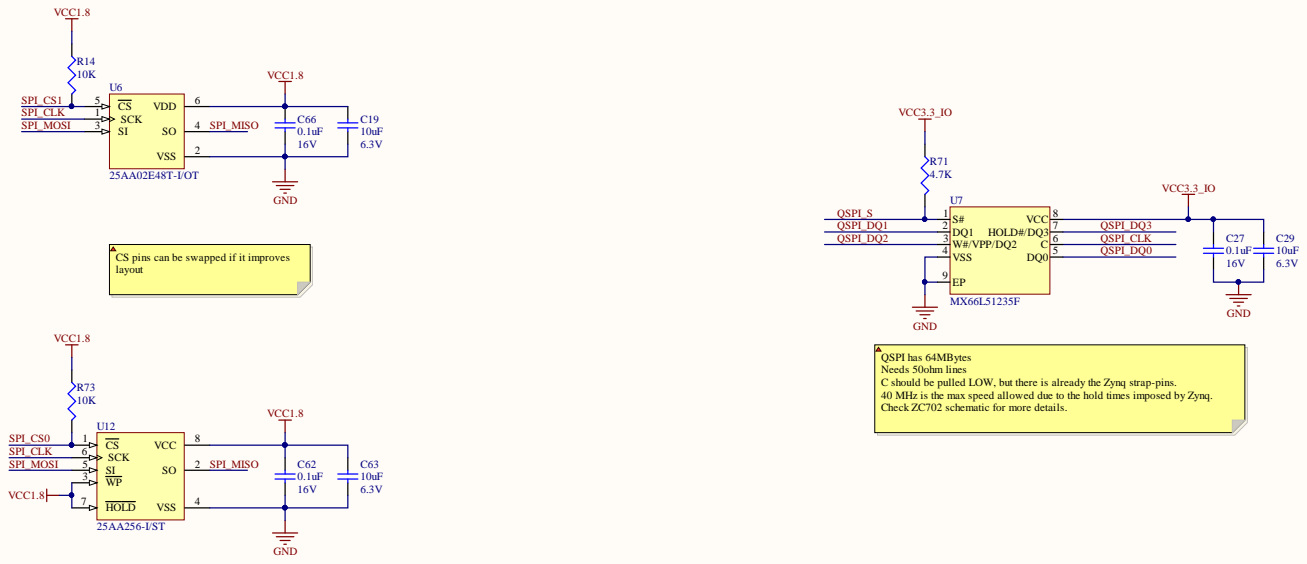
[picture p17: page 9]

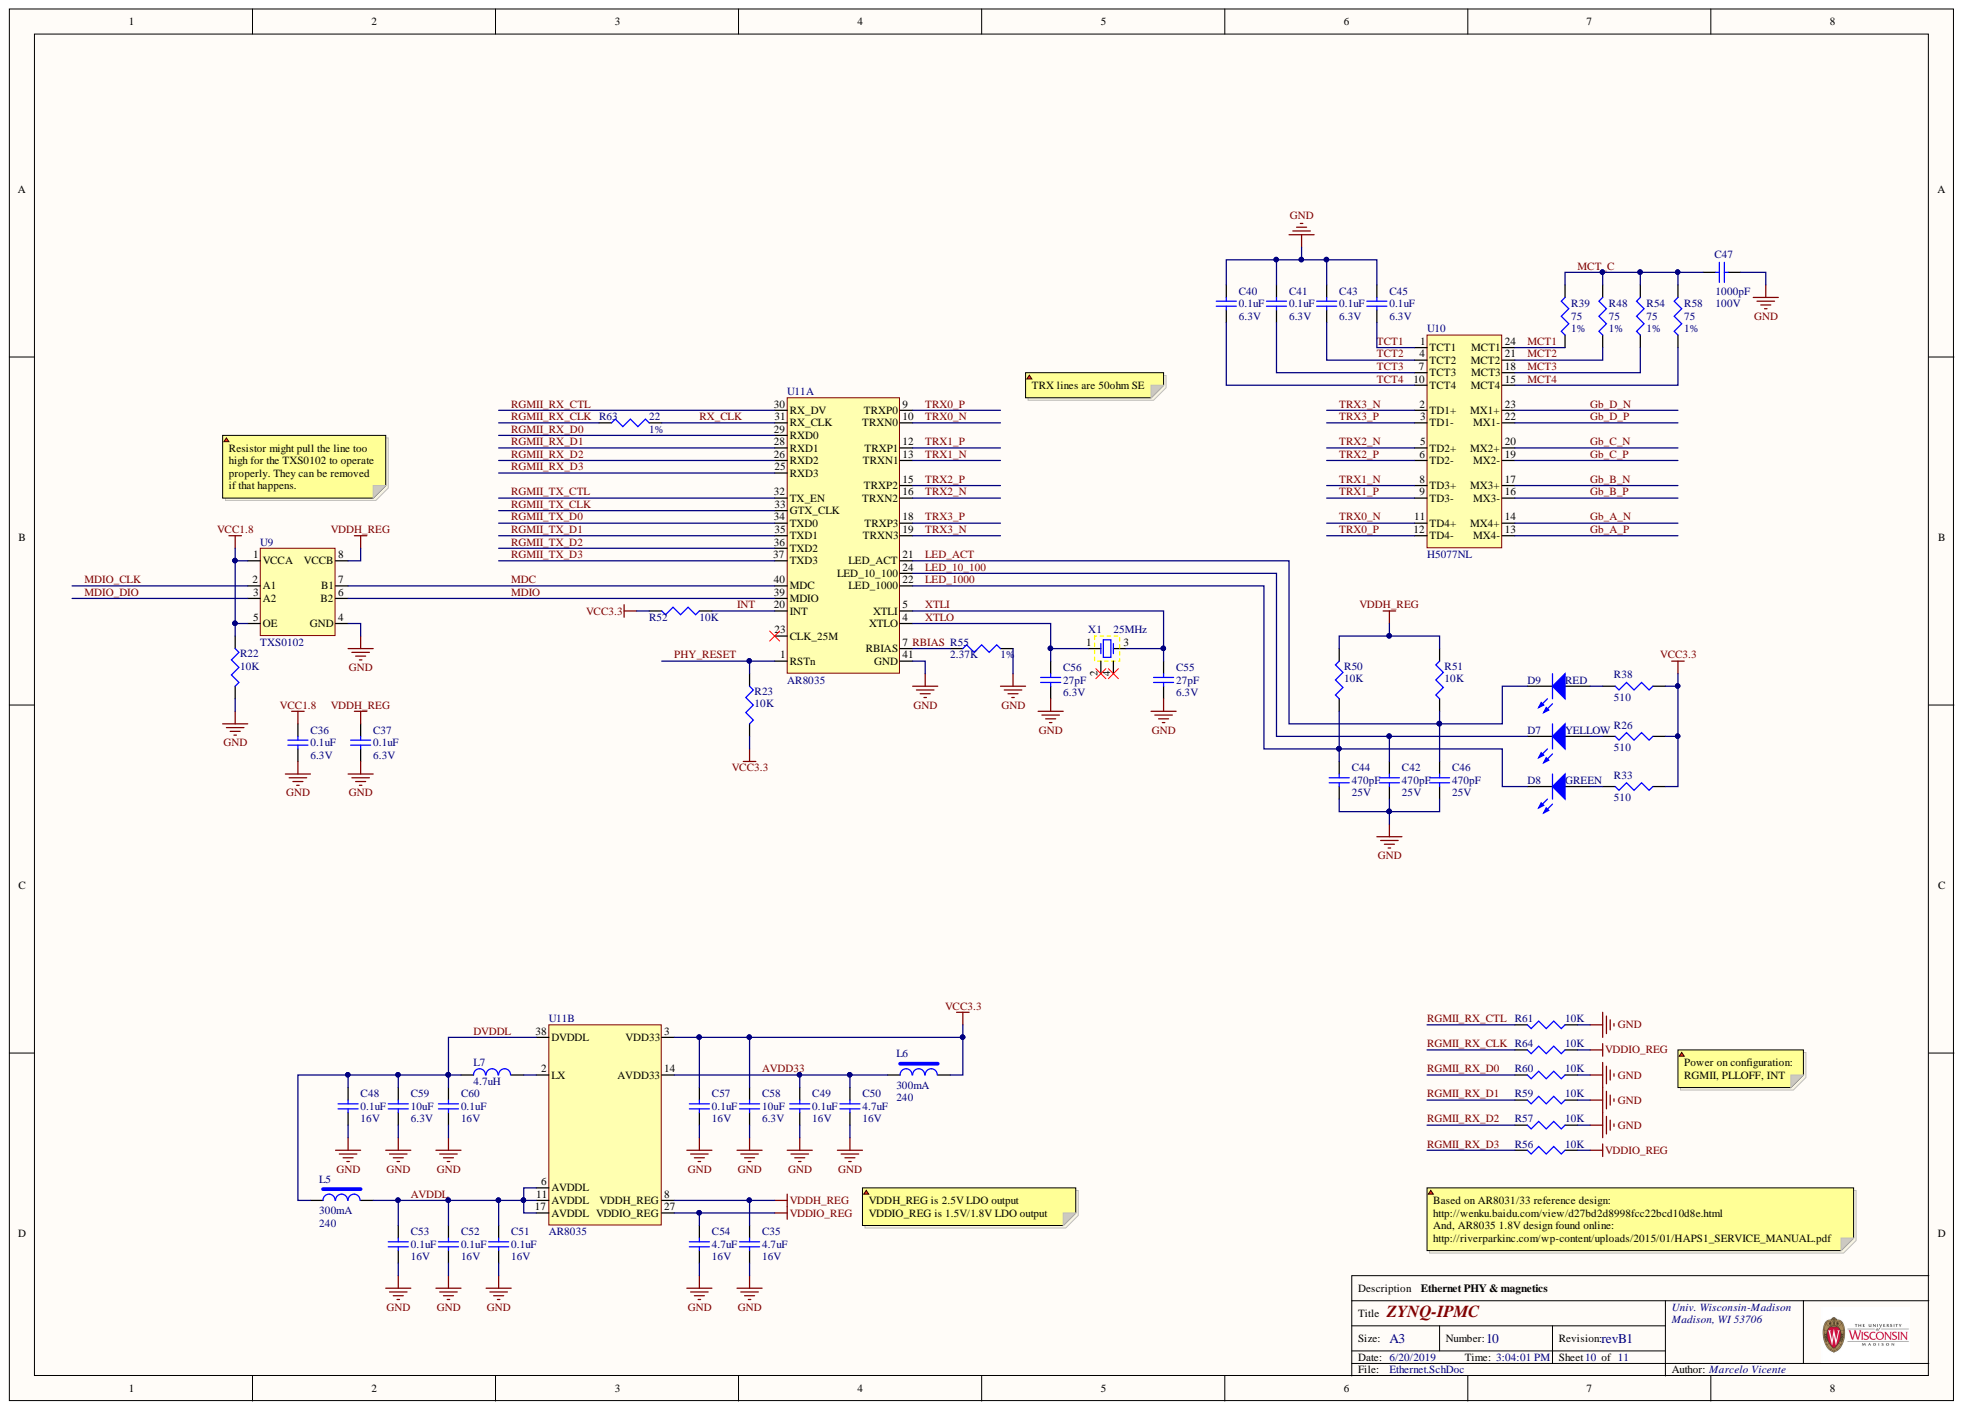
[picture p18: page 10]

TRX lines are 50ohm SE

Resistor might pull the line too
high for the TXS0102 to operate
properly. They can be removed
if that happens.

INT | INT 20

CLK_25M 23 RSTn 1 | | XTLO

470pF | 470pF | 470pF
25V | 25V

L7 | | LX 2 | | | L6 AVDD33

0.1uF | 10uF | 0.1uF | AVDDL 6 | | RGMII_RX_D1

Based on AR8031/33 reference design:
http://wenku.baidu.com/view/d27bd2d8998fcc22bcd10d8e.html
And, AR8035 1.8V design found online:
http://riverparkinc.com/wp-content/uploads/2015/01/HAPS1_SERVICE_MANUAL.pdf

6/20/2019 3:04:01 PM
Ethernet.SchDoc

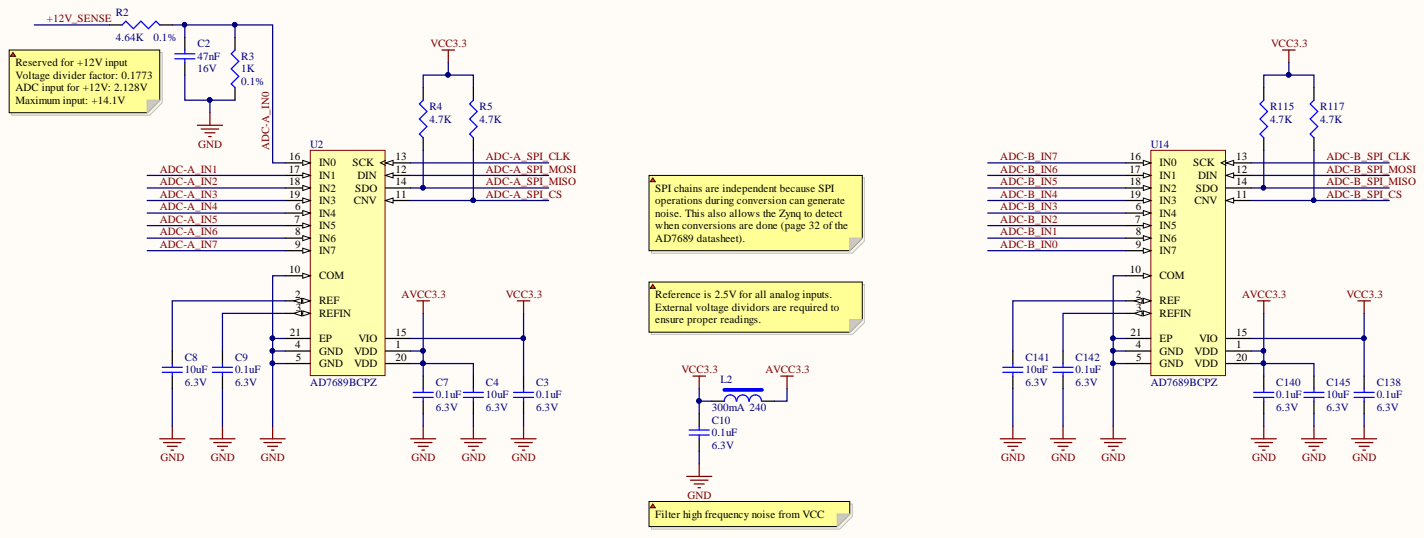
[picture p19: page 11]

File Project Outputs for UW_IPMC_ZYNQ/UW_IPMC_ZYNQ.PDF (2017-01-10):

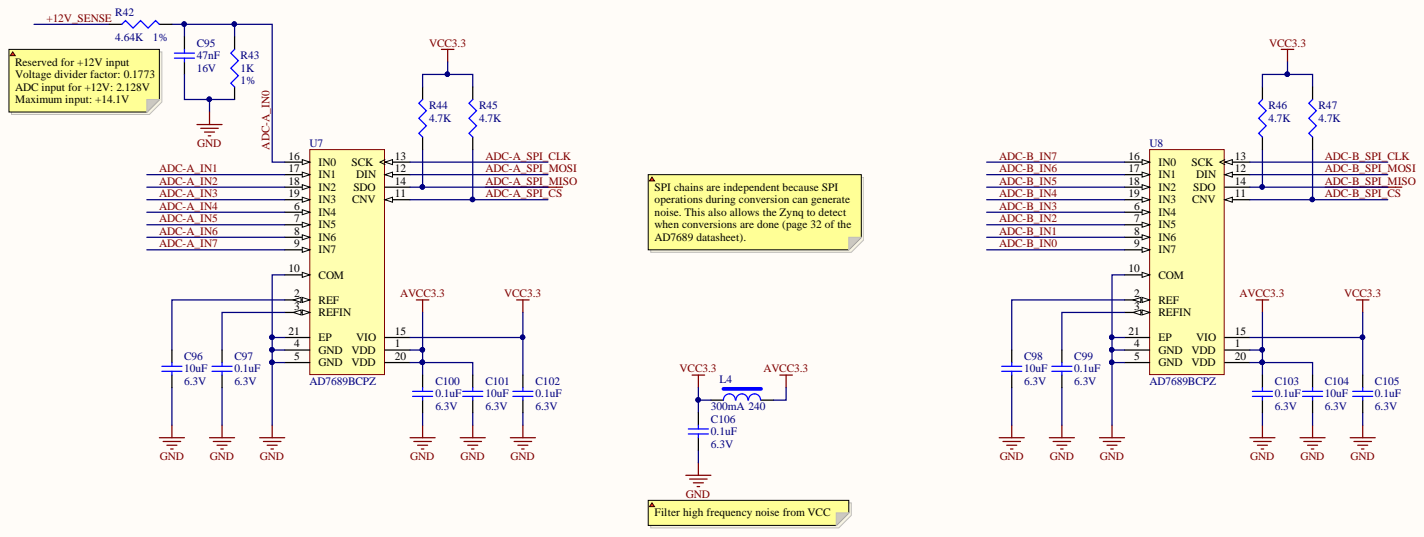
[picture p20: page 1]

SPI chains are independent because SPI
operations during conversion can generate
noise. This also allows the Zynq to detect
when conversions are done (page 32 of the
AD7689 datasheet).

GND
Filter high frequency noise from VCC

IPMC Zynq Mezzanine Title | Univ. Wisconsin-Madison Madison, WI 53706 | Cannot open file \\cern.ch\dfs\Users\m\ mpv\Desktop\Uw-ma dison-logo.png

Size: A3 | Number: * | Revision: revA
Date: 05/01/2017 Time: 16:05:28 | | Sheet * of
File: AnalogSense.SchDoc

Author: Vicente, M., Gorski., T., Tikalsky, J.


Can be populated with pull-ups if I2C i
OPE

GPI O_0
GPI O_1

IPMC Zy nq Mezzan in e T i t l | Univ. Wi scons in-Madi son son, WI 53706 | Cannot open fi le \ \cern.ch\df U ser m\ mpv\ Desktop\ w -m a di son-logo.png

Size: A | Number : | Revi s ion:

me: | | Sheet of

Fi le: | Author V icente, M., Gor


Resistor might pull the line too
high for the TXS0102 to operate
properly. They can be removed
if that happens.

Zynq will have to pull
PHY_RESET high to release
the reset line on the PHY

470pF | 470pF | 470pF
25V | 25V

0.1uF | 10uF | 0.1uF | AVDDL 6

Based on AR8031/33 reference design:
http://wenku.baidu.com/view/d27bd2d8998fcc22bcd10d8e.html
And, AR8035 1.8V design found online:
http://riverparkinc.com/wp-content/uploads/2015/01/HAPS1_SERVICE_MANUAL.pdf


s for external power and M


DDR3_A0
DDR3_A1 | | A2 P3 A1 P7
DDR3_A2
DDR3_A3 | | | | A3 N2
DDR3_A4 | | | | | A4 P8
DDR3_A5 | | | | | | A5 P2
DDR3_A6 | | | | | | | A6 R8
DDR3_A7 | | | | | | | | A7 R2
DDR3_A8 | | | | | | | | | A8 T8
DDR3_A9 | | | | | | | | | | A9 R3
DDR3_A10 | | | | | | | | | | | A10/AP L7
DDR3_A11 | | | | | | | | | | | | A11 R7
DDR3_A12 | | | | | | | | | | | | | A12/BC# N7
DDR3_A13 | | | | | | | | | | | | | | A13 T3
R28 80.6 | | | | | | | | | | | | | | | BA0 M2

DDR3_BA0
DDR3_BA1 | | | | BA1 N8
DDR3_BA2 | | | | BA2 M3

DDR3_CK_P | | | | CK J7
DDR3_CK_N | | | | CK# K7
DDR3_CKE | | | | CKE K9

CAS# K3

DDR3_RAS# | RAS# J3

DDR3_RESET#


PUDC_B should be pulled HIGH for
tri-state operation of SelectIO during
power-up


For the handle s
"Provide a r
equivalent, to connect to a Face Plate-
mm of the lower recom
in Figure D

-angle 3-pin header, such as a Molex 53780-0390 or

mended Component Side 2 keepout zone shown
ion, Pin 2 i

s the N
ly Open) contact. Note: Front Board vendor

tances to any metal connected to Shel


Zynq boot mode (MIO pins 2 to 8):
MIO[2] = b0: JTAG Cascade mode
MIO[5:3] = b100: Quad-SPI
MIO[6] = b0: PLL used
MIO[7] = b0: Bank 0 at 2.5V/3.3V
MIO[8] = b1: Bank 1 at 1.8V

SRST_B works at 1.8V.
Use converter to go from 3.3V to 1.8V.

"The Hardware Address is assigned through hardware signals
from the Backplane or Shelf to an Intelligent FRU. This Hardware
Address is assigned using seven (7) signals plus a parity line
using odd parity.
The FRU location shall indicate a logic one by leaving the address
pin floating. A logic zero shall be indicated by connecting the
address pin to the Logic Ground."
- PICMG 3.3, section 3.2.3.1

PS_LED_YELLOW | HA4
PS_LED_RED | | HA5
MDIO_CLK
MDIO_DIO | | | HA6

Zynq MIO 16-53 MIO pins (bank 501) work at 1.8V

Voltage divider to convert 3.3V to 1.65V,
good for VIH (1.8V x 0.65)


CS pins can be s
layout


H19 | T13
J 2 | U 6

D12
E15 | H10


Comment | Description | Designator | Footprint | LibRef | Qua ntity | Rat ed Curr ent | Rati ng | Tole ranc | Valu

? | Capacitor | C1, C2, C3, C4, C5, C6, C7, C8, C9, C10, C11, C12, C17, C18, C19, C20, C21, C22, C23, C24, C25, C26, C27 | C0201_IPC_H | Cap | 23 | | 6.3V | | 0.1u F

? | Capacitor | C13, C14, C15, C16, C28, C29, C30, C33, C35, C74, C96, C98, C101, C104, C120, C123, C132, C136, C137, C138, C139, C142 | C0402_IPC_H | Cap | 22 | | 6.3V | | 10u F

? | Capacitor | C31, C32, C34, C119, C121, C122, C124, C126, C127, C128, C145, C146, C147 | C0402 | Cap | 13 | | 16V | | 0.1u F

Murata GRM32ER6 0J107ME20 L | Capacitor | C36, C39, C58, C67, C78, C79, C80, C87, C90 | C1210_IPC_H | Cap | | 9 | 6.3V | | uF

? | Capacitor | C37, C40, C43, C53, C61, C62 | C0402_IPC_H | Cap | | 6 | 6.3V | | 4.7u F

Murata GRM155R6 0J474KE19 D | Capacitor | C38, C41, C50, C60, C65, C66, C69, C70, C71, C72, C73, C77, C83, C84, C85, C86, C89, C92, C93, C94 | C0402_IPC_H | Cap | 20 | | 6.3V | | 0.47 uF
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















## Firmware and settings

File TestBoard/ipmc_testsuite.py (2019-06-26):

import serial
from time import sleep
from operator import xor

MAX_GPIO = 5

IPMC_PIN_TO_GPIO_MAPPING = {
    24: 0,
    25: 2,
    26: 4,
    27: 6,
    28: 8,
    29: 10,
    30: 12,
    31: 14,
    32: 16,
    33: 18,
    35: 20,
    36: 22,
    37: 24,
    38: 26,
    39: 28,
    40: 30,
    41: 32,
    42: 34,
    43: 36,
    44: 38,
    46: 40,
    47: 42,
    48: 44,
    49: 45,
    50: 46,
    51: 47,
    52: 48,
    53: 49,
    54: 50,
    55: 51,
    63: 54,
    64: 55,
    78: 66,
    79: 68,
    81: 70,
    82: 72,
    84: 74,
    85: 76,
    87: 78,
    88: 80,
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

    # PSGPIO
    120: 128,
    121: 129,
    242: 130,
    243: 131,
}

def gpio_absn_to_interface(absn):
    return (int(absn/32), absn - int(absn/32)*32)

IPMC_TO_CTRL_PIN_MAPPING = {
    (24, 146),
    (25, 147),
    (26, 148),
    (27, 149),
    (28, 150),
    (29, 151),
    (30, 152),
    (31, 153),
    (32, 154),
    (33, 155),
    (35, 157),
    (36, 158),
    (37, 159),
    (38, 160),
    (39, 161),
    (40, 162),
    (41, 163),
    (42, 164),
    (43, 165),
    (44, 166),
    (46, 46),
    (47, 47),
    (48, 48),
    (49, 49),
    (50, 50),
    (51, 51),
    (52, 52),
    (53, 53),
    (54, 54),
    (55, 55),
    (146, 24),
    (147, 25),
    (148, 26),
    (149, 27),
    (150, 28),
    (151, 29),
    (152, 30),
    (153, 31),
    (154, 32),
    (155, 33),
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

    # I2C
    (120, 120),
    (121, 121),
    (242, 242),
    (243, 243),
}

def gpio_get_direction(serial, gpio):
    t = "gpio" + str(gpio) + ".direction\r"
    serial.write(t.encode())
    serial.readline()
    r = serial.readline()
    hex = r.split("0x")[1].split("\r")[0]
    return int(hex, 16)

def gpio_set_direction(serial, gpio, value):
    t = "gpio" + str(gpio) + ".direction " + hex(value) + "\r"
    serial.write(t.encode())
    serial.readline()

def gpio_direction_bit(serial, gpio, bit, input):
    d = gpio_get_direction(serial, gpio)
    if (input == True):
        d = d | (1 << bit)
    else:
        d = d & ~(1 << bit)
    gpio_set_direction(serial, gpio, d)

def gpio_read(serial, gpio):
    t = "gpio" + str(gpio) + ".read\r"
    serial.write(t.encode())
    serial.readline()
    r = serial.readline()
    hex = r.split("0x")[1].split("\r")[0]
    return int(hex, 16)

def gpio_read_bit(serial, gpio, bit):
    t = "gpio" + str(gpio) + ".read\r"
    serial.write(t.encode())
    serial.readline()
    r = serial.readline()
    hex = r.split("0x")[1].split("\r")[0]
    return ((int(hex, 16) & (1 << bit)) != 0)

def gpio_write(serial, gpio, value):
    t = "gpio" + str(gpio) + ".write " + hex(value) + "\r"
    serial.write(t.encode())
    serial.readline()

def gpio_write_bit(serial, gpio, bit, high):
    v = gpio_read(serial, gpio)
    if (high == True):
        v = v | (1 << bit)
    else:
        v = v & ~(1 << bit)
    gpio_write(serial, gpio, v)

def default_card(target):
    for i in range(0,MAX_GPIO):
        gpio_set_direction(target, i, 0xffffffff)
        gpio_write(target, i, 0)

def gpio_to_pin(gpio, bit):
    for pin in IPMC_PIN_TO_GPIO_MAPPING:
        p = gpio_absn_to_interface(IPMC_PIN_TO_GPIO_MAPPING[pin])
        if p[0] == gpio and p[1] == bit:
            return pin

    raise NameError("GPIO pin not found!")

def gpio_range_for_direction(direction):
    r = 0;
    for i in range(0,32):
        if direction & (1 << i):
            r += 1
        else:
            break

    return r

def run_hwaddr_test(ipmc):
    print("--RUNNING HARDWARE ADDRESS TEST--")

    tests_total = 1
    tests_passed = 0
    tests_failed = 0

    summary = []

    hwaddr = gpio_read(ipmc, 5)

    if hwaddr != 0xAA:
        tests_failed += 1
        fault = "Hardware Adress is invalid (expected 0x73, read " + hex(hwaddr) + ")"
        summary.append(fault)
        print(fault)
    else:
        tests_passed += 1

    print("--END OF TESTING--")

    return [tests_total, tests_failed, summary]

def run_pinshort_test(ipmc):
    print("--RUNNING PIN SHORT DETECTION TEST--")

    tests_total = 0
    tests_passed = 0
    tests_failed = 0

    summary = []

    # Configuration
    default_card(ipmc)

    gpio_defaults = [None] * MAX_GPIO
    for i in range(0,MAX_GPIO):
        gpio_defaults[i] = gpio_read(ipmc, i)

    gpio_ranges = [None] * MAX_GPIO
    for i in range(0,MAX_GPIO):
        gpio_ranges[i] = gpio_range_for_direction(gpio_get_direction(ipmc, i))

    for pin in IPMC_PIN_TO_GPIO_MAPPING:
        failed = False
        tests_total = tests_total + 1

        target = gpio_absn_to_interface(IPMC_PIN_TO_GPIO_MAPPING[pin])

        print("## Test " + str(tests_total) + ": IPMC pin " + str(pin))

        # print("Testing IPMC pin " + str(pin) + " (GPIO " + str(gpio) + "->" + str(target) + ")")

        gpio_direction_bit(ipmc, target[0], target[1], False)

        for polarity in [False]: # Add True to list if desired to check high polarity
            # Set pin to low and check others
            gpio_write_bit(ipmc, target[0], target[1], polarity)

            gpio_readings = [None] * MAX_GPIO
            for i in range(0,MAX_GPIO):
                gpio_readings[i] = gpio_read(ipmc, i)

            # Compare
            for i in range(0,MAX_GPIO):
                # Create mask
                mask = 0xffffffff
                if i == target[0]:
                    mask &= ~(1 << target[1])

                read = gpio_readings[i] & mask
                expected = gpio_defaults[i] & mask
                xored = read ^ expected

                if (xored != 0):
                    # Short detected, detect which ones
                    failed = True
                    for k in range(0,gpio_ranges[i]):
                        b = xored & (1 << k)
                        if b != 0:
                            p = gpio_to_pin(i, k)

                            fault = "Short detected between pin " + str(pin) + " and pin " + str(p)
                            summary.append(fault)
                            print(fault)


        gpio_direction_bit(ipmc, target[0], target[1], True)

        if failed == True:
            tests_failed += 1
        else:
            tests_passed += 1

    print("--END OF TESTING--")

    return [tests_total, tests_failed, summary]

def run_continuity_test(ipmc, ctrl):
    print("--RUNNING PIN CONTINUITY TEST--")

    tests_total = 0
    tests_passed = 0
    tests_failed = 0

    summary = []

    # Configuration
    default_card(ipmc)
    default_card(ctrl)

    for pin in IPMC_TO_CTRL_PIN_MAPPING:
        tests_total = tests_total + 1

        ipmc_gpio = IPMC_PIN_TO_GPIO_MAPPING[pin[0]]
        ctrl_gpio = IPMC_PIN_TO_GPIO_MAPPING[pin[1]]

        ipmc_target = gpio_absn_to_interface(ipmc_gpio)
        ctrl_target = gpio_absn_to_interface(ctrl_gpio)

        print("## Test " + str(tests_total) + ": IPMC pin " + str(pin[0]) + " to CTRL pin " + str(pin[1]))

        # print("Testing IPMC pin " + str(pin[0]) + " (GPIO " + str(ipmc_gpio) + "->" + str(ipmc_target) + ")")
        # print("Control IPMC pin " + str(pin[1]) + " (GPIO " + str(ctrl_gpio) + "->" + str(ctrl_target) + ")")

        gpio_direction_bit(ipmc, ipmc_target[0], ipmc_target[1], False)

        # Check high value
        gpio_write_bit(ipmc, ipmc_target[0], ipmc_target[1], True)
        rhigh = gpio_read_bit(ctrl, ctrl_target[0], ctrl_target[1])
        # if (rhigh != True):
        #     print("ipmc[dir] = " + hex(gpio_get_direction(ipmc, ipmc_target[0])))
        #     print("ipmc[val] = " + hex(gpio_read(ipmc, ipmc_target[0])))
        #     print("ctrl[dir] = " + hex(gpio_get_direction(ctrl, ctrl_target[0])))
        #     print("ctrl[val] = " + hex(gpio_read(ctrl, ctrl_target[0])))
        #     print("FAILED, expected HIGH")

        # Check low value
        gpio_write_bit(ipmc, ipmc_target[0], ipmc_target[1], False)
        rlow = gpio_read_bit(ctrl, ctrl_target[0], ctrl_target[1])
        # if (rlow != False):
        #     print("ipmc[dir] = " + hex(gpio_get_direction(ipmc, ipmc_target[0])))
        #     print("ipmc[val] = " + hex(gpio_read(ipmc, ipmc_target[0])))
        #     print("ctrl[dir] = " + hex(gpio_get_direction(ctrl, ctrl_target[0])))
        #     print("ctrl[val] = " + hex(gpio_read(ctrl, ctrl_target[0])))
        #     print("FAILED, expected LOW")

        gpio_direction_bit(ipmc, ipmc_target[0], ipmc_target[1], True)

        if (rhigh != True or rlow != False):
            fault = "IPMC pin " + str(pin[0]) + " (ctrl pin " + str(pin[1]) + ") seems "
            if (rhigh == True and rlow == True):
                fault += "to be stuck at HIGH"
            elif (rhigh == False and rlow == False):
                fault += "to be stuck at LOW"
            else:
                fault += "to show reversed readings"

            summary.append(fault)

            print("IPMC pin " + str(pin[0]) + " FAILED testing, seems " + fault)
            tests_failed = tests_failed + 1
        else:
            tests_passed = tests_passed + 1

    # Put cards in a well known state
    default_card(ipmc)
    default_card(ctrl)

    print("--END OF TESTING--")

    # print("Summary: " + str(tests_passed) + "/" + str(tests_total) + " tests passed. " + str(tests_failed) + " faults detected.")
    # for fault in summary:
    #     print("Fault: " + fault)

    return [tests_total, tests_failed, summary]

def main():
    ipmc = serial.Serial('/dev/ttyUSB0', 115200, timeout=1)
    ctrl = serial.Serial('/dev/ttyUSB1', 115200, timeout=1)

    results = [0, 0, []]

    test1 = run_hwaddr_test(ipmc)
    test2 = run_pinshort_test(ipmc)
    test3 = run_continuity_test(ipmc, ctrl)

    # Add results
    for i in [test1, test2, test3]:
        for k in range(0,3):
            results[k] += i[k]

    print("Summary: " + str(results[0] - results[1]) + "/" + str(results[0]) + " tests passed. " + str(results[1]) + " faults detected.")
    for fault in results[2]:
        print("Fault: " + fault)

    ipmc.close()
    ctrl.close()

if __name__== "__main__":
    main()

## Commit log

2016-10-26 Initial commit with connector and ADCs
    [AnalogSense.SchDoc, BoardConnector.SchDoc, CustomParts.PcbLib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]
2016-10-26 Missing schematic
    [PowerSequence.SchDoc]
2016-10-26 Symbols and schematic for the 1.0V DC-DC buck converter
    [CustomParts.PcbLib, CustomParts.SchLib, PowerSequence.CSV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]
2016-10-27 Power sequence for Zynq done and new symbols added to the custom library
    [CustomParts.PcbLib, CustomParts.SchLib, PowerSequence.SchDoc]
2016-10-28 Mid development, added symbols for ethernet controller
    [CustomParts.PcbLib, CustomParts.SchLib, Ethernet.SchDoc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]
2016-11-01 Clear separation between EMIO and MIO banks and most of the connections to PS done. Some symbols added to the custom library.
    [BoardConnector.SchDoc, CustomParts.PcbLib, CustomParts.SchLib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]
2016-11-02 Added connections to AMC slots and also most of Zynq's bank 0.
    [PowerSequence.SchDoc, TopLevel.SchDoc, UW_IPMC_ZYNQ.PrjPcb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]
2016-11-04 All banks wired to the appropriated connections based on the intended orientation of the zynq on the PCB.
    [AnalogSense.SchDoc, BoardConnector.SchDoc, CustomParts.PcbLib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]
2016-11-04 Added AR8035 to the custom library. Changed Bank 501 voltage from 2.5V to 1.8V. Removed 2.5V power elements (hopefully all of them!).
    [CustomParts.PcbLib, CustomParts.SchLib, Ethernet.SchDoc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]
2016-11-08 Wired most of the PHY chip but noticed that the MDIO interface only works at 2.5V, will revert a few things.
    [CustomParts.PcbLib, CustomParts.SchLib, Ethernet.SchDoc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]
2016-11-08 First iteration of the schematic done. Component reduction and jobs for outputs still missing.
    [BoardConnector.SchDoc, Ethernet.SchDoc, PowerSequence.SchDoc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]
2016-11-09 First iteration of the schematic complete.
    [AnalogSense.SchDoc, BoardConnector.SchDoc, Ethernet.SchDoc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]
2016-11-11 Remove once again the 2.5V converter and made sure the AR8035 receives the appropriate voltages. Also added magnetics for the ethernet.
    [CustomParts.PcbLib, CustomParts.SchLib, Ethernet.SchDoc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]
2016-11-18 Half placement done, preparing to update to Altium 17
    [AnalogSense.SchDoc, CustomParts.PcbLib, CustomParts.SchLib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]
2016-11-21 AR3085 placement almost done. Updated to Altium 17. Fixed a few problems in the schematic.
    [AnalogSense.SchDoc, CustomParts.PcbLib, CustomParts.SchLib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]
2016-11-23 Most of the DDR placed and fixed a few issues with the ethernet and DDR schematic
    [CustomParts.PcbLib, Ethernet.SchDoc, PowerSequence.SchDoc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]
2016-11-25 Most of placement done, getting ready to shuffle things around for better routing
    [AnalogSense.SchDoc, CustomParts.PcbLib, Ethernet.SchDoc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]
2016-11-25 Changed capacitors in schematic taking into account UG933 from Xilinx
    [CustomParts.PcbLib, CustomParts.SchLib, PowerSequence.SchDoc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]
2016-12-05 Placement done, will do optimizations now.
    [AnalogSense.SchDoc, CustomParts.PcbLib, CustomParts.SchLib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]
2017-01-10 Getting ready to route DDR3, will first re-arrange the components to facilitate
    [AnalogSense.SchDoc, BoardConnector.SchDoc, CustomParts.PcbLib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]
2017-01-13 Re-arranged the components to faciliate DDR3 routing and also power routing.
    [PowerSequence.SchDoc, UW_IPMC_ZYNQ.PrjPcb, ZynqDDR.SchDoc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]
2017-01-17 DDR3 control and address lines routed, still no optimizations nor timing checks.
    [ZynqDDR.SchDoc, uw_ipmc_zynq.PcbDoc]
2017-01-19 Finished second iteration of the address and control lines routing for the DDR, will start length tunning next.
    [ZynqDDR.SchDoc, uw_ipmc_zynq.PcbDoc]
2017-01-20 DDR3 fully routed and inside timing constraints, will try to optimize it even further next.
    [DDR3 board timings.xlsx, uw_ipmc_zynq.PcbDoc]
2017-01-20 DDR3 control and address lines tunned to match the clock by 10ps. Banks 1 and 0 will follow.
    [DDR3 board timings.xlsx, uw_ipmc_zynq.PcbDoc]
2017-01-23 All DDR3 traces tuned to match their respective clock groups by 10ps.
    [DDR3 board timings.xlsx]
2017-01-24 Added a bulk cap for 3.3V near the 1.5V converter. Routed all 1.5V, VCCPLL, VCCAUX power. Routed the analog and PS LEDs.
    [AnalogSense.SchDoc, Ethernet.SchDoc, PowerSequence.SchDoc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]
2017-02-03 Routed all high speed and MMC 0 to 4 signals.
    [CustomParts.PcbLib, DDR3 board timings.xlsx, Ethernet.SchDoc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]
2017-02-08 All IPMI signals and peripherals routed and timed. Only GPIOs and power missing.
    [BoardConnector.SchDoc, DDR3 board timings.xlsx, Ethernet.SchDoc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]
2017-02-21 IPMC fully routed. Split planes added, planes drawn. Missing fab notes and silkscreen.
    [AnalogSense.SchDoc, BoardConnector.SchDoc, DDR3 board timings.xlsx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]
2017-02-24 Layout complete and ready for manufacturing, still missing half of the output files which will be created next.
    [AnalogSense.SchDoc, BoardConnector.SchDoc, CustomParts.PcbLib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]
2017-03-06 Tweaked to fix a few problems and mostly increase the assembly yield.
    [AnalogSense.SchDoc, BoardConnector.SchDoc, CustomParts.PcbLib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]
2017-04-25 Cleaning up commits to tag revA
    [AnalogSense.SchDoc, Bill of Materials-UW_IPMC_ZYNQ.xlsx, CustomParts.PcbLib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]
2018-06-05 Start of work for RevB: Resolves #1: Symbol rotated and pairs swapped to facilitate routing. Minimal impact. Resolves #3: All pull-ups removed. Resolves #4: Series resistor added. Resolves #5: JTAG r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
    [AnalogSense.SchDoc, BoardConnector.SchDoc, CustomParts.PcbLib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]
2018-06-07 Resolves #10 and resolves #11: Flash replaced by Macronix MC66L51235F (512Mbit). Footprint supports a lower capacity flash (MC25L25635F). Resolves #6: Schematic symbol fixed.
    [CustomParts.PcbLib, CustomParts.SchLib, DDR3 board timings.xlsx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]
2018-06-07 Resolves #2: Solder mask as before but copper planes now go around the board edge with a 15mil pullback and stay at least 0.1mm inside the solder mask limits. Resolves #7: LED footprint silkscreen in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
    [AnalogSense.SchDoc, CustomParts.PcbLib, ZynqMIO.SchDoc]
2018-06-08 Resolves #17: Zynq changed to 7014S, which is fully pin compatible. Top and bottom silkscreen adjusted to take into account new components and shifts. DIMM connector solder mask slightly adjusted. BO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
    [AnalogSense.SchDoc, BoardConnector.SchDoc, CustomParts.PcbLib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]
2019-06-20 Fixes small bug with ethernet Xtal (rev B1). Changes project name from UW-IPMC to ZYNQ-IPMC. Include project outputs in commit.
    [AnalogSense.SchDoc, Bill of Materials-UW_IPMC_ZYNQ.xlsx, Bill of Materials-ZYNQ_IPMC.xlsx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]
2019-06-20 Removes unnecessary documents and adds hardware datasheet in docx to facilitate editing.
    [IPMC pinout.xlsx, IPMC_Pinout_v1.0.xlsx, Template.SchDoc]
2019-06-24 Updates README.md, removes GNU license (will be replaced), adds Altium lib files and cleans document folder.
    [PCB board timings.xlsx, PcbLib.PcbLib, Schlib.SchLib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]
2019-06-26 Adds teardrops and polygons that were missing after changes
    [Bill of Materials-ZYNQ_IPMC.xlsx, Pick Place for ZYNQ_IPMC.csv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]
2019-06-26 Adds TestBoard
    [Bill of Materials-IPMC_TestBoard.xlsx, CustomFootprints.PcbLib, CustomSymbols.SchLib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]
2019-10-09 Update README.md
    Adds reference to the software framework repo.
